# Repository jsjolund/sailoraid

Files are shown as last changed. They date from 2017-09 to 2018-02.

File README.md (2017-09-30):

# sailoraid
Sensor package for the Laser Pico sail boat

[BlueNRG (Old Bluetooth module) Datasheet](Docs/BlueNRG_Datasheet.pdf)

[SPBTLE (Bluetooth module) Datasheet](Docs/BlueNRG_Datasheet.pdf)

[EVA2235-H (GPS) Datasheet](Docs/EVA2235-H.pdf)

[LSM6DSL (Acc/Gyro) Datasheet](Docs/LSM6DSL.pdf)

[LSM303C (Acc/Mag) Datasheet](Docs/LSM303C.pdf)

[STM32F411 (MCU) Datasheet](Docs/STM32F411_Datasheet.pdf)

[STM32F411 (MCU) Reference Manual](Docs/STM32F411_Reference_Manual.pdf)

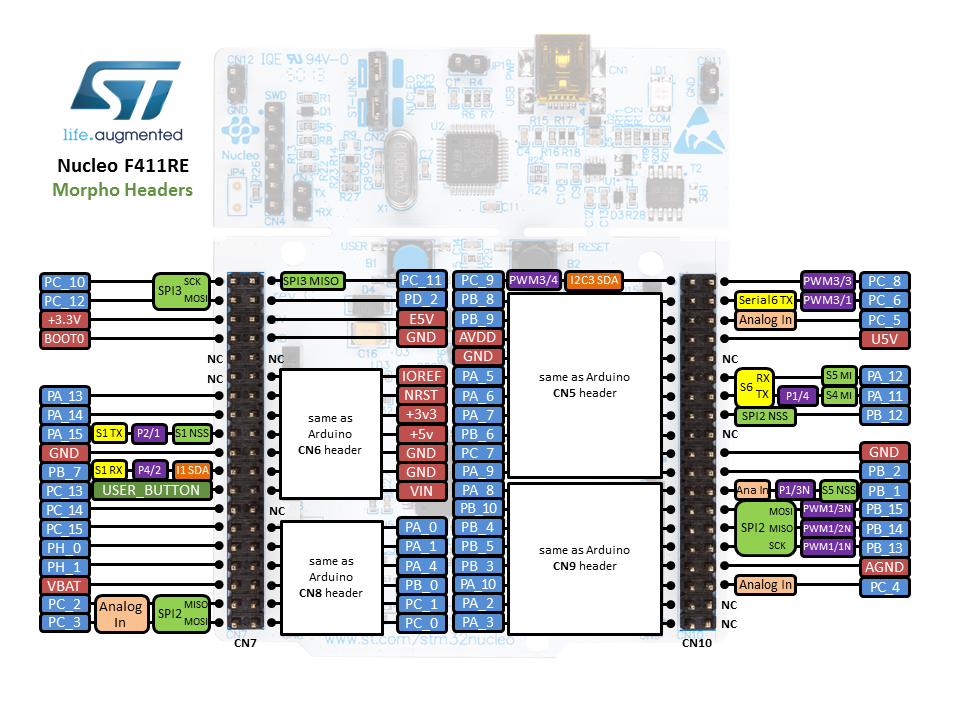
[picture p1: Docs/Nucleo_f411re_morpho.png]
Nucleo F411RE morpho pins


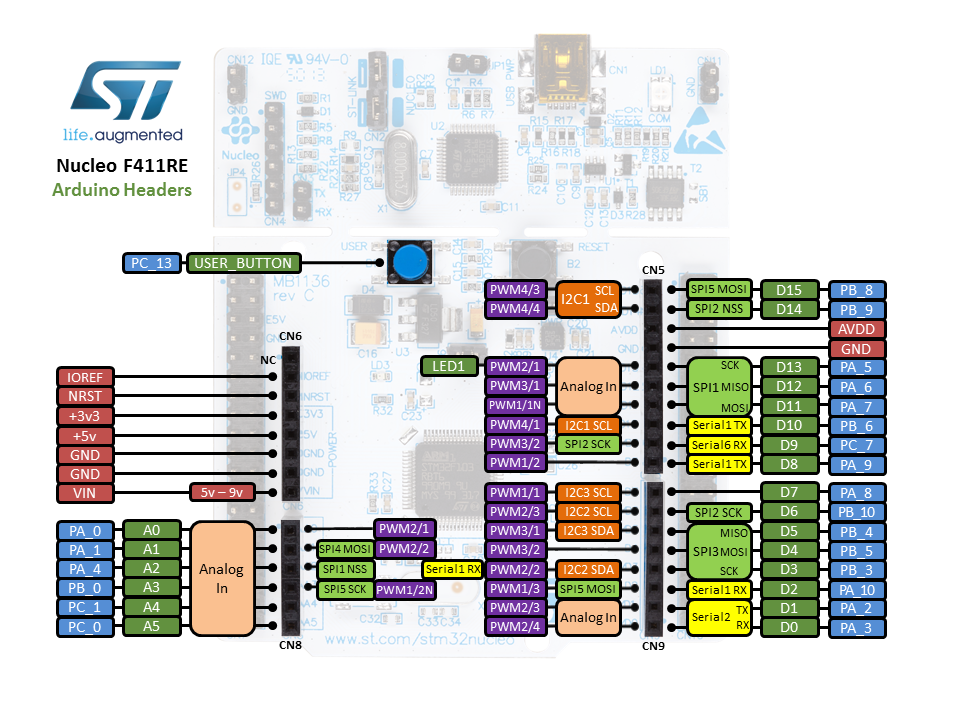
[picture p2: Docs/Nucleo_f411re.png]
Nucleo F411RE pins


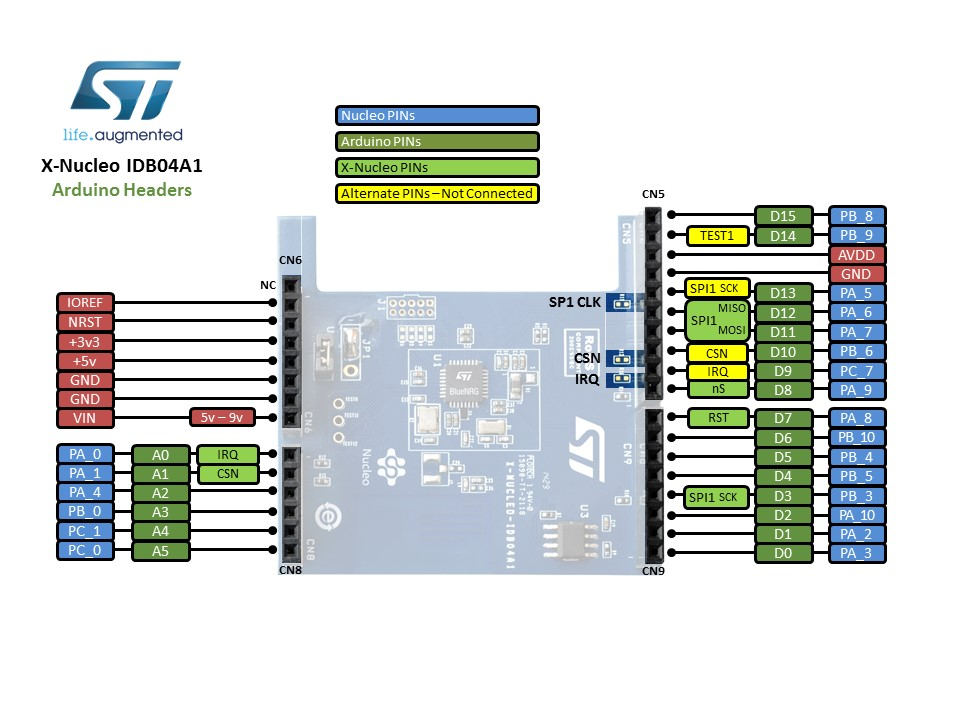
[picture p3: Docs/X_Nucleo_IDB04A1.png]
X Nucleo IDB04A1 pins


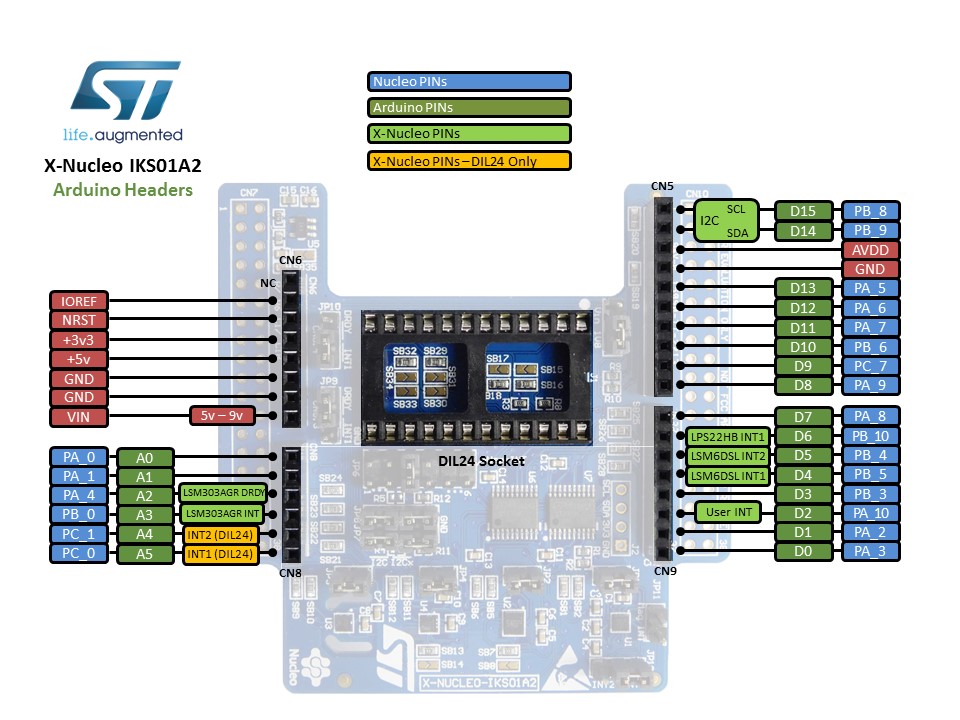
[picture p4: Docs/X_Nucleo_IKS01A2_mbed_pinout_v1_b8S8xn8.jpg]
X Nucleo IKS01A2 pins


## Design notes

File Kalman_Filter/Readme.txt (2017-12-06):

This was program was used for a dinghy (small boat), to achieve more accurate position and velocity. 

This is a program that uses an Inertial Navigation System (INS) and takes the difference between the INS and GPS data and feeds that to a Kalman filter. The error is then sent back to the INS to correct the next output. 

You can just run the code, using sim_script. But you have to link the folder "data", this since the data provided by the IMU and GPS is in that folder.
 
If you want to test with new data, open folder SERIAL_READ and run the main file. New data will be collected from the stm32,(assumed it has correct setup).
Then open folder DATA and run test_serial.m,
new vectors containing the logged data will be created, acc_x, acc_y, acc_z, gyr_x, gyr_y, gyr_z, longitude, latitude, velocity(gps), height and time. Don't forget to link the sensorLog.mat file which is created by the main file in SERIAL_READ. 
Moreover in folder DATA running data_script.m will generate calibration 
results which should be stored in calibration_res.mat.
 
Things that should be changed according to the hardware that the user uses. is the standard deviation in kalman_gps_ins.m file

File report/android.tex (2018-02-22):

\subsection{Android application}
\chapterauthor{Theolin, Henrik (Axelsson, Oskar)}
The main reason for this project is to give a sailor qualitative feedback and help in clearing the mind of the techniques required to achieve a smooth sail experience so that the sailor can focus on the joy of sailing.
A crucial part is to display the data in a manner that is easy to interpret and provide the help that the skipper needs.

To further increase the flexibility of the design, several different user layouts are implemented, that the user can switch between while running the application. This was determined to be a good way of increasing the chances that the user would find a preferable layout.

It was also determined that not only visual representation was enough, since the sailor needs to be in constant motion to counteract the forces applied on the ship by the wind and currents. This will make watching a screen to retrieve information somewhat difficult.
Other ways of representing data were implemented using text-to-speech where the sailor will get important information by sound as well as text
 Vibration is also implemented with different vibration sequences depending on different states of the ship.

\subsubsection{Software design}
A \gls{uml}\cite{uml} model of the system, see \autoref{android-uml}, was developed for an overview of the system implementation. The android system uses activities\cite{activity} to display content to the device screen. These activities have a life-cycle, see \autoref{android-activity}, that determine how data is accessed and displayed. What should be understood is that the application starts in a main activity, and switching to another activity is done by sending an intent that spawns as a child activity.
While the application is in the child activity the main activity is paused but the state is stored and when switching back from the child all data from the previous state is being accessed.
When the user returns from the child activity,  that activity is destroyed and all data is erased.
Sending data between activities is done using intents, to send an intent to a child activity is done by adding a bundle with a data object along with the intent to spawn the child activity.
Sending data back to the child activity is done by calling the method ``\emph{startActivityForResult}'', this allows the child to send a data packet as a result back to the parent. 
\begin{figure}[H]
\centering
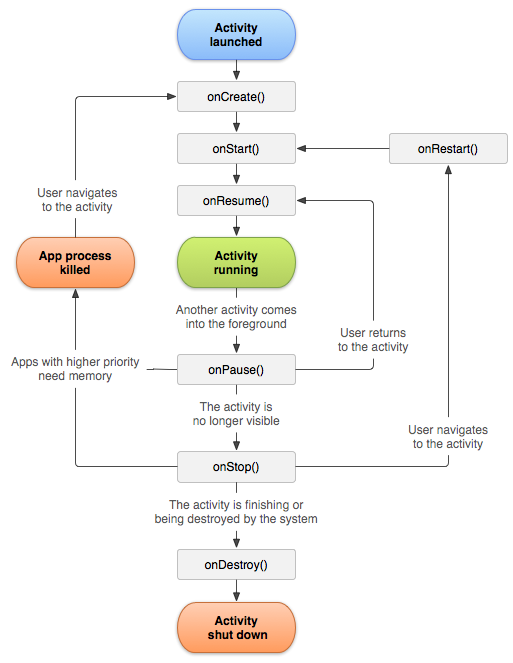
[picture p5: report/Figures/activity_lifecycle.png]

\captionsource{Activity lifecycle.}{ Author}
\label{android-activity}
\end{figure}

The Bluetooth connection and data logging class is implemented as a services\cite{android-service}. A service can be started by an activity and continue running until it is explicitly called to stop. This allows several activities to share resources and perform long-running operations in the background. The lifecycle of a service is seen in \autoref{android-service}.
\begin{figure}[H]
\centering
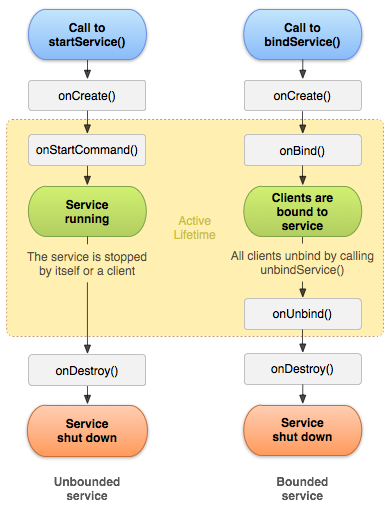
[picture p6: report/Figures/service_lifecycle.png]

\captionsource{Service lifecycle.}{Author}
\label{android-service}
\end{figure}

\subsubsection{Feedback}
For the feedback states in the application, there are some approximations, and simplifications made for easier implementation. As explained in \autoref{sec:physics}, the chapter about Physics of sailing, there are certain parameters that can be evaluated in different states of the dinghy. An extensive approximation is that there is no water movement in the implementations. The states implemented are
\begin{labeling}{alligator}
\item [Clear] - The dinghy holds good velocity and not heeling or drifting and with a good amount of pressure on the dagger-board
\item [Drift] - The dinghy is drifting perpendicular to the bearing while the dagger-board is in an upper position
\item [Heel] - The dinghy has high heel angle
\item [Reefing] - The dinghy has high heel angle and the pressure on the dagger-board is high
\item [Wrspeed] - The dinghys speed is above $65.45~\textrm{kn}$
\item [Lrspeed] - The dinghys speed is above $16.8~\textrm{kn}$
\item [Hike] - The dinghy has more then moderate heel angle and the pressure on the dagger-board is between medium and high
\item [Keelhaul] - The dinghy has an above moderate heel angle and the dagger-board is not in the lowest position
\item [Runninghigh] - The dinghy is sailing directly windwards with dagger-board high and low heel angle.
\item [Runninglow] - The dinghy is sailing directly windwards with dagger-board high and mid heel angle.
\item [Landcrab] - The dinghys speed is low.
\end{labeling}
Given these states, appropriate feedback can then be provided to the user. For handling states, a class called \emph{StateChecker} was implemented. This stores sensor values and check against limits defined at an interval that is also defined in the class. Depending on these states this class also determines what feedback that should be given.

\subsubsection{Visual Feedback}
It was determined that the visual feedback provided to the user was to include very little text information and would consist mainly of figures that changed position based on sensor data to give a good representation of what was going on with the dinghy. Because of different personal preferences, the ability to switch between different layouts is implemented. This is done by a simple swipe on the screen to toggle the view to the next layout. All layouts consists of a subset of views from the complete set including
\begin{labeling}{alligator}
\item [\ref{feedback-incline} \textbf{Incline}]  displays a ships relative incline against and artificial horizon.
\item [\ref{feedback-pressure} \textbf{Pressure}] moves a pin along a colored bar to represent high of low pressure applied on the dagger-board.
\item [\ref{feedback-compass} \textbf{Bearing}] rotates a compass to show the ship relative bearing against true north.
\item [\ref{feedback-map} \textbf{Map}] displays current location of the ship.
\item [\ref{feedback-height} \textbf{Speed}] displays a speedometer from a classical Swedish vehicle\cite{volvo} with a movable bar representing speed over ground.
\item [\ref{feedback-drift} \textbf{Drift}] is represented with a colored bar containing two arrows that moves to the relative drift direction to show the sailor if the ship was holding its set navigational reference.
\item [\ref{feedback-text} \textbf{Feedback}] a text that changes values based on the current state of the boat.
\item [\ref{feedback-sog} \textbf{Height}] of the dagger-board is represented with a visual dagger-board moving up and down along a graphical ruler.
\item [\ref{feedback-wave} \textbf{Wave frequency}] displays a wave moving towards a ship at a speed representing different period of the waves.
\end{labeling}

\begin{figure}[H] 
 	\centering
	\begin{minipage}[c]{0.6\textwidth}
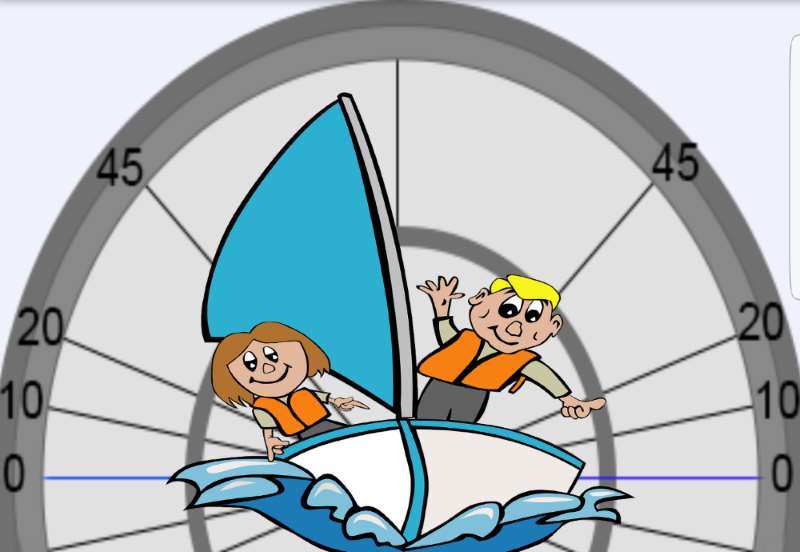
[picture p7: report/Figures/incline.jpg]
	
	\captionsource{Incline feedback view}{\url{https://pixabay.com/en/sailboat-children-playing-kid-girl-23801/}}
	\label{feedback-incline}
	\end{minipage}
	~
	\begin{minipage}[c]{.3\textwidth}
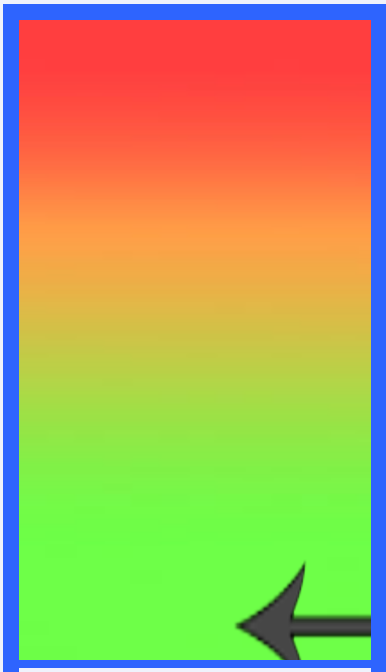
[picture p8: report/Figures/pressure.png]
	
	\captionsource{Pressure feedback view.}{Author}
	\label{feedback-pressure}
	\end{minipage}
\end{figure}
%
\begin{figure}[H]
	\centering
	\begin{minipage}[c]{0.55\textwidth}
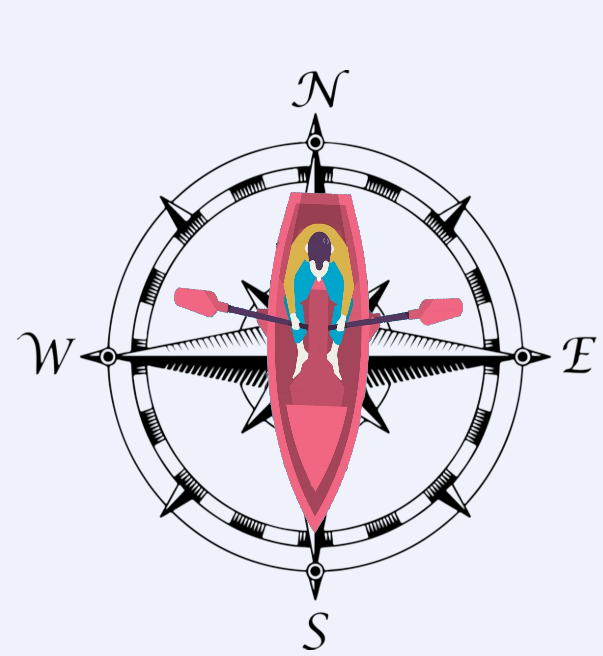
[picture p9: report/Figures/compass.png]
	
	\captionsource{Bearing feedback view.}{\url{http://www.pngall.com/compass-png}}
	\label{feedback-compass}
	\end{minipage}
	~
	\begin{minipage}[c]{0.35\textwidth}
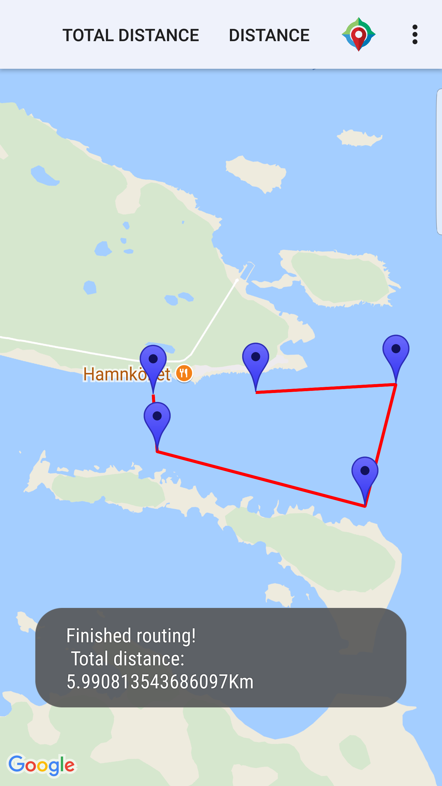
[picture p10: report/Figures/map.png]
	
	\captionsource{Map feedback view.}{Author}
	\label{feedback-map}
	\end{minipage}
\end{figure}
\begin{figure}[H]
	\centering
	\begin{minipage}[c]{0.35\textwidth}
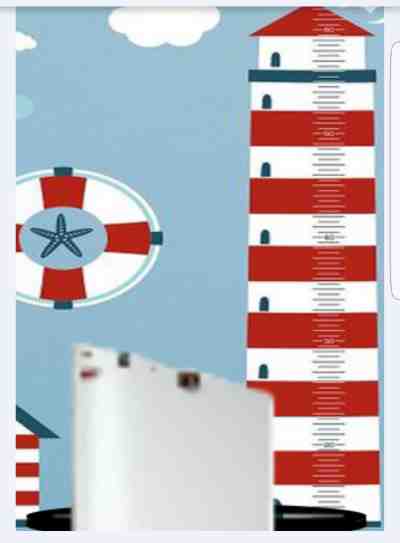
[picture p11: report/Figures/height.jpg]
	
	\captionsource{Dagger-board height view.}{\url{https://www.pinterest.se/pin/275212227218947579/}}
	\label{feedback-height}
	\end{minipage}
	~
	\begin{minipage}[c]{0.55\textwidth}
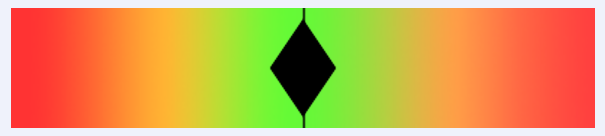
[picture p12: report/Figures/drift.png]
	
	\captionsource{Drift feedback view.}{Author}
	\label{feedback-drift}
	
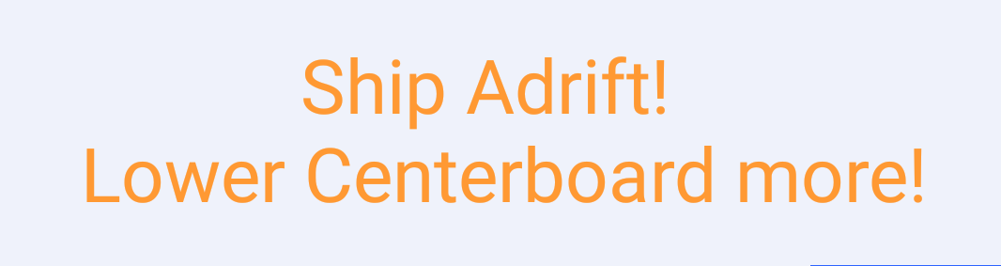
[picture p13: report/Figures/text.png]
	
	\captionsource{Text feedback view.}{Author}
	\label{feedback-text}
	\end{minipage}
\end{figure}
\begin{figure}[H]
	\centering
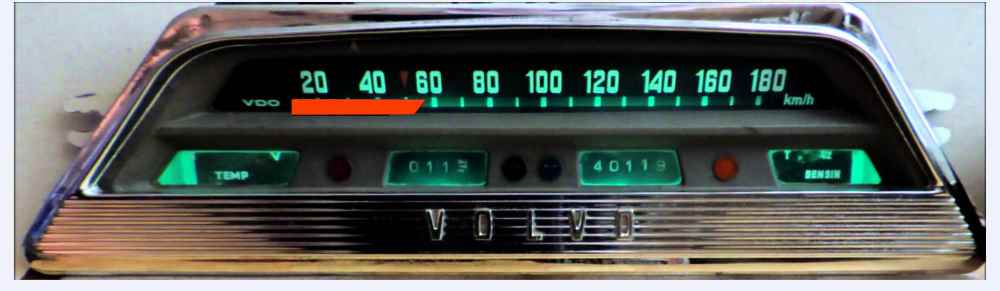
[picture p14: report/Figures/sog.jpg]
	
	\captionsource{Speed over ground view.}{\url{https://youtu.be/k8M6ZHplbIU}}
	\label{feedback-sog}
\end{figure}
\begin{figure}[H]
	\centering
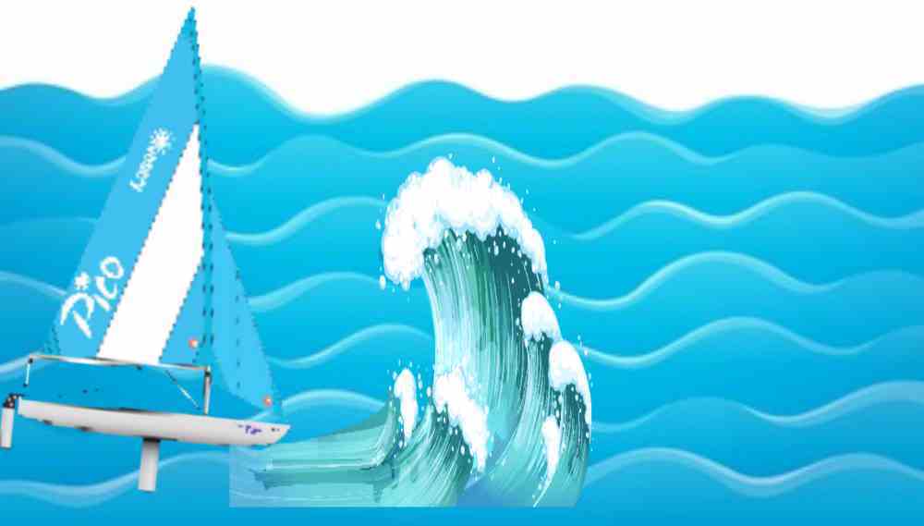
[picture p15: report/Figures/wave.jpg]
	
	\captionsource{Wave period feedback view.}{Author, Stockfresh\#2886857, Dreamstime\#33314341, \url{http://shorelinesailboats.com/product/pico/}}
	\label{feedback-wave}
\end{figure}
The figures were chosen at a development stage and improvements can easily be made by adding different \gls{png}\cite{png} files in android studio. They are implemented as \emph{GLSurfaceView}\cite{gl} so that updating the figures is be done by calling a \emph{requestRender} function, this improves the performance of the application when only updates to the figures are done when new sensor readings are received. To make the figure fit the application the \emph{GLSurfaceView} is extended into a \emph{RotatableGLView} that has the wanted features for rotation and positioning. Using these figures four different layouts are developed to give multiple choices for the user and is seen in figure \ref{feedback-layouts}. Switching between these layouts a \emph{swipeTouchListener} is implemented which allows the user to swipe across the screen to change the layout. Changing view the figures needs to be redrawn onto a new view matching the current layout, this is handled in the \emph{ViewDisplayer} class that contained all \emph{RotatableGLViews}.

\begin{figure}[H]
\centering
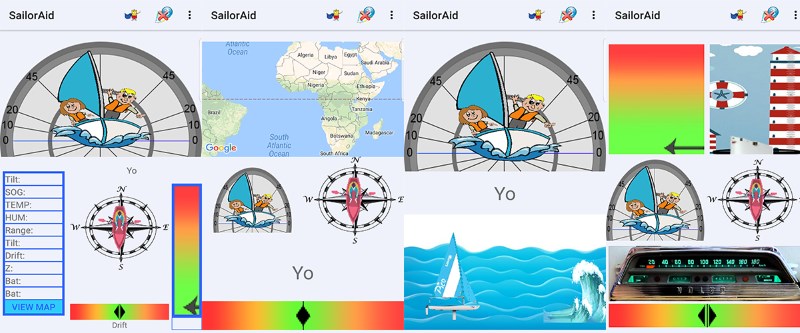
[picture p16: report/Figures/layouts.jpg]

\captionsource{Different layouts}{Author}
\label{feedback-layouts}
\end{figure}

\subsubsection{Audio feedback}
Based on values from the sensors, different states are implemented and for each state, a text is read out to the user. The feedback is implemented such that the audio feedback would continue even if the device is put into sleep mode. Handling the text to speech feature a \emph{Text-to-Speech}\cite{texttospeech} class is implemented as an inner class in \emph{StateChecker}. To prevent the speech to be interrupted preemptively an \emph{UtteranceProgressListener}\cite{utter} is used. 

\subsubsection{Haptic feedback}
Based on the same states as the audio feedback vibration is also implemented. The frequency and length of the vibrations are implemented in such a way each state has a unique signature that can be recognized by the sailor after some practice with the system. Handling the interval an \emph{IntervalVibrator} is implemented and run by the \emph{StateChecker}.

\subsubsection{Log}
The ability to analyze the sailing trip was determined to be an important feature for the user, so a logging function is implemented so data can be stored in the device internal storage. This is handled by the \emph{SailLog} class and these files can be read or deleted at a later stage, by the user. Storing a log is implemented such that the sailor would need to start a logging session after Bluetooth connection has been established to the ship. After the log is started it creates a file on the device internal storage and writes sensor data to the file at the same frequency as the data is transmitted by the system. While logging is active the device would continue to store information even if the device is put in sleep mode so that the sailor could choose to only log data and not view the information displayed on the screen. After the sailing trip is finished the sailor can read the saved log file and receive a summary of the trip (\autoref{log-summary}). More information from the log can be analyzed by reading graphs (\autoref{log-graph}) where the sensor data is shown with respect to time. These graphs are implemented such that the user is able to choose what graphs to be displayed on the device for improved comparability.
\begin{figure}[H]
	\centering
	\begin{minipage}[t]{0.3\textwidth}
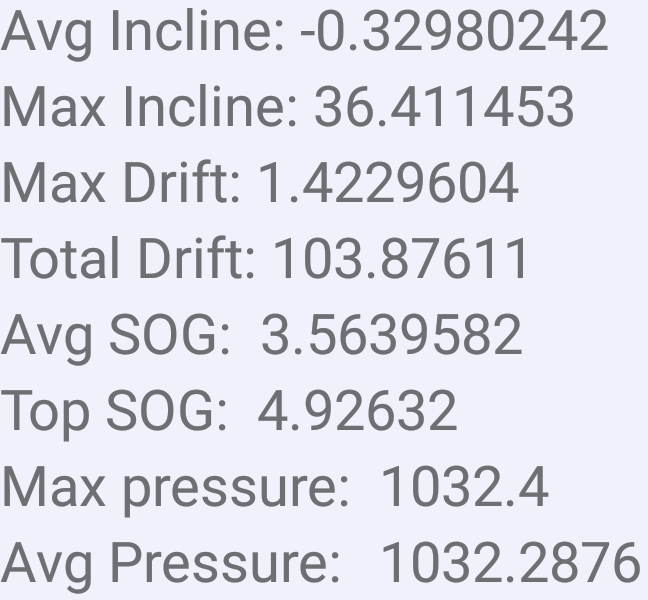
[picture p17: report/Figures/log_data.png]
	
	\caption{Log data summary example.}
	\label{log-summary}
	\end{minipage}
	~
	\begin{minipage}[t]{0.6\textwidth}
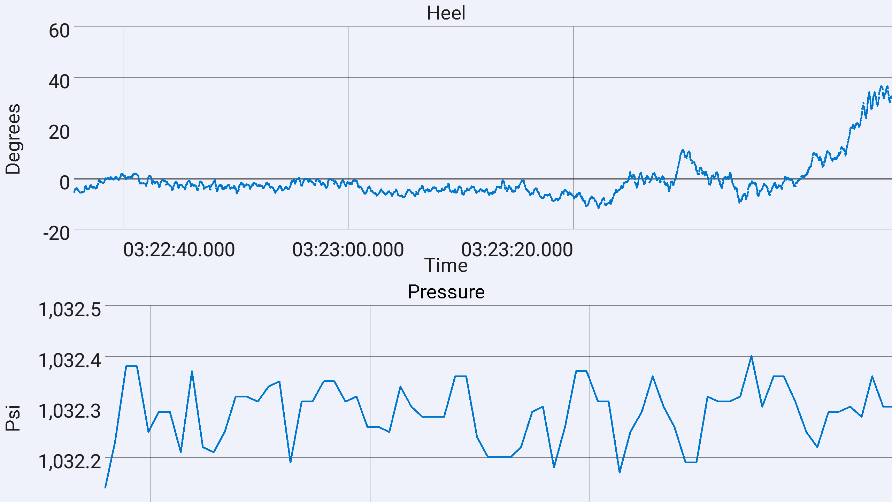
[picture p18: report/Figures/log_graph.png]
	
	\caption{Log graphs examples.}
	\label{log-graph}
	\end{minipage}
\end{figure}

\subsubsection{Bluethooth connection}
A list of all devices in the nearby area is displayed when the user decides to connect to the system, this adds flexibility to the user and allows for connection between multiple systems with different \gls{mac}. Scanning for nearby devices is done in the \emph{MainAcivity} and handled by the \emph{BTHandler} class. The application uses Bluetooth low energy technology to match the system implementation. This allows the device to receive notifications when the data is altered on the system and updates occurs in different frequencies for different types of data. To ensure a stable connection between the system and the device the connection class is implemented as an android service\cite{android-service}. This allows the device to keep the connection alive between different views and even when the device is put into sleep mode. All functionality regarding connecting and receiving data is implemented in the \emph{BTLEConnection} class and known characteristics and the determined unique GATT service identifiers are stored in the \emph{SampleGattAttributes} class.

\subsubsection{Map}
For the sailor to get more information about location two maps are implemented, one that is embedded into a layout in the \emph{FeedbackActivity} and the functionality of this is handled in the \emph{MapRunner} class, the other map is implemented in \emph{MapsActivity}. This could be improved by using the same class for both maps to achieve better readability and modifiability of the code. Both these implementations utilized the Google maps \gls{api}\cite{gmaps}, which can be used freely and the map service is highly accurate and suits our system well. Interaction with the maps can also be made quite easy which helped to make development faster. The sailor has the ability to see a path over the trip and the total distance traveled. Waypoints can be placed if the sailor wants to plan a certain trip in advance. The distance of the trip and the distance currently traveled is displayed to give the \gls{skipper} information on how long the trip is and how much of the trip is left to be sailed. A path to the nearest waypoint is shown to help navigation. When the sailor is close to the first waypoint the path to the next waypoint is shown. The waypoint route can also be viewed in the map of the \emph{FeedbackActivity} layout.

\subsubsection{Drift}
Calculating leeward drift is done by measuring the distance from an estimated destination point and the position received from the \gls{gps}. By using the \gls{gps} position and the ships bearing from the systems magnetometer a \textit{rhumb line}\cite{rhumb-line} is derived and the new estimated position is calculated with
%δ = d/R	(angular distance)
%φ2 = φ1 + δ ⋅ cos θ	
%Δψ = ln( tan(π/4 + φ2/2) / tan(π/4 + φ1/2) )	(‘projected’ latitude difference)
%q = Δφ/Δψ (or cos φ for E-W line)	
%Δλ = δ ⋅ sin θ / q	
%λ2 = λ1 + Δλ
\begin{align*}
  &\begin{aligned}
  \delta &= d/R 
  \end{aligned}\\
 &\begin{aligned}
  \varphi_2 &= \varphi_1 + \delta \cdot \cos{\theta}
  \end{aligned}\\
 &\begin{aligned}
  \Delta\psi = \ln { \bigg( \tan{\frac{n}{4} + \frac{\varphi_2}{2}} \bigg/ \tan{\frac{n}{4} + \frac{\varphi_1}{2}} \bigg)}
  \end{aligned}\\
 &\begin{aligned}
  q = \frac{\Delta\varphi}{\Delta\varphi}
  \end{aligned}\\
 &\begin{aligned}
  \Delta\lambda = \delta\cdot\sin\frac{\theta}{q}
  \end{aligned}\\
 &\begin{aligned}
  \lambda_2 = \Delta\lambda_1 + \Delta\lambda
  \end{aligned}\\
\end{align*}
where $R$ is the Earth's radius, $d$ is the distance traveled, $\theta$ is ships bearing, $\lambda_1$ and $\varphi_1$ is the point of origin in longitude and latitude. This new estimated position $\lambda_2$ and $\varphi_2$ is then compared to the next positional data from the \gls{gps} and the distance between these points is calculated using \emph{Equirectangular projection}\cite{equirectangular}.
%x = Δλ ⋅ cos φm
%y = Δφ
%d = R ⋅ √x² + y²
\begin{align*}
  &\begin{aligned}
  x = \Delta\lambda \cdot \cos\frac{\Delta\varphi}{2}
  \end{aligned}\\
 &\begin{aligned}
  y = \Delta\varphi
  \end{aligned}\\
 &\begin{aligned}
  d = R\cdot\sqrt{x^2+y^2}
  \end{aligned}\\
\end{align*}
where $\Delta\lambda$ and $\Delta\varphi$ are the differences in longitude and latitude for two location points. This function has high performance gain but is less accurate over large distances then, e.g., the \emph{Haversine formula}\cite{haversine}. Since for this function, only small changes in distance are calculated the accuracy is more than adequate. A problem with this way of calculating leeward drift is the accuracy of the \gls{gps} readings and to get a good bearing the idea was to make use of the magnetometer though the accuracy of that is also far from perfect. This combined with the fact that a small deviation of a couple of degrees results in a large drift resulted in large errors in leeway drift. The solution was to use the directional data sent from the \gls{gps} module which calculates direction based on last positional data. This solution works well for progress in the forward direction and when fast sideways motion is detected the estimated position will be along the same vector as the previous direction. However, for constant drift sideways this approach will display that no drift was taking place. This calculation is handled by the \emph{Locator} class.

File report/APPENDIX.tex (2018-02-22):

\section{Large Figures}\label{sec:app}

\subsection{Schematic of sensorboard}\label{app:schemmain}
%Image of schematic(s) (Rev 3)
\begin{figure}[h]
	\centering
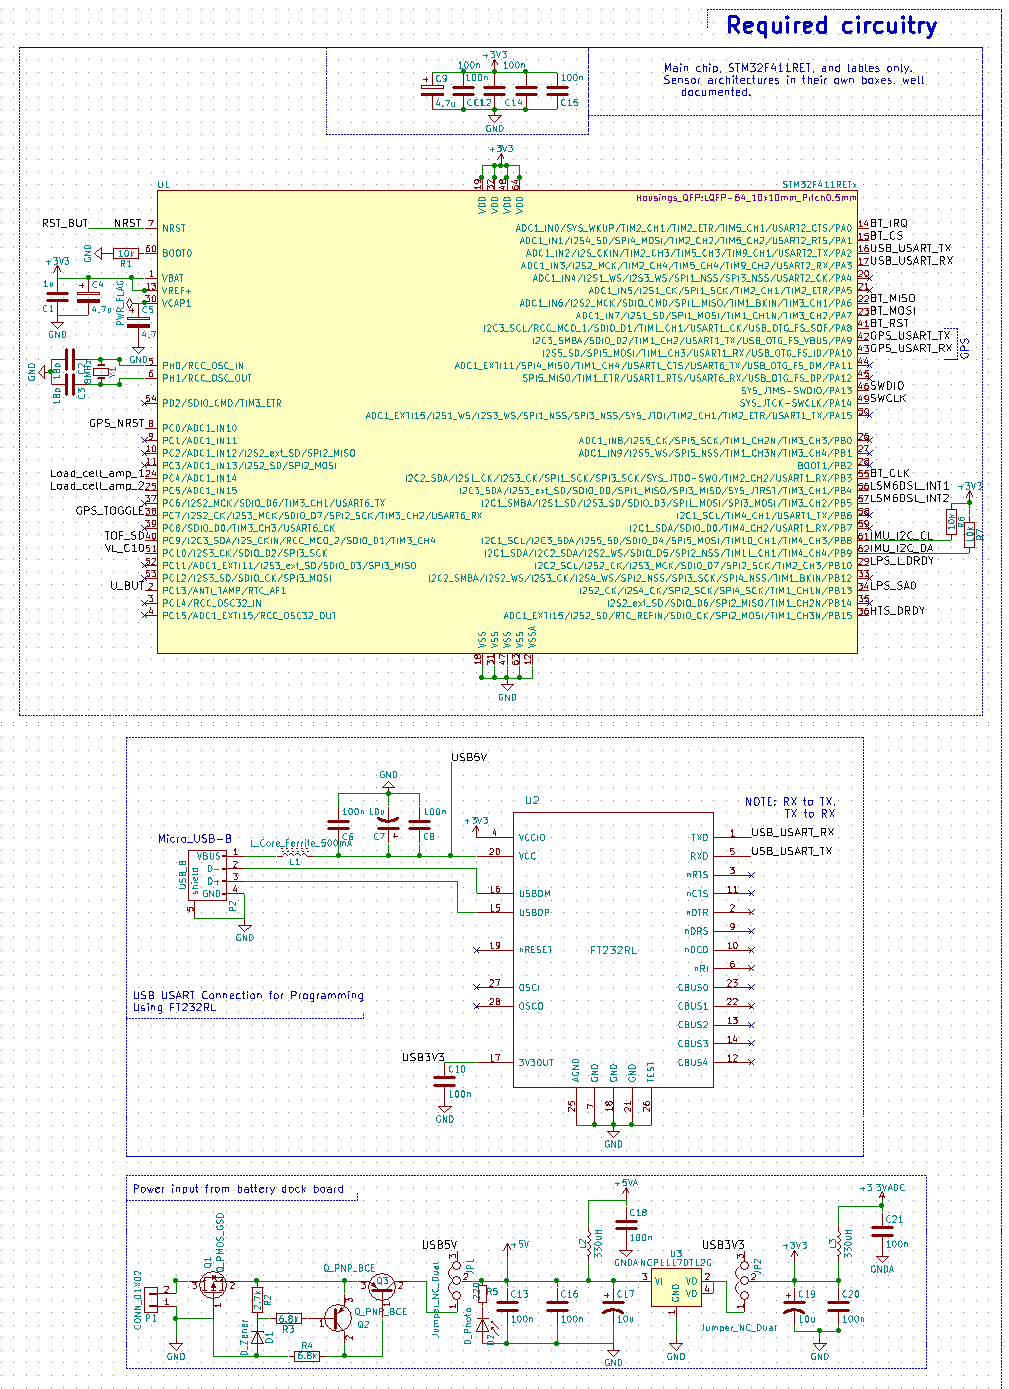
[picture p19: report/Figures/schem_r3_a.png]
    
	\captionsource{Schematic of revision 3, part a: Required circuitry.}{Author}
	\label{fig:schr3a}
\end{figure}
\begin{figure}[h]
	\centering
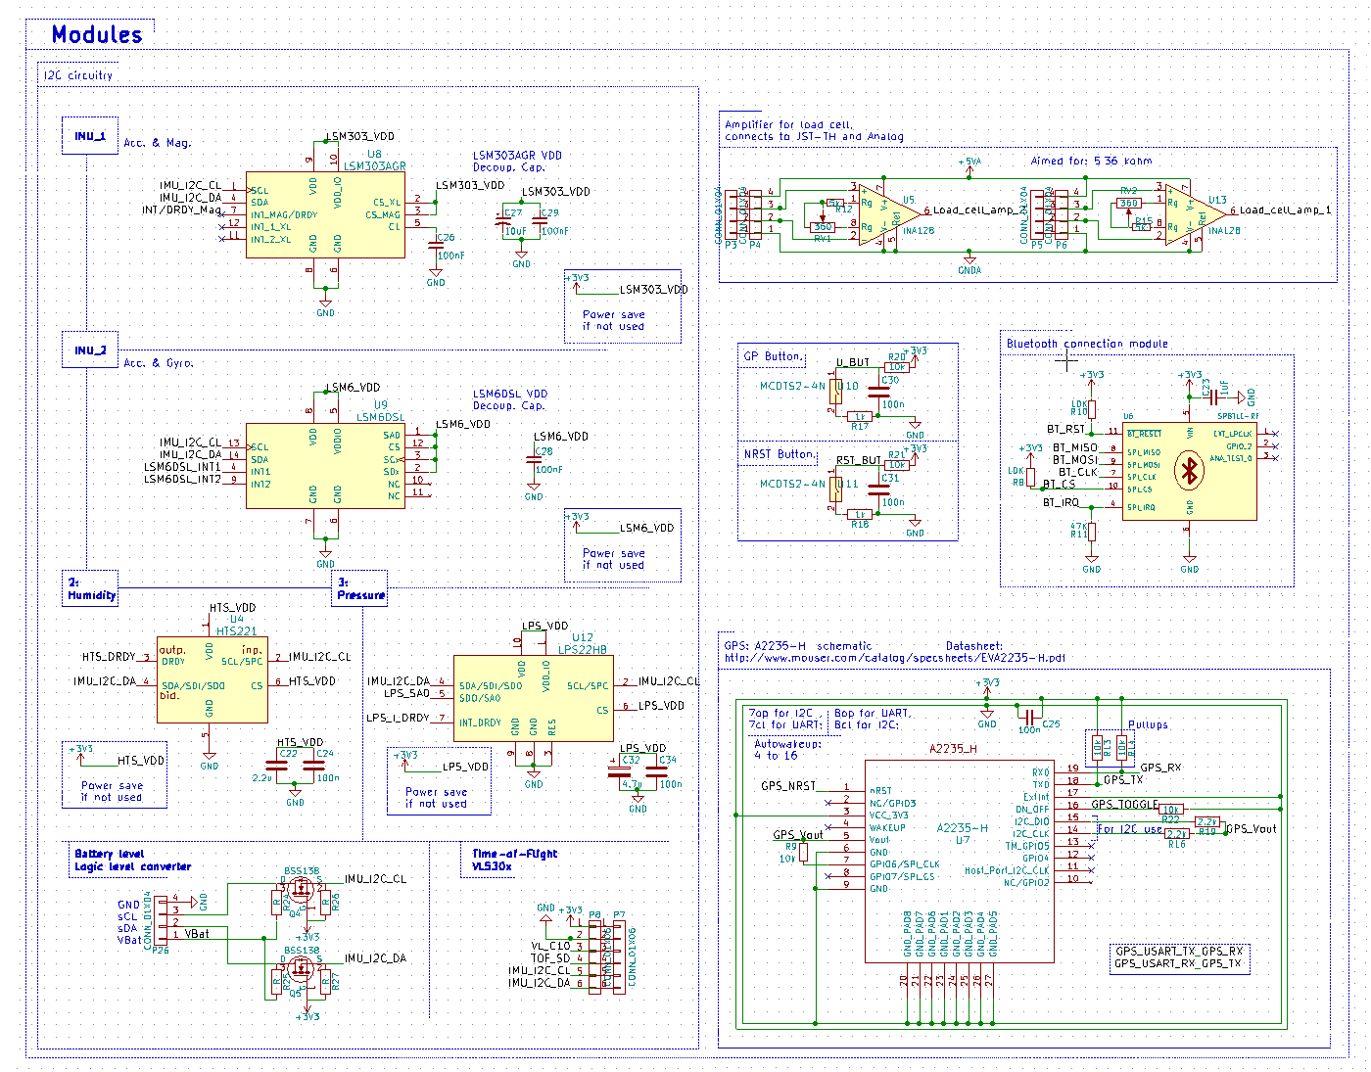
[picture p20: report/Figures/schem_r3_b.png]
    
	\captionsource{Schematic of revision 3, part b: Modules.}{Author}
	\label{fig:schr3b}
\end{figure}
\begin{figure}[h]
	\centering
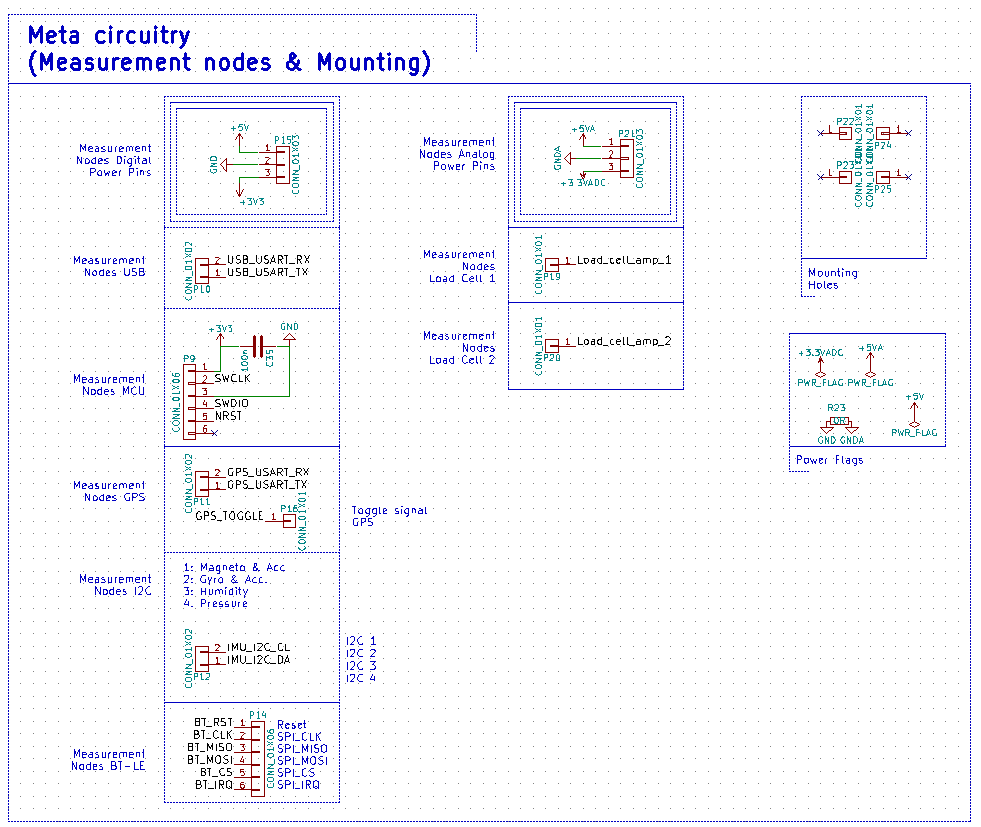
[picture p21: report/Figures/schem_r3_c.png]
    
	\captionsource{Schematic of revision 3, part c: Meta circuitry.}{Author}
	\label{fig:schr3c}
\end{figure}

\clearpage
\subsection{Schematic of \gls{bms}}\label{app:bms}
\begin{figure}[h]
	\centering
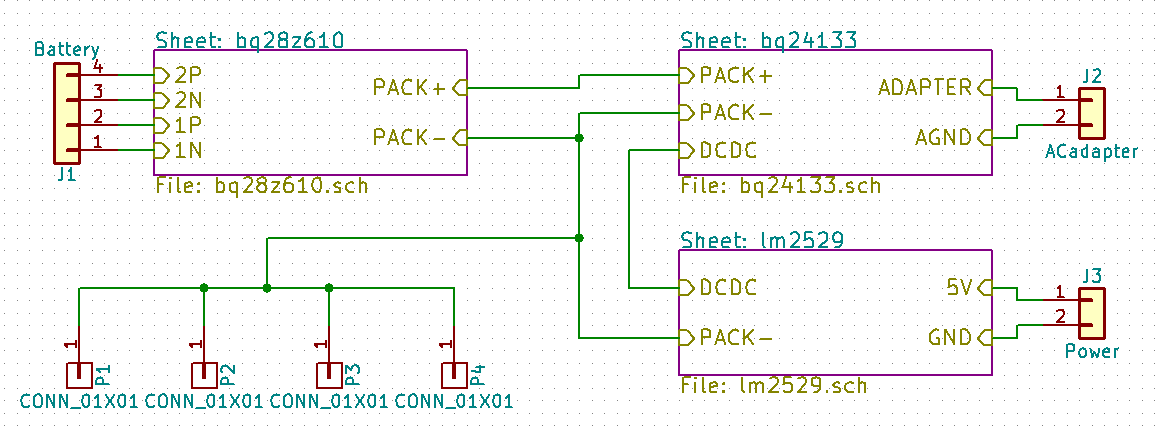
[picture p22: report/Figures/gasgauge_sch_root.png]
    
	\captionsource{Root schematic of \gls{bms} circuitry.}{Author}
	\label{fig:schbmsr}
\end{figure}
\begin{figure}[h]
	\centering
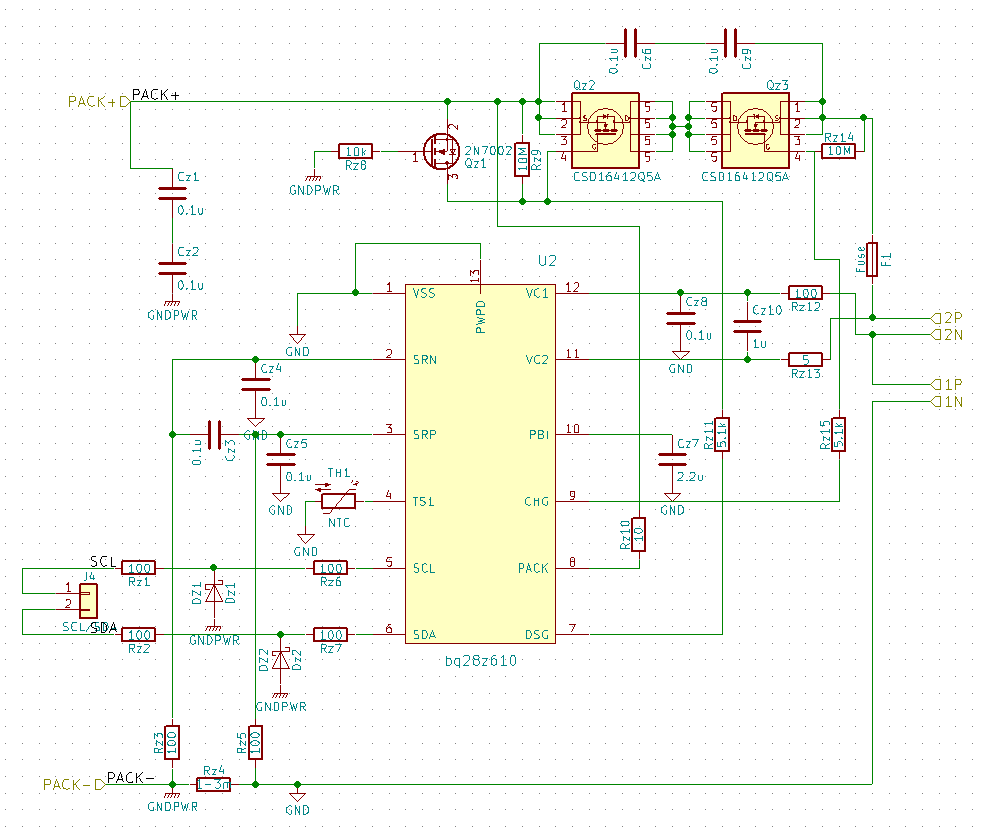
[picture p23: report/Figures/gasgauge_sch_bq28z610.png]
    
	\captionsource{Schematic of \gls{bms}, part a: bq28z610.}{Author}
	\label{fig:schbmsr}
\end{figure}
\begin{figure}[h]
	\centering
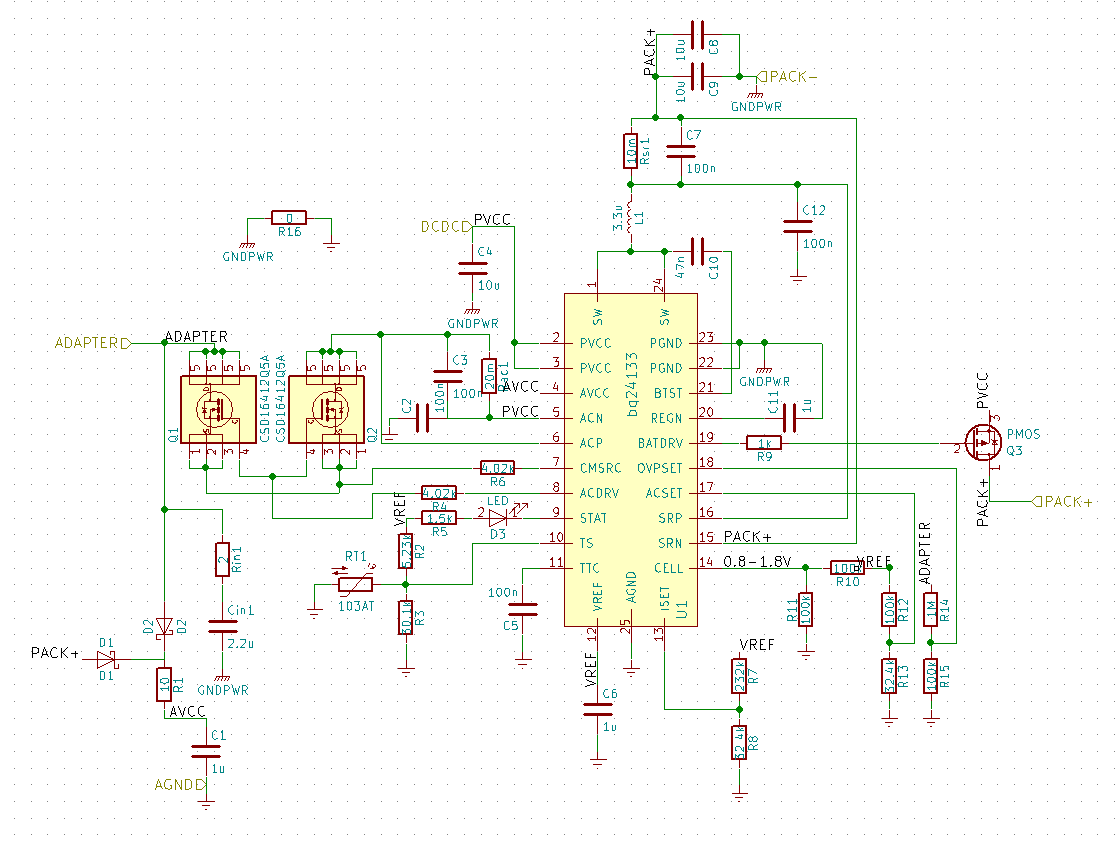
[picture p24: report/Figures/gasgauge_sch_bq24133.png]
    
	\captionsource{Schematic of \gls{bms}, part b: bq24133.}{Author}
	\label{fig:schbmsr}
\end{figure}
\begin{figure}[h]
	\centering
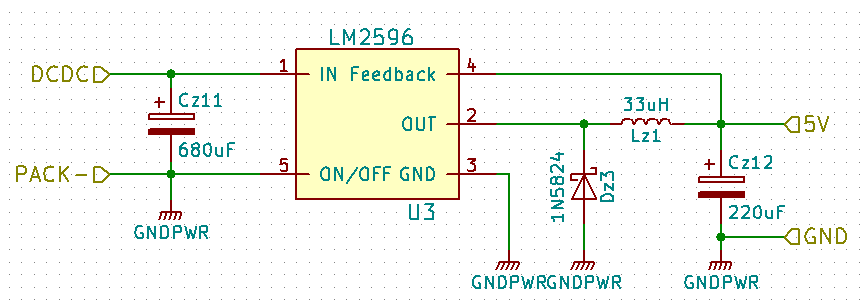
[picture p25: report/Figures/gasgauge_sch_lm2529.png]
    
	\captionsource{Schematic of \gls{bms}, part c: lm2596.}{Author}
	\label{fig:schbmsr}
\end{figure}

\clearpage
\subsection{CubeMX software}\label{sec:app:mxc}
% Image of CubeMX software
\begin{figure}[tbh]
	\centering
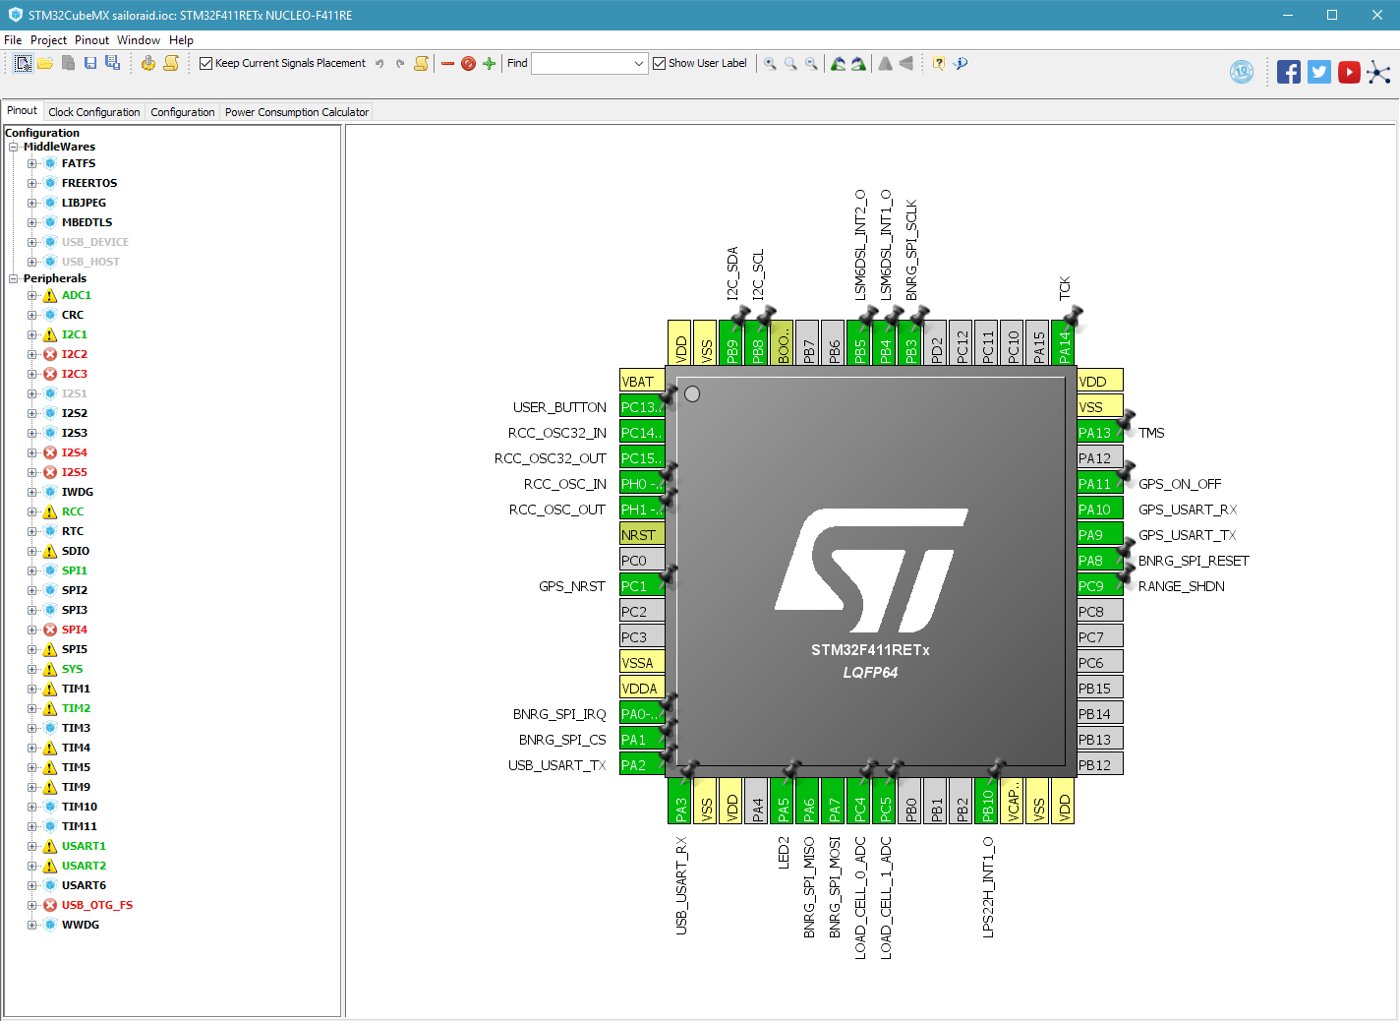
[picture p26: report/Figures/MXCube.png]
    	
	\captionsource{CubeMX software}{Author}
	\label{fig:mxc}
\end{figure}

\clearpage
\subsection{UML model}
\begin{figure}[H]%Can this be put in the Appendix? It is very large and detailed.
	\centering
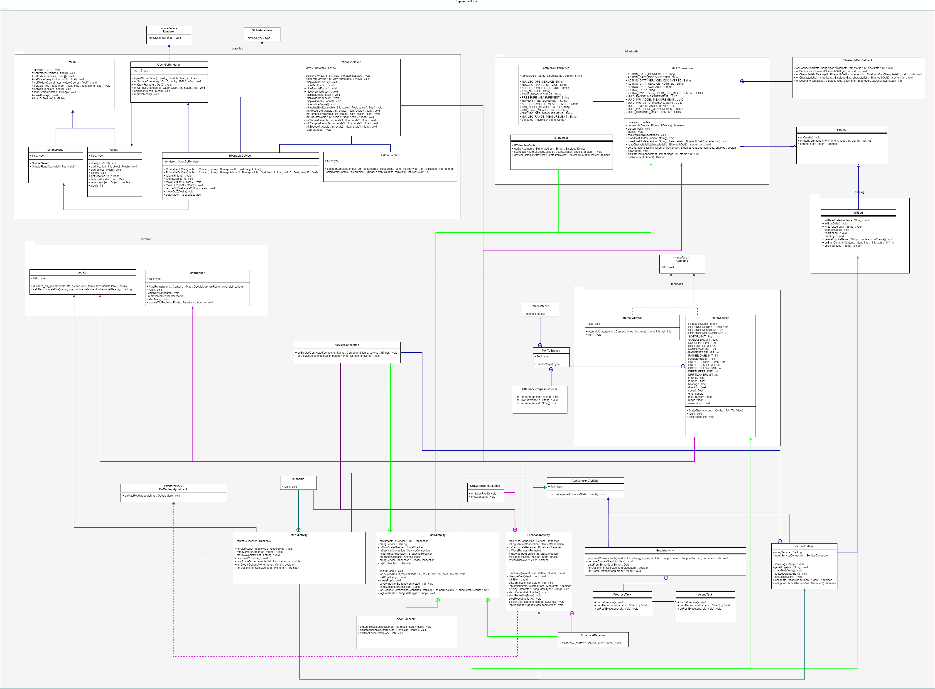
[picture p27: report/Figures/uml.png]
	
	\caption{\gls{uml} model.}
	\label{android-uml}
\end{figure}

\clearpage
\subsection{Casing Dimensions}
\begin{figure}[htb]
	\centering
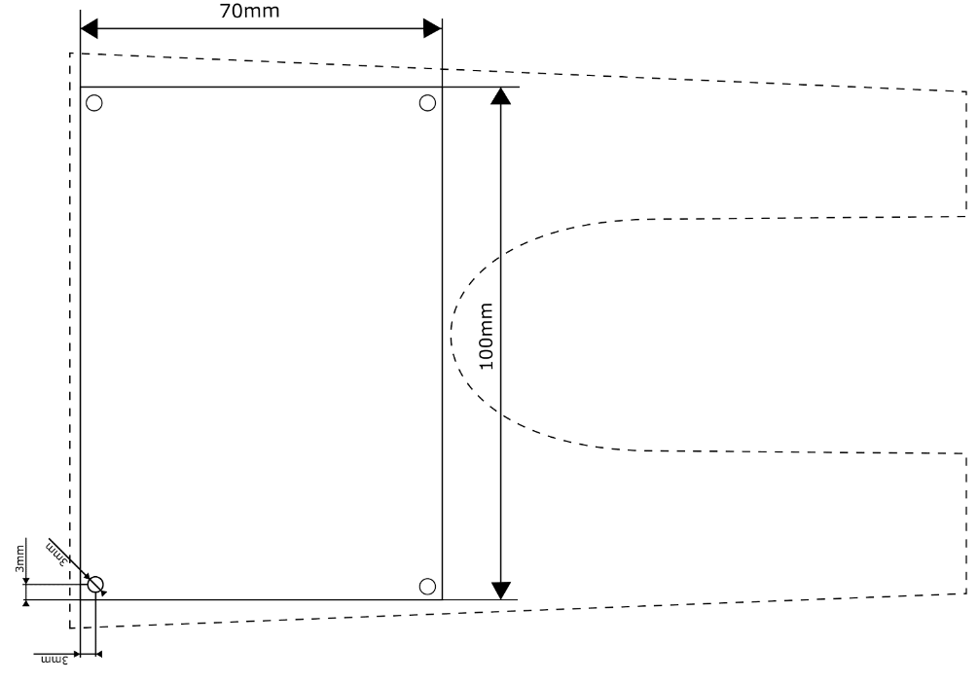
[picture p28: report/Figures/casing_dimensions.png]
    
	\captionsource{System enclosure shape and dimensions}{Author}
	\label{fig:casdim}
\end{figure}

\clearpage
\section{Lists}
\subsection{Bill of Materials: Main \gls{pcb}}
\begin{center}
\begin{tabular}{|l|l|c|}
	\hline
	\bf{Main Board Components} & \bf{Package} & \bf{Quantity} \\
	\hline
	\emph{Capacitors:} & & \\
	\hline
	18p & 0805 & 2 \\
	\hline
	100n & 0805 & 21 \\
	\hline
	1u & 0805 & 2 \\
	\hline 
	2.2u & 0805 & 1 \\
	\hline 
	4.7u & 0805 & 4 \\
	\hline 
	10u & Electrolytic SMD 5x5.3 & 6 \\
	\hline
	\emph{Resistors:} & & \\
	\hline
	220 & 0805 & 1 \\
	\hline
	1k & 0805 & 2 \\
	\hline
	1k & potentiometer & 2 \\
	\hline
	2.2k & 0805 & 2 \\
	\hline
	2.7k & 0805 & 1 \\
	\hline
	5k & 0805 & 2 \\
	\hline
	6.8k & 0805 & 2 \\
	\hline
	10k & 0805 & 11 \\
	\hline
	47k & 0805 & 1 \\
	\hline
	\emph{Inductors:} & & \\
	\hline
	1.5u & 1206 & 1 \\
	\hline 
	330u & Radial 200mil Pin Pitch & 2 \\
	\hline 
	\emph{Integrated Circuits:} & & \\
	\hline
	STM32F411RE & LPQF64 & 1 \\
	\hline 
	SPBTLE-RF & Custom & 1 \\
	\hline
	A2235-H & Custom & 1 \\
	\hline
	FT232R & SSOP-28 & 1 \\
	\hline
	LSM6DSL & LGA-14L & 1 \\
	\hline
	LSM303AGR & LGA-12 & 1 \\
	\hline
	HTS221 & HLGA-6L & 1 \\
	\hline
	LPS22HB & HLGA-10L & 1 \\
	\hline
	INA128 & SOIC-8 & 2 \\
	\hline
	LM1117-3.3 & SOT-223 & 1 \\
	\hline
	\emph{Semiconductors:} & & \\
	\hline
	P-MOS PMV65XP & SOT-23 & 1 \\
	\hline
	PNP BJT FMMT718 & SOT-23 & 2 \\
	\hline
	Zener Diode, 5.6V & SOD-323 & 1 \\
	\hline
	Green LED & ø2.5mm 100mil pitch& 1 \\
	\hline
	\emph{Others:} & & \\
	\hline
	Tactile SMD Button & & 2 \\
	\hline
	8MHz Crystal & & 1 \\
	\hline
	Micro USB-B & & 1 \\
	\hline
	Straight 6-Pin Header & 100mil pitch & 1 \\
	\hline
	Straight 3-Pin Header & 100mil pitch & 2 \\
	\hline
	Pin Jumper & & 2 \\
	\hline
\end{tabular}
\end{center}

\clearpage
\subsection{Bill of Materials: Battery Management \gls{pcb}}
%\begin{center}
\begin{tabular}{|l|l|c|}
	\hline
	\bf{Battery Management Circuit} & \bf{Package} & \bf{Quantity} \\
	\hline
	\emph{Capacitors:} & & \\
	\hline
	47n & 0603 & 1 \\
	\hline
	100n & 0603 & 13 \\
	\hline
	1u & 0603 & 4 \\
	\hline
	2.2u & 0603 & 2 \\
	\hline
	10u & 1206 & 3 \\
	\hline
	220u & Electrolytic SMD 6.3x5.8 & 1 \\
	\hline
	680u & Electrolytic SMD 6.3x5.8 & 1 \\
	\hline
	\emph{Resistors:} & & \\
	\hline
	0 & 0603 & 1 \\
	\hline
	1-3m & 2512 & 1 \\
	\hline
	10m & 2512 & 1 \\
	\hline
	20m & 2512 & 1 \\
	\hline
	2 & 2010 & 1 \\
	\hline
	5 & 2512 & 1 \\
	\hline
	10 & 0603 & 1 \\
	\hline
	10 & 1206 & 1 \\
	\hline
	100 & 0603 & 7 \\
	\hline
	100 & 2512 & 1 \\
	\hline
	1k & 0603 & 1 \\
	\hline
	1.5k & 0603 & 1 \\
	\hline
	4.02k & 0603 & 2 \\
	\hline
	5.1k & 0603 & 2 \\
	\hline
	5.23k & 0603 & 1 \\
	\hline
	10k & 0603 & 1 \\
	\hline
	30.1k & 0603 & 1 \\
	\hline
	32.4k & 0603 & 2 \\
	\hline
	100k & 0603 & 4 \\
	\hline
	232k & 0603 & 1 \\
	\hline
	1M & 0603 & 1 \\
	\hline
	10M & 0603 & 2 \\
	\hline
	103AT & Axial Standing 100mil Pitch & 2 \\
	\hline 
	\emph{Inductors:} & & \\
	\hline
	3.3u & 7.3x7.3mm SMD & 1 \\
	\hline
	33u & 12x12mm SMD & 1 \\
	\hline
	\emph{Integrated Circuits:} & & \\
	\hline
	BQ24133 & VFQN-24 & 1 \\
	\hline
	BQ28Z610 & S-PDSO-N12 & 1 \\
	\hline
	LM2529 & TO-263-5 & 1 \\
	\hline
	\emph{Semiconductors:} & & \\
	\hline
	Schottky Diode & SOD-323 & 4 \\
	\hline
	1N5824 & Axial 10.16mm Pitch & 1 \\
	\hline
	N-MOS CSD16412Q5A & TDSON-8-1 & 4 \\
	\hline
	Red LED & ø3mm Radial 100mil Pitch & 1 \\
	\hline
	2N7002 & SOT-23 & 1 \\
	\hline
	Power P-MOS & SOT-23 & 1 \\
	\hline
\end{tabular}
%\end{center}
%Image of circuit board(s) are sectionlocals labled as "fig:pcbr*"
%Local. Image of casing
%INSERT Image of complete/mounted system

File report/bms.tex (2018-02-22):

% !TEX encoding = IsoLatin9
\subsection{Introduction}
Lithium-ion batteries packs large amounts energy in a small package and can power systems for long periods before recharge is needed. But because of the high energy density they have to be handled with care. Beyond protection a \gls{bms} can be used to report battery percentages and remaining capacity. The specific type of battery used in this project is \emph{ICR18650}.

\subsection{Lithium-ion Battery Composition}
Lithium-ion batteries are similar to other batteries in the way that they work by the same electrochemical principles. Though there are differences that has to be taken into account when developing a battery management system.

A lithium-based battery does not have any metallic lithium in it, instead, lithium ions are intercalated in the electrode material. Due to the highly reversible properties of the intercalation, \gls{lion} batteries have greater electrode stability and cycle life compared to other electrochemical processes. They have high coulombic efficiency in all states of charge. Self-discharge is also slower in \gls{lion} batteries which makes them useful in situations where they may not be used for extended periods and are expected to work once the system turns on.

Memory effects present in other chemistries cause gradual loss of capacity if not discharged properly are not present in lithium-ion batteries and makes the usage more flexible. Trickle charging is a common method of determining the \gls{soc}, but lithium-ion batteries lead to overcharging and may damage the battery.

Water-based electrolytes are common in most batteries but as electrolysis begins at two volts in water and the voltages present in lithium cells are higher than that, that is not possible. Organic solvents are instead used. These solvents are flammable and have high vapour pressures. The increased performance of \gls{lion} batteries comes with higher severity if something would happen to go wrong, so they have to be handled with extra care.

One of the most common form factors is the cylindrical cell referred to as \emph{18650}. That is $18~\textrm{mm}$ in diameter and $65~\textrm{mm}$  in length \cite[p.26-27]{book}. \autoref{fig:cellstruct} displays the parts that build up such a cylindrical cell.

\begin{figure}[H]
	\centering
	
	\captionsource{\gls{lion} 18650 battery structure.}{\url{http://chrishillsethenterprises.com/battery/about-lithium-ion-battery-manufacturing/}}
	\label{fig:cellstruct}
\end{figure}

\subsection{Charging}
Charging can be either controlled by a separate charger or by the management system itself. Whichever implementation is used these are the battery management system must make\cite{book}[p.111]:

\begin{itemize}[noitemsep]
	\item Charging rate
	\item Life of the batteries
	\item Charge termination
\end{itemize}

The preferred way of charging \gls{lion} batteries is \gls{cccv}-charging. The charge cycle begins with a constant current after the specification of the battery in use. This current is supplied continually until the battery has reached its end-of-charge-voltage. Then charging is switched over to constant voltage mode and the current will taper off as the cell reaches its full capacity. Charging is then terminated when the current goes below a predefined value. \autoref{fig:cccv} displays the process. As the voltage curve is steep when the battery reaches its full capacity precise regulation is needed to prevent overcharging\cite{cccv}\cite[p.111]{book}.

\begin{figure}[H]
	\centering
	
	\captionsource{Behaviour of \gls{cccv}-charging.}{\url{http://www.gne2010.com/productitem/1122}}
	\label{fig:cccv}
\end{figure}

\subsection{Balancing}
Unlike other types of batteries that have a lower coulombic efficiency, lithium-ion batteries do not self-balance during a charge cycle. Without the ability to transfer charge, capacity will be limited to the battery with the lowest capacity in a series configuration. Knowing the capacity in real-time increases the efficiency of the balancing process.
Cell balancing is used for one or more of these purposes\cite[p.183]{book}:

\begin{itemize}[noitemsep]
	\item Minimize charge difference
	\item Maximize available battery power
	\item Maximize available battery energy
\end{itemize}
\noindent \autoref{fig:variations} Shows the variations that can occur between cells in a series stack.
%Note \ref is used here since \autoref sadly doesn't automatically uppercase beginning of sentences

\begin{figure}[H]
	\centering
	 
	\captionsource{Series stack cell variations.}{Weicker, P., A Systems Approach to Lithium-ion Battery Management}
	\label{fig:variations}
\end{figure}

\subsection{18650 Basic Safety}
There are both protected and unprotected 18650 batteries. Protected ones include three basic safety features\cite{webpage}:
\begin{itemize}[noitemsep]
	\item \gls{ptc}
	\item \gls{cid}
	\item \gls{pcb}
\end{itemize}

\noindent A \gls{ptc} is a resistor that increases resistance when temperature rises, thus protecting against over temperatures. It will automatically reset when the temperature goes down.
\gls{cid} or pressure valve disables the battery permanently if the vapor pressure inside the cell becomes too high. Preventing further swelling and possible fire.
The \gls{pcb} protects against over discharge, overcharge, and overcurrent. Depending on the design, it will be reset when there is no fault condition any more or when it is placed in a charger.  

\autoref{fig:protection} is an illustration of a protected \gls{lion} battery. The pressure valve on the left side also breaks the connection between the internal and external positive pole which is why it is called \gls{cid} or current interrupt device.

\begin{figure}[H]
	\centering
	
	\captionsource{A protected 18650 cell.}{\url{http://www.lygte-info.dk/info/battery\%20protection\%20UK.html}}
	\label{fig:protection}
\end{figure}

\subsection{Safety and Abuse Conditions}
Due to the differences between \gls{lion} batteries and other batteries, and their higher capacity they are more susceptible to faults when abused. Follow is a list of abuse conditions and their implications\cite[p.35]{book}.

\begin{itemize}
\item Overcharge occurs when \gls{soc} is greater than $100\%$. Cell voltage will begin to rise fast and may damage load or monitoring circuitry. Irreversible degradation inside the cell will occur. Both single large events and many small events cause degradation. Unlike in other chemistries, small currents causes this. Leading to thermal runaway, cell swelling, and venting. Begins somewhere between $3.75~\textrm{V}$ and $4.2~\textrm{V}$ depending on the cell.
\item Over-discharge occurs when \gls{soc} reaches below $0\%$, the voltage decreases fast and can even be reversed if discharge current is too high. A reversed voltage may result in damaged monitoring circuitry. Internal damage includes dissolution of the negative terminal foil. Self-over-discharge cannot be prevented. Minimum voltage before over discharge occurs is between $1.8-2.5~\textrm{V}$ depending on the cell.
\item High temperatures increase cell degradation which in turn causes thermal runaway further increasing inside temperatures. Excessive temperatures activate exothermic chemical reactions in the organic solvents. Releasing high amounts of energy that leads to venting of cell contents, fire or explosion.
\item Low temperatures can cause plating on of metal lithium onto the electrodes which Leeds to irreversible capacity loss and possibly metallic “dendrite” growth. Dendrites can penetrate the separator leading to internal short circuits. Low temperatures also increase cell impedance thus limiting discharging capabilities. Charging below $0\degree C$ is not recommended, although some cells allow temperatures below $-10\degree C$.
\item Overcurrent, both during dis- and re-charging can cause the same type of problems as with general over- and under-charge conditions, at the same time high currents increases temperature. The maximum current allowed for is a function of \gls{soc} and temperature. Even though temperature would be held at acceptable levels, the amount of current will still be limited by the number of ions the negative terminal can receive at any given moment.
\item Age is a major factor when it comes to Li-ion batteries, the risk of failure increases with age. Monitoring and estimating remaining battery lifetime can be done and is expressed in \gls{soh}.
\end{itemize}

\subsection{Determining \gls{bms} Specifications}
A flow chart was used to determine the power requirements of the system powered by the batteries. As is seen in \autoref{fig:powerinput}. The particular \gls{mcu} used runs on $3.3~\textrm{V}$ and the sensors that were chosen would run on $3.3~\textrm{V}$ and $5.5~\textrm{V}$ respectively, so those requirements where definite. There were thoughts about adding a display that might have needed $12~\textrm{V}$, therefore the light blue block in \autoref{fig:powerinput}. As the project continued it was omitted and $12~\textrm{V}$ would not be needed. Therefore two batteries in series are used. Resulting in a voltage range of $8.4~\textrm{V}$ fully charged and down to $6~\textrm{V}$ fully depleted. This voltage is then stepped down to $5V$ and supplied to the system.
Current wise it was not know how much the system would draw but it was estimated that the capacity of the batteries of $2.2~\textrm{Ah}$ would be enough to power the system for several hours.
In a worst-case scenario, the system would draw more than $500~\textrm{mA}$ which would result in $4~\textrm{h}$ and $24~\textrm{min}$ of usage.
Safety is of high priority as concluded earlier. So a second flowchart was created to determine the specifications of the monitoring of the two batteries in a series configuration. \autoref{fig:battery} displays these specifications.

\begin{figure}[H]
	\centering
	
	\captionsource{Power input flowchart.}{Author}
	\label{fig:powerinput}
\end{figure}

\begin{figure}[H]
	\centering
	
	\captionsource{Battery management flowchart.}{Author}
	\label{fig:battery}
\end{figure}

Three \gls{ic}s where chosen for the \gls{bms}. The BQ28Z610 is a gas gauge \gls{ic} for Li-ion batteries from \gls{ti}, including these features:

\begin{itemize}[noitemsep]
	\item \gls{i2c} communication of status to host.
	\item Balancing of cells, both during charge and use.
	\item Temperature monitoring and regulation.
	\item Under and overvoltage protection.
	\item Overcurrent protection.
	\item \gls{soc} reporting.
\end{itemize}

The \emph{BQ24133}, also a \gls{ti} \gls{ic}, is chosen for charging purposes, making use of the following features:

\begin{itemize}[noitemsep]
	\item 1-3 series cells.
	\item Temperature monitoring and regulation.
	\item Power Path, load can safely be connected during charging.
\end{itemize}

The output voltage is managed by the \gls{ti} \gls{ic} \emph{LM2596} step-down converter.

During development, a \emph{BQ28Z610} development board was used together with together with a Luxorparts variable voltage regulator utilizing the \emph{LM2596} and a generic \gls{lion} \gls{2s} charger.

The \emph{BQ28Z610}'s software was configured using a windows computer, \gls{ti}'s software bqStudio\cite{bqStudio} and the \emph{EV2300 }\gls{pc} interface board.
A \gls{pwb} containing the three \gls{ic}s mentioned above was designed using KiCad\cite{kicad}. The designs were made according to the typical application of each \gls{ic}. Typical applications are found in data sheets.  

\subsection{Current State}
Figure \autoref{fig:modules} displays how the \gls{bms} is currently set up. Up left on top of the main \gls{pcb} is the \emph{BQ28Z610} development board, and below that is the voltage regulator. Charging is enabled via the charging port visible to the right, on the lid.

\begin{figure}[H]
	\centering
	
	\captionsource{Current setup of the battery management.}{Author}
	\label{fig:modules}
\end{figure}

Charging is done by turning the device upside down and connecting a \gls{2s} \gls{lion} charger. See figure \autoref{fig:charging}.

\begin{figure}[H]
	\centering
	
	\captionsource{How to charge.}{Author}
	\label{fig:charging}
\end{figure}

A connection diagram for this configuration can be seen in \autoref{fig:diagram}. The charger is connected to the input of the voltage regulator. This configuration has all the features of that implemented on the \gls{pwb} except the charger is external, charges with $1~\textrm{A}$ instead of $2~\textrm{A}$ and there is no power path, meaning that the device has to be turned off to make charging safely.

\begin{figure}[H]
	\centering
	
	\captionsource{Connection diagram.}{\url{https://www.kjell.com/se}(\emph{LM2596}), \url{http://www.ti.com}(\emph{BQ28Z610EVM-532}), \url{https://www.digikey.com}(\emph{PVA6LRE21131}), Author}
	\label{fig:diagrams}
\end{figure} 

\autoref{fig:bmspwb} shows the \gls{pwb} that when soldered and tested would fulfill all requirements. It is supposed to be the entire \gls{bms}. 
Schematics, board layout, and Gerber-files can all be found in the appendix. %Nope. Not there. Also, refer to them!: Can be found in the appendix, see: \autoref{first}, \ref{second}, ..., and \ref{last}.

\begin{figure}[H]
	\centering
	
	\captionsource{Battery management \gls{pwb}.}{Author}
	\label{fig:bmspwb}
\end{figure}

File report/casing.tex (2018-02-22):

The \project~system has some different types of components and sensors, which all need to be housed in a watertight casing for safety and robustness. Some design ideas for this part was to make it easy to mount, small physical footprint, all the electronics in the same enclosure and watertight.
The case was revised and worked on over the whole length of the course, redefining and remodeling the construction over time.
The cases were constructed with the use of the program \emph{Fusion 360}\cite{cad}, which is a free to use \gls{cad} software. They were then produced by using a 3D printer, which is a fast and easy way of try out different ideas and models.

%% Första versionen -------------------------
\subsection{First revision}
First, a suitable solution was needed, with no thoughts about physical limitations, strength, material or manufacturability.

The idea was modeled around the original mounting plate which is already fastened to the boat, which has the function to hold the board in place and make the dagger-board stable in the boat. The model had the same dimension as the original plate, only the height was different to accommodate the size of the pressure sensors. By making a mounting plate with the same width and length of the original mounting plate the implementation would be neat and space saving.
This one had some problems, one of them was that the case was too big for any of the 3D-printers available. Another problem with this instance of the model was that for the circuit boards to fit inside they had to be very small and have some odd shapes.

% Kolla på mina bilder

\begin{figure}[H]
\begin{center}
	
	\captionsource{First (1) revision of the case.}{Author}
	\label{Case_rev_1}
\end{center}
\end{figure}

%% Andra versionen -------------------------
\subsection{Second revision}
The next revision was like the first one, it had the same shape and idea as the first one by having the same size as the original plate, but this time it only consisted of the front part that holds the sensors and all the electronics. This version could thus be made on a 3D-printer. It still had the problem of having very little space for all the components.

% Kolla på mina bilder
\begin{figure}[H]
\begin{center}
	
	\captionsource{Second (2) revision of the case.}{Author}
	\label{Case_rev_2}
\end{center}
\end{figure}

%% Tredje versionen -------------------------
\subsection{Third revision}
With all the prior knowledge, the next version was modeled. This time it had a much larger casing to accommodate for the \gls{pcb}. The actual size of the \gls{pcb} was set by the inner dimensions of this part, see \autoref{Case_rev_3}.

This case still had some problems, it did not include a holder for the distance sensor nor was it watertight. But this version fulfilled some requirements. The size of the piece was enough to accommodate for the \gls{pcb}, batteries and all the sensors. The piece was created using a 3D-printer to have some progress to show, check for design faults and to determine improvements for the next version.

Due to the fundamental workings of a 3D-printer the size and dimension on the real produced part differed some from the \gls{cad} model. When construction with a 3D-printer the model needs to be compensated for this. One thing that needed to be revised was the implementation of the steel beads.

When building the third version on the 3D-printer the problems with the model could be more easily determined than only looking at a design in a \gls{cad} software. The process of improving the design is both about the physical limitations, and the issues due to the manufacturing process.
% Kolla på mina bilder
\begin{figure}[H]
\begin{center}
	
	\captionsource{Third (3) revision of the case.}{Author}
	\label{Case_rev_3}
\end{center}
\end{figure}

\subsection{Fourth and final  revision}
The fourth revision had all the features and could hold all the electronics. It was designed to house the power switch in the front, the \gls{tof} sensor on the top, the load cells, the batteries and both the \gls{pcb}s in the same enclosure. The access panel was placed at the bottom of the model to get a better water seal. The access panel was a big plate covering most of the bottom of the model. To ensure a watertight case, a seal between the panel and the casing itself could be added. 

Due to the material cost and time it takes for the 3D printer to produce models the manufactured part has just some thin layers in the bottom part of the print. To get the some strength in the model epoxy resin was mixed and poured in to both get the stability needed and a clear window for the \gls{tof} sensor, see \autoref{Case_rev_4} for reference.

%\subsubsection{The prototype}
% Kolla på mina bilder
\begin{figure}[H]
\begin{center}
	
	\captionsource{Fourth (4) and final version of the case.}{Author}
	\label{Case_rev_4}
\end{center}
\end{figure}

\subsection{Results}
The final version is the product of many revised and improved steps. The model holds all the electronics and sensors in the same enclosure and takes up as small physical space as possible. The model is not water tight, the only attempt to correct this is the rubber seal between the load cell and the steel beads used to measure the forces and the power button in the front.

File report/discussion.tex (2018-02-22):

When placing test points, consider convenience. We did not have access to a bed-of-nails test bed and creating one within the span of the project, time- and budget constraints did not seem reasonable. In order to make debugging and testing easier, we placed test points at points of interest like communication buses. The test points were in the form of vias, however it would have been more convenient that they had been made larger, since the debugging tool was often an oscilloscope. The probe points did not fit the holes and they were inconveniently close together. This could have been improved.

Another lesson from the last revision was to use the tool for the job. Debugging the \gls{i2c} via the \gls{mcu} is inconvenient simply due to the overhead associated with reprogramming, and possibly limiting unless the debug code is extensive and general. In this case it was far more convenient to acquire a logic analyzer. It provides multi-protocol communication and monitoring and is faster to setup and modify. The point being that a \emph{test engineer} is an entire profession onto itself and we could have spent more time early on considering how to more efficiently test and debug to save more time during the rest of the project. 

The most significant part of assembling each prototype was soldering the \gls{lga} packages (the \gls{imu}s). Because the pins on these packages were on the underside and not accessible by means of a soldering iron. The only convenient tool for soldering these were to either get it right the first time in the \gls{smd} oven, or to use a hot-air station. Even when using these tools, the soldering was not trivial. To start with, the small size of the packages make them hard to place. Next, the packages were more likely to short due to the small margin for error. Third, even when the packages appear properly soldered, a few times they were not; while not being shorted they would still not function.  In order to make the mounting easier, the footprint pads were extended beyond the edge of the package. This aided in finding shorts by giving easy probe points, and it provided some capacity to handle excess solder. 

During the debugging of the final revision of the PCB there was a case of note. While soldering a new \emph{LSM6DSL} to the board, we discovered a technique to consistently get good soldering results. Assuming that the board has already been stenciled and baked, there should be fresh solder on the pads. Apply generously with flux (better too much than too little) to clean the area and help flow. Using a hot-air station, preheat the board slowly from below for circa a minute and preheat the component towards the end (just flip the board and continue heating from the top while holding the component in the air flow). This prevents the solder from setting fast and making the soldering harder. When the solder visibly melts, place the package on the pads carefully and lightly push the component flat against the board. This forces any residual dirt away from the pads, and the extended footprints control where the displaced solder goes to avoid shorts. When the component has been released, lightly push it from the side. If the component springs back from surface tension it is a good chance that it has been soldered correctly, provided the component was pushed down before. 

In terms of future work, most likely the first thing should be wind direction and/or intensity sensing. Because the direction of the wind has such a significant impact on the performance of the boat. It could possibly be implemented as a rotary encoder, or it might be possible to implement it through a forced-convection sensor\cite{wind_meas}. Other things that could be interesting to measure would the either the state of the rudder or sail, although the latter one especially would probably be a significant task, there is the consideration of what the final scope of the product should be; if it should actually compete as an extensive set with all features the sailor could want or if it should try to go for the lower end of products and do that very well instead. 

% TODO (done?): add citation wind_meas to ltu.diva-portal.org/smash/get/diva2:1039147/FULLTEXT01.pdf

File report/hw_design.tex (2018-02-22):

This chapter will summarize most of the process of creating the \gls{pcb} used to mount all the sensors and sending the data to the phone application. This circuit board will be the link between the physical forces and manipulated data sent to the handheld device. More on how this data is manipulated and how the circuit board is programmed in \autoref{sec:sw}. 

The circuit board must minimally fulfill the following set of basic requirements to function properly:
\begin{itemize}[noitemsep]
\item Circuit must fit within the casing, with dimensions extracted directly from the cad software\cite{cad}, see \autoref{fig:casdim}.
\item Circuit must be easy to test for both hardware and software errors. All systems needs this, if nothing else only to test if they are correctly soldered.
\item All sensors must fit on the \gls{pcb}, both physically and also electronically on the ports of the \gls{mcu}.
\item Must be protected against all common problems, such as overcharge, undercharge, capacitive effects, and more.
\item All components needs to be actively manufactured to ensure unit can keep being produced for several years in the future.
\end{itemize}

\subsection{Method}
\chapterauthor{Brolin, Daniel (Eriksson, Kenny)}
% Methodology
The main circuit board is built using the open source electronic design software \emph{KiCad}\cite{kicad}. It is completely free to use and the source code is open for any modifications.
Designing circuit boards differs slightly between what software you are using. \emph{KiCad} uses a four step process as follows:
\begin{enumerate}[noitemsep]
\item Draw schematic:
	\begin{enumerate}[noitemsep]
	\item Place and connect all components electronically.
	\item (Optional:) All non-standard components must be custom designed, this is referred to as a``symbol''. Most sensors requires custom built symbols.
	\item Annotate schematic and run \gls{erc} to identify simple electronic violations.
	\end{enumerate}
\item Create net-list:
	\begin{enumerate}[noitemsep]
	\item (Optional:) All components with non-standard (or simply not standard enough) footprints must be custom designed, these include all sensors and the \gls{bt} module.
	\item Associate all components with whatever physical footprint are to be used.
	\item Generate net-list.
	\end{enumerate}
\item Design \gls{pcb} layout:
	\begin{enumerate}[noitemsep]
	\item Import net-list to \gls{pcb} editor.
	\item Set global and net-specific design rules.
	\item Place and connect all components.
	\item Run \gls{drc} to identify all specified design rule violations.
	\end{enumerate}
\item Generate manufacturing (gerber/drill) files.
\end{enumerate}
% Borrowed shit
The initial required circuitry, see \autoref{fig:schr3a}, was copied from earlier works with the \gls{st} \gls{arm} \gls{mcu}'s but modified to meet our needs. The power section, also found in \autoref{fig:schr3a}, is designed to only allow for exactly $+5~\textrm{V}$. This design is credited to, and derived from \emph{Maxim Integrated}, Application note 760\cite{overprotection}.

% Original custom shit
Non-standard library entries include following components:\\
\begin{minipage}{\linewidth}
\begin{table}[H]
\centering
	\begin{tabular}{ l | l | l | l }
 	Name		& Type 								& Library 				& Used in         \\
 			&									&					& last rev.\footnote{revision}\\
	\hline
  	A2235-H  	& \gls{gps} 								& a2235-h.lib 			& \textbf{YES}\\
  	FT232RL 	& USBtoSerial converter 						& ftdi.lib\cite{ftdi}			& \textbf{YES}\\
  	HTS221 	& Humidity sensor 							& Custom\_sensors.lib 		& \textbf{YES}\\
  	LM1117ADJ 	& Voltage Regulator						& PowerSupply.lib\cite{lm1117} 	& \textbf{YES}\\
  	LPS22HB 	& Pressure sensor  							& Custom\_sensors.lib 		& \textbf{YES}\\
  	LSM303AGR	& Acc.\footnote{Accelerometer}/Mag.\footnote{Magnetometer} \gls{imu} & Custom\_sensors.lib & \textbf{YES}\\
  	LSM303Cx 	& Acc./Mag. \gls{imu} 						& Custom\_sensors.lib		& \textbf{NO} \\
  	LSM6DSL 	& Acc./Gyro.\footnote{Gyroscope} \gls{imu} 			& Custom\_sensors.lib 		& \textbf{YES}\\
  	LSM9DS1 	& Acc./Gyro./Mag. 							& Custom\_sensors.lib 		& \textbf{NO} \\
  	MCDTS2-4N 	& Tactile switch button 						& Custom\_Switches.lib 		& \textbf{YES}\\
\end{tabular}
\caption{Non-standard library entries, custom or third-party designed.}
\label{table:nstdlibs}
\end{table}
\end{minipage}
\vspace{.5cm}

%\subsection{Revisions}\label{sec:hw:rev}
In total three revisions of the \gls{pcb} was designed. The first revision was designed well before any components arrived and was meant exclusively as a prototype, while both the second and third revisions were supposed to have full functionality. All revisions following the first were initially supposed to be designed as consecutive debugged states, but complete redesigns of component placings and tracing was eventually necessary.

\subsubsection{First revision}
First revision included the main functionality and test points on basically every pin in the system. It did not follow any space- or requirements and was riddled with small problems. The \emph{USB-to-Serial} converter was broken, the \gls{i2c} line was short circuited somewhere, the custom footprint for the \gls{gps} was mirrored, the \gls{bt} worked, but poorly due to interference from other circuitry and so on and so fourth. Most of this was probably because we had to design the \gls{pcb} and draw all custom made footprints before actually receiving the components. This revision was also meant as a prototype, and not enough time was put to make sure all isolations and trace widths had well thought out values. High-speed switching logic had been designed for the wakeup-signal to the \gls{gps}, but this was not used. The schematic of revision one has not been included in this report, as there is little to learn from it; the \gls{pcb} can however be seen as \autoref{fig:pcbr1}.
\begin{figure}[H]
	\centering
    
	\captionsource{First (1) revision circuit board.}{Author}
	\label{fig:pcbr1}
\end{figure}

\subsubsection{Second revision}
The second revision fixed all known problems, followed the space requirements and added a lot of customization. The option to toggle power source and what sensors were currently powered was added. This way the effect from individual modules could be measured. Also since it was still unclear if a combined chip for all \gls{imu}s would be added or not, space for all of them and an evaluation module was added. However, some wires were lost in the transition from revision one to two, as all net-labels in the schematic were redrawn; also the micro-\gls{usb} housing was to small for continuous use and was ripped of by our (way to strong) programmers; all of this was hotfixed and eventually the circuit board worked as expected. As with revision one, the schematic of revision two has not been included in this report, as there is little to learn from it; the \gls{pcb} can however be seen as \autoref{fig:pcbr2}.
\begin{figure}[H]
	\centering
	
	\captionsource{Second (2) revision circuit board.}{Author}
	\label{fig:pcbr2}
\end{figure}

\subsubsection{Third revision}
Almost all problems were solved in the second revision; what remained was some hotfixing for an unexpected wiring error in the \gls{gps}, interference between \gls{i2c} clock and data line, minimizing much to large decoupling ground loops, unwanted antennas, ground islands of missing copper and a KiCad problem where disconnected \gls{via}s lose their net property. The option to pull power from either \gls{usb} or batteries remained in the last revision, as this makes programming and testing much easier. A four pin connector to measure the battery level through \gls{i2c} was added; and since the power level of this depends slightly on the power left in the batteries, logic level converters were designed to allow for variable voltage levels\cite{llc}, the electronic circuitry can be see in \autoref{fig:schr3b}.
For the third revision all decisions have been made and the schematic can be seen as \autoref{fig:schr3a}, \ref{fig:schr3b} and \ref{fig:schr3c}, section \ref{app:schemmain}.

Following communicative devices will used and act as ``module areas'', i.e. these units will be the central units of the \gls{pcb} layout. This was introduced to the second revision \gls{pcb}, but is much more prominent in the last revision (\autoref{fig:pcbr3simple}).
\begin{itemize}[noitemsep]
\item{\makebox[3cm][l]{STM32F411RET} - Microcontoller unit}
\item{\makebox[3cm][l]{FT232RL} - \gls{usb}toSerial converter (USART)}
\item{\makebox[3cm][l]{A2235-H} - \gls{gps} unit (UART)}
\item{\makebox[3cm][l]{SPBTLE-RF} - \gls{bt} connection unit (SPI)}
\item Sensors ($I^2C$):
	\begin{itemize}[noitemsep]
	\item{\makebox[3cm][l]{LSM303AGR} - Accelereometer \& Magnetometer}
	\item{\makebox[3cm][l]{LSM6DSL} - Accelerometer \& Gyroscope}
	\item{\makebox[3cm][l]{HTS221} - Humidity}
	\item{\makebox[3cm][l]{LPS22HB} - Pressure}
	\end{itemize}
\item Sensors, connectors only ($I^2C$):
	\begin{itemize}[noitemsep]
	\item Battery level
	\item VL530x \qquad- Time of flight
	\end{itemize}
\item{\makebox[2.5cm][l]{INA128} - Analog load cell amplifiers (ADC)}
\item{\makebox[2.5cm][l]{MCDTS2-4N} - Tactile push buttons (Pull-up/Pull-down)}
\end{itemize}
The layout of the components are such that all \gls{i2c} communicative devices were moved to one spot ensuring the shortest possible \gls{i2c} data line, these were placed to the top right of the \gls{pcb}. The power was placed in the bottom left, since this is as far as possible from everything else. \gls{usb} was placed next to the power, as power can be opted to be drawn from \gls{usb} rather than the battery. Analog plane with the load cells were put right next to the power to ensure the star-ground\footnote{A common node ground connecting all grounds together to ensure the same set working level} to be as close as possible to the power-source allowing for as little noise as possible. \gls{bt} communication devices are rather fragile, it was therefore placed as far as possible from everything in the top left corner of the \gls{pcb}. This \gls{bt} module, \emph{SPBTLE-RF}, requires \gls{spi} communication and in total $6$ isolated traces were to be drawn between the \gls{mcu} and the \gls{bt} unit. To minimize crossover the \gls{gps} is placed in the top-mid of the \gls{pcb}. Lastly the buttons whose placing is of low importance were placed in the middle-left, between the power source and the \gls{bt} unit because this is where there was space left. 
Ground \gls{via}s were added around communication traces to prevent unwanted interference, ground \gls{via}s were also added to prevent antennas\footnote{Antennas appear by letting isolated thin grounds be connected on only one end, a \gls{via} can therefore be added to the other end to prevent this from happening.}.
The third, and last, revision of the \gls{pcb} can be seen in \autoref{fig:pcbr3}, a simple explanation of the layout can be seen in \autoref{fig:pcbr3simple}.
\begin{figure}[H]
	\centering
    	
	\captionsource{Third (3) revision circuit board.}{Author}
	\label{fig:pcbr3}
\end{figure}
\begin{figure}[H]
	\centering
   	
	\captionsource{Simple model of third (3) revision circuit board areas.}{Author}
	\label{fig:pcbr3simple}
\end{figure}

\subsection{Component choices}\label{sec:hw:tip1}
\chapterauthor{Eriksson, Kenny (Brolin, Daniel)}
\input{tmp_hw_choice_of_components_kenny.tex}

\subsection{Results, Discussion and Future Work}\label{sec:hw:tip2}
\chapterauthor{Brolin, Daniel \&  Eriksson, Kenny}
The final sensor board works as expected. Had it not been for the fact that one of the sensors was broken it would have been soldered without any problem. No interference problems or antennas has been found on the last revision \gls{pcb} and no hot fixes were necessary.
Calibrating the potentiometers for the analog load cell amplifiers is possibly the most uncertain process, as wrongly tuning these will offset all values in the feedback. This is however necessary until the last prototype for the casing is complete, see \autoref{sec:case}, since small differences in the casing will require different calibrations.
The system is estimated to run for about $24~\textrm{hrs}$, more about power management in \autoref{sec:bat}. 

All components in the last revision prototype is of a rather large form factor considering the relatively low effect acting on the components, making soldering and testing easier but taking up more space. As it is now the system can very likely be minimized further. Taking away the general purpose button, set the general form factor to the industry standard $0402$ (approximately $1~\textrm{mm}$ x $0.5~\textrm{mm}$) which is still easily soldered by hand, use $4$-layer design could probably shrink the system to about half of the size if no more devices are added to the design. Alternatively more sensors or communication with an external sensor board could be supported in future updates without the need of to much remodeling. 

\input{discussion.tex}

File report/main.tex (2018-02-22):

\documentclass[a4paper]{article}

% text
\usepackage[utf8]{inputenc}
\usepackage[numbers]{natbib}
%\bibliographystyle{unsrtnat}
\usepackage{lipsum}
\usepackage[toc,page]{appendix}
\usepackage{amssymb,amsmath}
\usepackage{gensymb}
\usepackage{amsfonts}
\usepackage{todonotes}
\usepackage{listings}
\usepackage{enumitem}
\usepackage{scrextend}
\usepackage{graphicx, xcolor}
\usepackage{wrapfig}
\usepackage{rotating}
\usepackage{subcaption, float}
%\usepackage[sc]{titlesec}
%\usepackage{titletoc}

% links
\usepackage{color}
%\usepackage[linktocpage=true, colorlinks=true, allcolors=blue]{hyperref}
\usepackage[pdfpagemode={UseOutlines},bookmarks=true,bookmarksopenlevel=0,bookmarksnumbered=true,plainpages=false,colorlinks,linkcolor={black},citecolor={blue},urlcolor={blue},pdfstartview={FitV},unicode,breaklinks=true,pdfpagelabels]{hyperref}
\usepackage[all]{hypcap}
\usepackage[hypcap]{caption}

% layout
%\usepackage{multicol}
\usepackage{fancyhdr,lastpage}
\setcounter{tocdepth}{2}

% header layout
\usepackage{suffix}

% Abbreviations and glossary
\usepackage[automake,entrycounter,acronym,toc,section=section,numberedsection=autolabel]{glossaries-extra}
\makeglossaries
\setabbreviationstyle[acronym]{long-postshort-user}
\glssetcategoryattribute{acronym}{nohyperfirst}{true}
\renewcommand*{\glsxtruserparen}[2]{
  \glsxtrfullsep{#2}
  (\glshyperlink[#1]{#2})
}

\newcommand{\project}{\emph{SailorAid}}

\newcommand\chapterauthor[1]{\authortoc{#1}\printchapterauthor{#1}}
\WithSuffix\newcommand\chapterauthor*[1]{\printchapterauthor{#1}}

\makeatletter
\newcommand{\printchapterauthor}[1]{%
  {\parindent0pt\vspace*{-10pt}%
  \linespread{1.1}\large\scshape#1%
  \par\nobreak\vspace*{10pt}}
  \@afterheading%
}
\newcommand{\authortoc}[1]{%
  \addtocontents{toc}{\vskip-1pt}%
  \addtocontents{toc}{%
    \protect\contentsline{chapter}%
    {\hskip0em\mdseries\scshape\protect\scriptsize#1}{}{}}
  \addtocontents{toc}{\vskip5pt}%
}
\makeatother

% Figure caption source
\newcommand*{\captionsource}[2]{%
  \caption[{#1}]{#1}\par
  \textbf{Source:} #2\par}

% header style
\pagestyle{fancy}
\lhead{Project \project}
\chead{}

\rhead{\today}
\lfoot{}
\cfoot{\thepage~of~\pageref{LastPage}}
\rfoot{}
\renewcommand{\headrulewidth}{0.4pt}
\renewcommand{\footrulewidth}{0.4pt}

\input{glossary.tex}

\begin{document}

\begin{titlepage}
\input{titlepage.tex}
\end{titlepage}

\clearpage
\begin{abstract}
\input{abstract.tex}
\end{abstract}

\clearpage
\setlength{\columnseprule}{0.2pt}
\tableofcontents % TABLE OF CONTENTS
\vspace{0.5em}

\clearpage
\noindent
\printglossary[type=\acronymtype]
\printglossary[type=main]

\clearpage
\setcounter{page}{2}
\section{Introduction}
\chapterauthor{Eriksson, Kenny (Sjölund, Johannes)}
\input{introduction.tex}

\clearpage
\section{The Physics of Sailing}
\label{sec:physics}
\chapterauthor{Theolin, Henrik (Axelsson, Oskar)}
\input{physics.tex}

\clearpage
\section{Mechanical Sensors}
\chapterauthor{Lundberg, Josef (Grape, Elias)}
\input{sensors.tex}

\clearpage
\section{Main Sensorboard Design}\label{sec:hw}
\chapterauthor*{Brolin, Daniel (Eriksson, Kenny)}
\input{hw_design.tex}

\clearpage
\section{Battery Management}\label{sec:bat}
\chapterauthor{Grape, Elias (Lundberg, Josef)}
\input{bms.tex}

\clearpage
\section{Casing}\label{sec:case}
\chapterauthor{Lundberg, Josef (Sjölund, Johannes)}
\input{casing.tex}

\clearpage
\section{Software Design}\label{sec:sw}
\chapterauthor*{Sjölund, Johannes (Brolin, Daniel)}
\input{software_design.tex}
\input{android.tex}
\input{software_results.tex}

\clearpage
\section{Inertial Navigation System and\\ Kalman Filter}
\label{kf}
\chapterauthor{Axelsson, Oskar (Theolin, Henrik)}
\input{kf.tex}

\clearpage
\input{references.tex}
\clearpage
\begin{appendices}
\input{APPENDIX.tex}
\end{appendices}

\vspace*{9cm}
\begin{center}
The project; complete with all software code, the application, hardware files and more, can be found online in our github-repo:\\
\url{https://github.com/jsjolund/sailoraid}
\end{center}

\end{document}

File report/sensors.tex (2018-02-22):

Since sailboats utilize wind to move, not fuel or electricity, optimization of the usage of surrounding forces are important. Measurements of these will provide the sailor with information needed to optimize the way to move and control the dinghy.

To make measurements on the dinghy, sensors are needed. As of now there are sensors measuring a wide array of items. This section describes; what they measure, where they were purchased, the requirements on the sensor, their features, drawbacks and also how they were implemented.
Since the sensors have to work in this particular system, a casing was made for the sensors.
The designs where made with the \gls{cad} software Fusion 360\cite{cad}. The casings where manufactured with a 3D printer.

\subsection{Force sensors}
The function of the daggerboard is to compensate for the force that the wind is pushing on the sail, and keep the dingy from drifting in the water. The goal is to have a system that can measure the forces from the water that pushes on the daggerboard. By measuring this, an estimation of the exerted force on the sail can be made. 

\subsubsection{The implementation}
Although different solutions where suggested the sensor and measurement method that was chosen his is shown in \autoref{Press_sens_impl}. 
Important to know is that every solution is mandatory to be waterproof and sealed properly from the harsh environment that this system will operate in. 
With this implementation the daggerboard itself will not be disassembled or modified in any way; as solutions that require sensors to be mounted on the parts likely to be damaged in a crash was scratched.

\begin{figure}[H]
\begin{center}
	
	\captionsource{Function of first prototype.}{Author}
	\label{Press_sens_impl}
\end{center}
\end{figure}

\subsubsection{The prototype}
To integrate the gauges, a prototype was designed to show how the measurements would be made. The prototype shown in \autoref{Press_sens_prot_1} is a bit bigger than the intended solution for this project but it is good to see how it would be constructed. The board goes on the outside and can easily slide up and down past the steel bead. The bead itself is kept inside a small space where it can move in and out.

The prototype of the pressure sensor was created in order to show the function of this sensor and to help the thought process involved in the improving of this design.

\begin{figure}[H]
\begin{center}
	
	\captionsource{First prototype of a force sensor.}{Author}
	\label{Press_sens_prot_1}
\end{center}
\end{figure}

The force is measured at the back on the plate. The deflection of this plate will be used to measure the strain with strain gauges. 
The gauge itself will measure a small difference in resistance. This small difference is going to be difficult to measure without any amplifying circuit connected. With such a small signal the system might have issues with noise. Another problem is that the signal might drift, causing differences in the measurements during run-time. Because of this, with the measured values getting amplified, the drift differences may be off by unacceptable amounts. 

In the second prototype load cells, which are sensors that utilizes strain gauges to measure forces, were chosen for this purpose. Rather than having a metal plate, this prototype can be built with a piece of plastic or rubber which can deform so the force is distributed directly to the sensor. By implementing load cells, a lot of time was saved in troubleshooting; and by having a sensor unit, the modified mounting plate will be easier to produce. An illustration of this setup can be seen in \autoref{Press_sens_prot_2}.
 
\begin{figure}[H]
\begin{center}
	
	\captionsource{Function of second prototype.}{Author}
	\label{Press_sens_prot_2}
\end{center}
\end{figure}

\subsubsection{Sensor}
The force from the board on the mounting plate will be considerably large. The actual force is something that is not known for sure. The initial assumption was that a load cell with a $90.75~\textrm{kg}$ force range should be enough. If the sensor will be maxed out, the cell its rated for a $150\%$ overload without causing some damage to the sensor. 

The chosen sensor for this application is the compression load cell called \emph{FX1901}. 
From the datasheet\cite{load_cell}, the voltage readings of this part could be calculated. The maximum voltage difference is calculated to be around $180~\textrm{mV}$, see \autoref{Load_cell}.
\begin{figure}[H]
\begin{center}
	
	\captionsource{Load cell, \emph{FX1901}.}{\url{http://uk.farnell.com/sensor-solutions-te-connectivity/fx1901-0001-0100-l/compression-load-cell-45-4kg-5vdc/dp/2771943}}
	\label{Load_cell}
\end{center}
\end{figure}

\subsection{Amplifier}
With such a small signal, an amplifier is needed to get good measurements. A good measurement signal to the \gls{mcu} should be between $0$-$3.3~\textrm{V}$. Since the maximum value from the load cell is $180~\textrm{mV}$ a signal of $3.3~\textrm{V}$ is achieved by an amplification gain of around $20$ times.  
A suitable amplifier needs to be chosen from this implementation. Inspiration is taken from The University of Chicago\cite{UoC} in an experiment where they use this exact load cell together with an instrumental amplifier called \emph{INA125}. %This amplifier is more advanced and has more features than other amplifiers.  % Either explain why or leave it out.

In the same family of instrument amplifiers, the model \emph{INA126} was selected as a less complicated and more power efficient solution.  
The \emph{INA126} amplifier has a smaller power draw due to simpler functionality and lower precision than the \emph{INA125}, but is still sufficient for this application.  
The implementation is easy and the gain can easily be determined by connecting a resistor $Rg$ between two pins on the amplifier, see \autoref{INA126}.

\begin{figure}[H]
\begin{center}
	
	\captionsource{Amplifier \emph{INA126} for the load cell signal.}{\url{http://www.ti.com/lit/ds/symlink/ina126.pdf}}
	\label{INA126}
\end{center}
\end{figure}

\noindent The gain is calculated with the following equation.  
\begin{equation}
\textrm{Gain} = 5 + \frac{80~\textrm{k}\Omega}{R_G}
\end{equation}
In order to adjust the gain of the amplifier, the resistor $R_G$ is set to a fixed resistor in series with a potentiometer.

\subsection{Height of dagger-board sensor}
The height of the dagger-board is a crucial measurement in dinghy sailing. The dagger-board not only gives the dinghy a corresponding force to the sail, the board can also be a danger if you sail in running wind. One of the best implementations of a height sensor would be the use of a linear wire distance sensor. This sensor measures how far a wire is pulled, which gives a very accurate measurement. This solution can be completely watertight and concealed in the main center-plate\footnote{The plate on where the dagger-board is mounted.}. Another solutions could be to use some type of light, \gls{tof} sensor. 

\subsubsection{Sensors}
A suitable product was found, it is accurate and reliable, the \emph{Micro epsilon mk30}; its physical volume in small enough with a size of $3x5~\textrm{cm}$. As the product have tight space constraints this would probably fit inside the case. The sensors price however was about $2000~\textrm{kr}$, it was deemed to expensive. If no other solution would work as intended this might have been considered again.
\begin{figure}[H]
\begin{center}
	
	\captionsource{Linear draw wire sensor, Micro epsilon MK30.}{\url{http://www.tracepartsonline.net/partdetails.aspx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}}
	\label{Draw_sensor}
\end{center}
\end{figure}

Light sensors have also been considered. This would be implemented with the use of a plate placed on top of the dagger-board and with the light being sent up to this panel, the height can be calculated. Initially, some \gls{ir}-sensors were considered,  they will send the signal in a widespread arc which will make the distance measurement troublesome as this signal has just a small plate to bounce off.

With the use of a \gls{lidar}\gls{tof} system, we can point our light signal at an exact spot and then get an exact measurement of the height.  
Many of the \gls{lidar} systems found was both too large and expensive to be implemented in this project.
But a product called "micro-lidar" could be used; as it has a small form factor it is easy to implement and is not to expensive.
The chosen module is the \emph{VL53L0X} from Adafruit, see \autoref{micro_lidar}. It can measure heights up to one meter with great accuracy and communicates with \gls{i2c}.
By the fact that the sensor must be waterproof the signal has to go through a medium. The medium can be some type of transparent plastic or glass.
\begin{figure}[H]
	\centering
	
	\captionsource{Time of flight, $\mu$\gls{lidar}, distance sensor \emph{Adafruit VL53L0X}.}{\url{https://www.amazon.com/Adafruit-Industries-DISTANCE-3317-Evaluation/dp/B06XPVJCZJ}}
	\label{micro_lidar}
\end{figure}

All the information about this sensor and the usage of a cover widow can be found in the specific datasheet\cite{Tof_cover}. The maximum thickness of the cover window together with the air gap between the sensor and the window is $2~\textrm{mm}$. That is the parameters that need to be considered. To reflect the signal a detection plate is constructed and fastened to the top of the dagger-board. This plate is level with the sensor and has a white bottom for best performance of the sensor. In the case the sensor is mounted behind a thin epoxy window witch was to thick at the beginning but was sanded down to a suitable thickness. The final window was then carefully polished for the best possible measurements. 

\begin{figure}[H]
	\centering
	
	\captionsource{Height measurement model.}{Author}
	\label{height_measure}
\end{figure}

\subsubsection{Results}
The sensor works very well in the open air and can detect heights up to $1.5~\textrm{m}$ with great accuracy. It also works well when used behind a thin transparent plastic cover. With a $1~\textrm{mm}$ thin transparent plastic cover the maximum height measurement is decreased to about $1~\textrm{m}$. 

The performance of the sensor heavily depends on the the finish of the window, if there is small imperfections on the window such as scratches the sensor performance is greatly reduced or completely diminished due to the light spreading everywhere.

As there will always be water around and on the center plate the light that is sent might get scattered out off sight, even a small water droplet in between the sensor and the panel might cause a fault in the measurement.  

This system can definitively be improved in the future with either a completely different measurement system or with a better implementation of the window cover. The window cover probably would work better if the cover was molded in a convex form, which could lead off the water droplets formed on the window surface. This in cooperation with a surface finish that repels water, such as a hydrophobic coating would be a great solution.

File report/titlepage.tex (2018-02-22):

\newcommand{\HRule}{\rule{\linewidth}{0.5mm}}
\center % Centre everything on the page

%------------------------------------------------
%	Headings
%------------------------------------------------

\textsc{\LARGE Luleå University of Technology}\\[1.5cm] % Main heading such as the name of your university/college

\textsc{\Large Dept.\ of Computer Science, Electrical and Space Engineering}\\[0.5cm] % Major heading such as course name

\begin{centering}
\begin{tabular}{l l}
\textsc{\large D7039E --}	& \textsc{\large Project in Industrial Computer Systems}\\ % Minor heading such as course title
\textsc{\large E7025E --}	& \textsc{\large Project in Engineering Physics and}\\
				& \textsc{\large Electrical engineering} % Minor heading such as course title
\end{tabular}
\end{centering}\\[0.5cm]
%------------------------------------------------
%	Title
%------------------------------------------------

\HRule\\[0.8cm]

{\huge\bfseries Project \project}\\[0.4cm] % Title of your document

\HRule\\[1.5cm]

%------------------------------------------------
%	Author(s)
%------------------------------------------------
\begin{minipage}{0.4\textwidth}
	\begin{flushleft}
		\large
		\emph{Authors}\\
		Axelsson, Oskar, \\ 
		Brolin, Daniel, \\ 
		Eriksson, Kenny, \\ 
		Grape, Elias, \\ 
		Lundberg, Josef, \\ 
		Sjölund, Johannes, \\
		Theolin, Henrik\\
	\end{flushleft}
\end{minipage}
~
\begin{minipage}{0.4\textwidth}
	\begin{flushright}
		\large
		\textit{Managing Editor}\\
		Brolin, Daniel
	\end{flushright}
	\begin{flushright}
		\large
		\textit{Supervisor}\\
		van Deventer, Jan
	\end{flushright}
\end{minipage}

% If you don't want a supervisor, uncomment the two lines below and comment the code above
%{\large\textit{Author}}\\
%John \textsc{Smith} % Your name

%------------------------------------------------
%	Date
%------------------------------------------------

\vfill\vfill\vfill % Position the date 3/4 down the remaining page

{\large\today} % Date, change the \today to a set date if you want to be precise

%------------------------------------------------
%	Logo
%------------------------------------------------

\vfill\vfill
\\[1cm] % Include a department/university logo - this will require the graphicx package
 
%----------------------------------------------------------------------------------------

\vfill % Push the date up 1/4 of the remaining page

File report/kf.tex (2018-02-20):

\subsection{Sensor theory}
Sensor fusion can be observed everywhere e.g., living animals uses all of its senses to survive daily, an animal cannot hunt using its eyes only, it has to combine its sense of smell, eyes, and hearing to hunt the prey\cite{animal}.

Sensor fusion theory is found not only in the living species but also in cars, planes, computers and so on; this to enhance performance and accuracy. In this project, a sensor fusion will be designed to enhance the accuracy of the dinghy's position and velocity. The fusion will be a global positioning system,  \gls{gps} and an \gls{ins}. The \gls{ins} uses a low priced \gls{imu}.

The \gls{gps}'s accuracy is not uniform since there might be building reflections, atmospherics delays or clock bias errors\cite{boken}. Using the only information provided by a \gls{sins} is not sufficient either since the \gls{imu} sensor will drift after time, but using the information provided by the \gls{ins} for short time intervals will give more accurate results.  

\subsection{Inertial Navigation System}
In navigation there exist different techniques on how to navigate using an \gls{imu}, a typical technique is using a \gls{sins}. A \gls{sins} consists of an \gls{imu} which is mounted on the dinghy so it measures the acceleration and rotational rate that the dinghy encounters.
The concepts of inertial navigation are to determine the position and velocity of the dinghy from a known starting point, using only measurements from the \gls{imu}. The \gls{imu}, in this case, consists of a three-axis gyroscope, a three-axis accelerometer and a three-axis magnetometer.

Measurement from the gyroscope is to determine the angular motion of the dinghy, from that its heading relative to a reference frame can be derived.
By measuring specific forces acting on the dinghy using the accelerometer, then resolve the specific force measurements into the reference frame using the knowledge derived from the information provided by the gyroscope. 
The resolved specific force measurements are integrated to obtain its velocity and position\cite{non-linear}.

\subsection{Sensor fusion}
A popular filter to use when applying sensor fusion is to use a Kalman filter. The Kalman Filter is a recursive filtering method for discrete data, the algorithm was developed by a Hungarian mathematician \emph{Rudolf (Rudi) Emil Kalman} in $1960$, its popular to use due to its efficiency when calculating predictions\cite{kf eff}.

\subsection{Navigation Frames}
Navigation algorithm involves various coordinate frames and therefore transformation between frames is a must. In this case, four different frames is used.

The Inertial frame denoted $i$-frame for future notation is defined such that its origin is at the center of Earth and its axes $X_i$, $Y_i$ and $Z_i$ is non-rotating with respect to the stars. $Z_i$ is coincident with the Earth's polar axis, i.e., North.

The Earth navigation frame denoted $e$-frame for future notation is fixed with respect to Earth and has its origin at the center of the Earth. The frame is defined as $X_e$, $Y_e$ and $Z_e$, with $Z_e$ along Earth's polar axis. Axis $X_e$ and $Y_e$ lies along the intersection of the plane of the Greenwich meridian with the Earth's equatorial plane. The $e$-frame rotates at a constant rate with respect to the $i$-frame and is denoted $\omega_e$.

The Navigation frame denoted $n$-frame for future notation is a local frame and has its origin located in the navigation system, in this case point $P$, see \autoref{WGS}, and its axes aligned with the directions of north, east and down, denoted NED. The turn rate of the navigation frame with respect to Earth's fixed frame, $\omega_{en}^n$, is directed by the motion of point $P$ with respect to the Earth and is referred to the transport rate.   
\begin{figure}[H]
\centering

\captionsource{Inertial, Earth and Navigation frame.}{\url{https://www.researchgate.net/figure/Inertial-frame-earth-frame-and-navigation-frame-representation-on-the-Earth-ellipsoid_fig1_228071809}}
\label{WGS}
\end{figure}

The Body frame denoted $b$-frame is the sensitive axes of the \gls{imu}'s sensors, which are made to coincide with the axes of the moving body in which the \gls{imu}s are mounted on. The body, in this case, is referred to the dinghy, see \autoref{Fig:body_frame}.
\begin{figure}[H]
\centering

\captionsource{Body Frame.}{\url{https://moziru.com/images/row-boat-clipart-transparent-4.png}}
\label{Fig:body_frame}
\end{figure}

\begin{itemize}
\item Yaw $(\psi)$: Is an imaginary line running vertically through the ship and through its center of gravity. A yaw motion is a side-to-side movement of the bow and stern of the dinghy \cite{SNAME}.
\item Pitch $(\theta)$: Is an imaginary line running horizontally across the ship and through the center of gravity. A pitch motion is an up-or-down movement of the bow and stern of the dinghy \cite{SNAME}.
\item Roll $(\phi)$: Is an imaginary line running horizontally through the length of the ship, through its center of gravity, and parallel to the waterline. A roll motion is a side-to-side or port-starboard tilting motion of the superstructure around this axis\cite{SNAME}.
\end{itemize}

\subsection{Transformation Between Frames}
Referring to \autoref{WGS} it can be observed that its possible to align the $n$-frame with the $e$-frame, this is done by rotating the $n$-frame by ($\lambda-90$)-degrees around its $X$-axis (east-direction) and ($-\phi-90$)-degrees about its $Z$-axis, (downward direction)\cite{nonlinear}. Where $\lambda$ and $\varphi$ is the latitude and longitude, respectively. Then the transformation between the two frames can be done using the \gls{dcm}\cite{nonlinear}, which is defined as
\begin{equation}
C_n^e=R_z(-\lambda-90)R_x(\varphi-90)
\label{Cosine_1}
\end{equation}
Where $C_n^e$ should be interpreted as moving from $n$-frame to $e$-frame, $R_x$ and $R_z$ are the rotation matrices around its axis, respectively. Expanding equation \eqref{Cosine_1}
\begin{align}
C_n^e &=
\begin{bmatrix}
cos(-\lambda-90) & sin(-\lambda-90) & 0\\
-sin(-\lambda-90) & cos(-\lambda-90) & 0\\
0 & 0 & 1
\end{bmatrix}
\begin{bmatrix}
1 & 0 & 0\\
0 & cos(\varphi-90) & sin(\varphi-90) \\
0 & -sin(\varphi-90) & con(\varphi-90) \\
\end{bmatrix}\\
C_n^e &=
\begin{bmatrix}
-sin(\lambda) & -cos(\lambda) & 0\\
cos(\lambda) & -sin(\lambda) & 0\\
0 & 0 & 1
\end{bmatrix}
\begin{bmatrix}
1 & 0 & 0\\
0 & sin(\varphi) & -cos(\varphi) \\
0 & sin(\varphi) & sin(\varphi) \\
\end{bmatrix}\\
C_n^e &=
\begin{bmatrix}
-sin(\lambda) & -sin(\varphi)cos(\lambda) & cos(\varphi)cos(\lambda) \\
cos(\lambda) & -sin(\varphi)sin(\lambda) &  cos(\varphi)sin(\lambda) \\
0 & cos(\varphi) & sin(\varphi) \\
\end{bmatrix}
\end{align}
Exploring the orthogonality its possible to transform from $e$-frame to $n$-frame by taking the inverse of the equation above, i.e.
\begin{equation}
(C_n^e)^{-1}=C_e^n
\label{Eq.Earth2Nav}
\end{equation}
Using equation \eqref{Eq.Earth2Nav} its now possible to move from $e$-frame to $n$-frame.

Transforming from $n$-frame to $b$-frame is done in the same way, i.e. using rotation matrices. The \gls{dcm}, moving from $b$-frame to $n$-frame is given by
\begin{equation}
C_b^n=R_z(-\psi)R_y(-\theta)R_x(-\phi),
\label{Body_rotation}
\end{equation}
where 
\begin{align}
R_z(-\psi) = &
\begin{bmatrix}
cos(\psi) & -sin(\psi) & 0\\
sin(\psi) & cos(\psi) & 0 \\
0 & 0 & 1
\end{bmatrix}\label{R_z} \\
R_y(-\theta) = &
\begin{bmatrix}
cos(\theta) & 0 & sin(\theta)\\
0 & 1 & 0 \\
-sin(\theta) & 0 & cos(\theta)
\end{bmatrix}\label{R_y} \\
R_x(-\phi) = &
\begin{bmatrix}
1 & 0 & 0\\
0 & cos(\phi) & -sin(\phi)\\
0 & sin(\phi) & cos(\phi)
\end{bmatrix}\label{R_x}
\end{align}
Solving equation \eqref{Body_rotation} with \eqref{R_z}, \eqref{R_y} and \eqref{R_x}
\begin{align}
C_b^n = &
\begin{bmatrix}
cos(\psi) & -sin(\psi) & 0\\
sin(\psi) & cos(\psi) & 0 \\
0 & 0 & 1
\end{bmatrix}
\begin{bmatrix}
cos(\theta) & 0 & sin(\theta)\\
0 & 1 & 0 \\
-sin(\theta) & 0 & cos(\theta)
\end{bmatrix}
\begin{bmatrix}
1 & 0 & 0\\
0 & cos(\phi) & -sin(\phi)\\
0 & sin(\phi) & cos(\phi)
\end{bmatrix}
\label{expand_Body_rotation} \\ \\
C_b^n  = & 
\begin{bmatrix}
cos(\theta)cos(\psi) & -cos(\phi)sin(\psi)+sin(\phi)sin(\theta)cos(\psi) &  sin(\phi)sin(\psi)+cos(\phi)sin(\theta)cos(\psi) \\
cos(\theta)sin(\psi) & cos(\phi)cos(\psi)+sin(\phi)sin(\theta)sin(\psi) & -sin(\phi)cos(\psi)+cos(\phi)sin(\theta)sin(\psi)\\
-sin(\theta) & sin(\phi)cos(\theta) & cos(\phi)cos(\theta) 
\end{bmatrix}
\end{align}
Where $\psi$, $\theta$ and $\phi$ are the Euler angles as described earlier. Expressing the matrix above in a more compact form.
\begin{align}
C_b^n = &
\begin{bmatrix}
c_{11} && c_{12} && c_{13}\\
c_{21} && c_{22} && c_{23} \\
c_{31} && c_{32} && c_{33}
\end{bmatrix}
\label{Eq.C_b_n_compact}
\end{align}
The Euler angles is a transformation from one coordinate frame to another and is defined by three successive rotations about the different axis. Its possible to see the three angles as a set of mechanical gimbals. 
The problem with Euler angles is that when rotating about each axis, its possible to drive two of the three gimbals so they appear parallel to each other this implies that a degree of freedom is lost, this is called a gimbal-lock\cite{nonlinear}. To resolve this issue its possible to use quaternion attitude representation instead, as Euler angels the representation allows transformation between one coordinate frame to another, but the difference is that the transformation is done in a single rotation, instead of three about a vector defined in the reference frame. The \gls{dcm} using quaternion is defined such that
\begin{align}
C_b^n & =
\begin{bmatrix}
(q_1^2 + q_2^2 - q_3^2-q^4) && 2(q_2q_3 - q_1q_4) && 2(q_2q_4 + q_1q_3) \\
2(q_2q_3 - q_1q_4) && (q_1^2 - q_2^2 + q_3^2-q^4) && 2(q_3q_4 - q_1q_2) \\
2(q_2q_4 - q_1q_3) && 2(q_3q_4 + q_1q_2) && (q_1^2 - q_2^2 - q_3^2+q^4)
\end{bmatrix}
\end{align}
Where $q_1$, $q_2$, $q_3$ and $q_4$ can be derived using the Euler angles from equation \eqref{Eq.C_b_n_compact}.

\begin{align*}
q_1 =& \frac{1}{2}(1+c_{11} + c_{22} + c_{33})^{0.5} \\
q_2 =& \frac{1}{4q_1}(c_{32} - c_{23})\\
q_3 =& \frac{1}{4q_1}(c_{13} - c_{31})\\
q_4 =& \frac{1}{4q_1}(c_{21} - c_{12})\\
\end{align*}

The angular velocity of the $e$-frame with respect to the $i$-frame projected onto the $e$-frame is given as
\begin{equation}
\bar{\omega}_{ie}^e = 
\begin{bmatrix}
0 & 0 & \omega_e
\end{bmatrix}^T
\end{equation}
Where $\omega_e$ is the angular velocity of the Earth and has a value of
$7.2921158 \times 10^{-5}~\textrm{rad/s}$\cite{nonlinear}. Using the projection matrix equation \eqref{Cosine_1} its possible to project $\bar{\omega}_ {ie}^i$ onto the $n$-frame
\begin{align}
\bar{\omega}_{ie}^n=C_e^n\bar{\omega}_{ie}^e=
\begin{bmatrix}
\omega_e cos(\varphi) & 0 & -\omega_e sin(\varphi)
\end{bmatrix}^T
\label{omega_ie}
\end{align}
$\bar{\omega}_{en}^n$ represents the turn rate of the $n$-frame with respect to the $e$-frame its called the transport rate and may be expressed as the rate of change of latitude and longitude as follows
\begin{align}
\bar{\omega}_{en}^n=
\begin{bmatrix}
\dot{\lambda}cos(\varphi) & -\dot{\varphi} & -\dot{\lambda}sin(\varphi)
\end{bmatrix}^T
\label{omega_en}
\end{align}
Where $\dot{\lambda}=v_e/(R_N+h)cos(\varphi)$ and $\dot{\varphi}=v_n/(R_E+h)$, here we assume the Earth to be an ellipsoid and that there are no variations in Earth's gravitation depending on where the user is on the ellipsoid. $R_N$ is the meridian radius of curvature and defined as $R_N=R_0(1-e^2)/(1-e^2sin^2\varphi)^{3/2}$\cite{nonlinear}. $R_E$ is the transverse radius of curvature and defined as $R_E=R_0/(1-e^2sin^2\varphi)^{1/2}$. Where $R_0$ is the length of the semi-major axis and has a constant value of $6356752.3142~\textrm{m}$, $e$ is the major eccentricity of the ellipsoid and has a constant value of $0.081819$, $\varphi$ is the current latitude in radians, $v_N$ and $v_E$ is the velocity in north and east direction, respectively and $h$ is the height above the surface of the Earth. Then Rewriting equation \eqref{omega_en} with the new expressions
\begin{align}
\bar{\omega}_{en}^n=
\begin{bmatrix}
v_e/(R_E+h) & -v_n/(R_N+h) & -v_e tan(\varphi)/(R_N+h)
\end{bmatrix}^T \label{omega_en_ny}
\end{align}
Now the turn rate of the $n$-frame with respect to $i$-frame, $\bar{\omega}_{in}^n$ can be obtained by adding equations \eqref{omega_ie} and \eqref{omega_en_ny} together.
\begin{align}
\bar{\omega}_{in}^n=
\begin{bmatrix}
\omega_e cos(\varphi) + v_e/(R_E+h) & v_n/(R_N+h) & -\omega_e sin(\varphi) + v_e tan(\varphi)/(R_N+h)
\end{bmatrix}^T
\label{Eq.omega_in}
\end{align}

\noindent Now equation \eqref{Eq.omega_in} is a function dependent both on velocity and position.

\subsection{Inertial Navigation Equation}
Describing the position of the dinghy in the $n$-frame is done by
\begin{align}
\bar{r}^n=
\begin{bmatrix}
\varphi & \lambda & h
\end{bmatrix}^T
\end{align}
Since velocity is described as the rate of change of its position with respect to a frame of reference and is a function of time, the velocities in the north, east and down can be expressed as\cite{nonlinear}
\begin{align}
\begin{bmatrix}
v_N \\
v_E \\
v_D
\end{bmatrix}
=
\begin{bmatrix}
(R_E+h) & 0 & 0 \\
0 & (R_N+h)cos(\varphi) & 0\\
0 & 0 & -1
\end{bmatrix}
\begin{bmatrix}
\dot{\varphi}\\
\dot{\lambda}\\
\dot{h}
\end{bmatrix}
\label{Eq.v_n1}
\end{align}
Where $\dot{-}$ symbolizes the first derivative with respect to time. Thus, $\dot{\varphi}$, $\dot{\lambda}$ and $\dot{h}$ can be derived by rewriting equation \eqref{Eq.v_n1} as
\begin{align}
\begin{bmatrix}
\dot{\varphi}\\
\dot{\lambda}\\
\dot{h}
\end{bmatrix}
=
\underbrace{\begin{bmatrix}
\frac{1}{(R_E+h)} & 0 & 0 \\
0 & \frac{1}{(R_N+h)cos(\varphi)} & 0\\
0 & 0 & -1
\end{bmatrix}}_{D^{-1}}
\begin{bmatrix}
v_N \\
v_E \\
v_D
\end{bmatrix}
\label{Eq.v_n}
\end{align}
\noindent Thus the dynamics describing the system can be expressed as
\begin{align}
\dot{\bar{r}}_n = & D^{-1}v_n
\label{Eq.r_n_t}\\
\dot{\bar{v}}_n = & C_b^n \bar{f}^b-(2\omega_{ie}^n+\omega_{en}^n) \times \bar{v}_n +\bar{g}^n
\label{Eq.v_n_t}\\
\dot{C}_b^n = & C_b^n(\Omega_{ib}^b - \Omega_{in}^b)
\label{Eq.C_b_n_t}
\end{align}
Where $\bar{f}^b$ is the specific force vector defined as the difference between the true acceleration in space and the acceleration due to gravity and $\bar{g}^n$ is the gravity vector. Where $\Omega$ is the skew matrix of $\omega$, more precise $\Omega_{ib}^b$ the skew-matrix of the outputs of the strapdown gyroscopes and $\Omega_{in}^n$ is the skew-matrix of equation \eqref{Eq.omega_in}. Skew-matrix is defined as the cross product between the vectors.

\subsection{INS mechanization}
Since the INS has to work in discrete time domain, equations \eqref{Eq.r_n_t}, \eqref{Eq.v_n_t} and \eqref{Eq.C_b_n_t} has to be discretized. The sampling time should be seen as a changing variable since it may not be constant instead it will fluctuate around $100~\textrm{Hz}$, this means that $\Delta t_k = \Delta k_{k-1} - t_{k}$, this to improve the accuracy. The discrete dynamics are \cite{non-linear}, Using equations \eqref{Eq.r_n_t}, \eqref{Eq.v_n_t} and \eqref{Eq.C_b_n_t}.

\begin{align}
\bar{r}_{k+1}^n = & \bar{r}_k + 0.5D^{-1}(\bar{v}_k^n + \bar{v}_{k+1}^n)\Delta t
\label{Eq.r_n_d}\\
v_{k+1}^n= & \bar{v}_k + \Delta \bar{v}_{k+1}^n
\label{Eq.v_n_d}\\
\dot{C}_b^n = & C_b^n(\Omega_{ib}^b - \Omega_{in}^b)\Delta t
\label{Eq.C_b_n_d}
\end{align}
where 
\begin{equation}
\Delta \bar{v}_{k+1}^n = \Delta \bar{v}_f^n - (2\omega_{ie}^n+\omega_{en}^n) \times \bar{v}_n \Delta t +\bar{\gamma}\Delta t
\end{equation}
where $\gamma = [0 \quad 0 \quad 9.8123]$.

The Navigation frame Inertial Navigation System can now be seen in \autoref{Fig:body_frame}, Where its possible to examine all the steps which were derived earlier, from the \gls{imu} to the output.
\begin{figure}[H]
\centering

\captionsource{The Intertial Navigation block diagram.}{\url{https://forum.pololu.com/t/ahrs-system-and-inertial-navigation-system/11501}}
\end{figure}

\section{Implementation of Sensor Fusion Using a Kalman Filter.}
\subsection{Perturbation Analysis}
Since the differential equations describing velocity, position, and the attitude, \gls{dcm} are non-linear, utilize a perturbation series to minimize the errors \cite{pertubation}.
\begin{equation}
\hat{r}^n =r^n+\delta r^n
\label{Eq.per_r}
\end{equation}
\begin{equation}
\hat{v}^n =v^n+\delta v^n
\label{Eq.per_v}
\end{equation}
\begin{equation}
\hat{C}_b^n = (I-E^n)C_b^n
\label{Eq.per_c}
\end{equation}
Where $E^n$ is the skew matrix and given as
\begin{align}
\begin{bmatrix} 
0 && -e_D && e_E \\
e_D && 0 && -e_N \\
-e_E && e_N && 0
\end{bmatrix}
\end{align}
Where $\hat{}$ is the computed values, $\delta$ and $e_{NED}$ are the errors in North, East and upward direction, respectively.

\subsubsection{Error Dynamics Position}
Perturbing equation \eqref{Eq.per_r}, the linearized position is obtained since the position dynamics is a function of both position and velocity, the position error dynamics is obtained as
\begin{equation}
\delta \dot{\bar{r}}^n = F_{rr}\delta \bar{r}^n + F_{rv}\delta \bar{v}^n
\end{equation}

\noindent Where
\begin{align}
F_{rr} &=
\begin{bmatrix}
0 && 0 && \frac{-v_N}{(M+h)^2}\\
\frac{v_E sin(\varphi)}{(N+h)cos^2(\varphi)} && 0 && \frac{-v_E}{(N+h)^2cos(\varphi)} \\
0 && 0 && 0
\end{bmatrix}
\label{Eq.Frr}
\end{align}
and
\begin{align}
F_{rv} &=
\begin{bmatrix}
\frac{1}{(M+h)} && 0 && 0\\
0 && \frac{1}{(N+h)cos(\varphi)} && 0 \\
0 && 0 && -1
\end{bmatrix}
\label{Eq.Frv}
\end{align}
\subsubsection{Error Dynamics Velocity}
The same is used when deriving the perturbation for the velocity, equation \eqref{Eq.per_v}, here, velocity is described by forces and gravity acting on the dinghy. Using equation \eqref{Eq.v_n_t}, and perturbation equation \eqref{Eq.per_v}, the following is obtained\cite{nonlinear}
\begin{equation}
\delta \dot{\bar{v}}^n = \bar{v}_n \times \underbrace{(2\delta \bar{\omega}_{ie}^n+ \delta \bar{\omega}_{en}^n)}_{I}+\delta \bar{g}^n -\underbrace{(2\bar{\omega}_{ie}^n + \bar{\omega}_{en}^n)}_{II}\times \delta \bar{v}^n + (\bar{f}^n\times) e^n +C_b^n\delta \bar{f}^n
\label{Eq.delta_v}
\end{equation}
where $II$ is expressed as follow, using equation \eqref{Eq.omega_in}
\begin{align}
2\bar{\omega}_{ie}^n + \bar{\omega}_{en}^n = 
\begin{bmatrix}
2\omega_e cos(\varphi) + \frac{v_E}{(N+h)} \\
\frac{-v_N}{(M+h)} \\
-2\omega_e sin(\varphi) - \frac{v_E tan(\varphi)}{(N+h)}
\end{bmatrix}
\label{Eq.II}
\end{align}
Now perturbing $I$ with $II$, using equations \eqref{omega_en} and \eqref{Eq.omega_in}, the following is obtained
\begin{align}
2\delta \bar{\omega}_{ie}^n+ \delta \bar{\omega}_{en}^n =
\delta \Omega_r\delta \bar{r}^n + \delta\Omega_r\delta\bar{v}^n
\end{align}
where
\begin{align}
\delta\Omega_r = 
\begin{bmatrix}
-2 \omega_e sin(\varphi) && 0 && \frac{-v_E}{(N+h)^2}\\
0 && 0 && \frac{v_N}{(M+h)^2}\\
2 \omega_e cos(\varphi)-\frac{v_E}{(N+h)cos^2(\varphi)} && 0 && \frac{v_E tan(\varphi)}{(N+h)^2}
\end{bmatrix}
\label{Eq.Omega_r}
\end{align}
and
\begin{align}
\delta\Omega_v = 
\begin{bmatrix}
0 &&  \frac{-1}{(N+h)} && 0\\
\frac{-1}{(M+h)} && 0 && 0\\
0 && \frac{-tan(\varphi)}{(N+h)} && \frac{v_E tan(\varphi)}{(N+h)^2}
\end{bmatrix}
\label{Eq.Omega_v}
\end{align}
Then calculating the first term on the left side of equation \eqref{Eq.delta_v}, using equations \eqref{Eq.Omega_r} and \eqref{Eq.Omega_v}
\begin{align}
\bar{v}^n\times(2\delta \bar{\omega}_{ie}^n+\delta \bar{\omega}_{en}^n) = 
\bar{v}^n \times \delta\Omega_r\delta\bar{r}^n +\bar{v}^n\times\delta\Omega_v\delta\bar{v}^n
\end{align}
Then expressing equation \eqref{Eq.delta_v} as
\begin{equation}
\delta\bar{v}^n = F_{vr}\delta\bar{r}^n + F_{vv}\delta\bar{v}^n + (\bar{f}^n	\times)\bar{e}^n + C_n^b\delta \bar{f}^b
\end{equation}
Expressing $F_{vr}$ and $F_{vv}$ in matrix notation
\begin{align}
F_{vr} = 
\begin{bmatrix}
-2v_E\omega_e cos(\varphi)-\frac{v_E^2}{(N+h)cos^2(\varphi)} && 0 && \frac{-v_N v_D}{(M+h)^2} + \frac{v_E^2 tan(\varphi)}{(N+h)^2} \\
2\omega_e(v_N cos(\varphi)-v_D sin(\varphi)) + \frac{v_Ev_N}{(N+h)cos^2(\varphi)} && 0 && \frac{-v_E v_D}{(N+h)^2} - \frac{v_Nv_E tan(\varphi)}{(N+h)^2} \\
2v_E\omega_e sin(\varphi) && 0 && \frac{v_E^2}{(N+h)^2} + \frac{v_N^2}{(M+h)^2} - \frac{2\gamma}{R+h}
\end{bmatrix}
\label{Eq.Fvr}
\end{align}
and
\begin{align}
F_{vv} = 
\begin{bmatrix}
\frac{v_D}{(M+h)} && -2\omega_e sin(\varphi) -2\frac{v_Etan(\varphi)}{(N+h)} && \frac{v_N}{(M+h)} \\
2\omega_e sin(\varphi) +\frac{v_E tan(\varphi)}{(N+h)} && \frac{v_D + v_N tan(\varphi)}{(N+h)} && 2\omega_e cos(\varphi)+ \frac{v_E}{(N+h)} \\
-2\frac{v_N}{(M+h)} && -2\omega_e cos(\varphi) -2\frac{v_E}{(N+h)} && 0
\end{bmatrix}
\label{Eq.Fvv}
\end{align}

\subsubsection{Error Dynamics Attitude}
The output from the \gls{ins} can be expressed using equation \eqref{Eq.C_b_n_t}.
\begin{equation}
\hat{\dot{C}}_b^n = \hat{C}_b^n(\hat{\Omega}_{ib}^b - \hat{\Omega}_{in}^b)
\end{equation}
Then relate the above equation with equation \eqref{Eq.per_c}
\begin{equation}
-\dot{E}^nC_b^n = (I_E^n)C_b^n(\delta\Omega_{ib}^b-\delta\Omega_{in}^b)
\end{equation}
Expressing $\dot{E}^n$ by is self in left-hand side, the equation above can be expressed as
\begin{equation}
\dot{E}^n = -C_b^n(\delta\Omega_{ib}^b-\delta\Omega_{in}^b)
\end{equation}
or in vector form
\begin{equation}
\dot{\bar{e}}^n = -C_b^n(\delta\omega_{ib}^b-\delta\omega_{in}^b).
\label{Eq.error_vec}
\end{equation}

Since we want to express the equation above in its error equation $\delta \bar{\omega}_{in}^b$, the following change can be done $\hat{\bar{\omega}}_{in}^b = \hat{C}_n^b\hat{\bar{\omega}}_{in}^n$ This can be expanded into
\begin{equation}
\bar{\omega}_{in}^b + \delta \bar{\omega}_{in}^b = C_b^n(I+E^n)(\bar{\omega}_{in}^n+\delta\bar{\omega}_{in}^n).
\end{equation}

\noindent Using vector notation for the skew matrix, the equation above can be written as
\begin{equation}
\delta\bar{\omega}_{in}^b = C_n^b [\delta\bar{\omega}_{in}^n + (e^n\times)\bar{\omega}_{in}^n].
\label{Eq.del_omega}
\end{equation}
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

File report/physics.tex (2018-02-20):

\subsection{Point of sail}
A sailboat can increase velocity by catching the wind in the sail at different angles. This is called point of sail and the velocity is dependent on the dinghies displacement from the true wind direction, the wind experienced for a stationary object, where the velocity is a resultant of the force vector created by the wind depending on the alignment of the sail and the direction from the wind direction. There are five different states of point of sail that are divided into degrees away from the true wind origin. These are
\begin{labeling}{alligator}
\item [Luffing] (no propulsive force) angle between 0-30\degree
\item [Close-hauled] (lift) angle between 30-50\degree
\item [Beam reach] (lift) angle 90\degree
\item [Broad reach] (lift–drag) angle aound 135\degree
\item [Running] (drag) angle around 180\degree
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

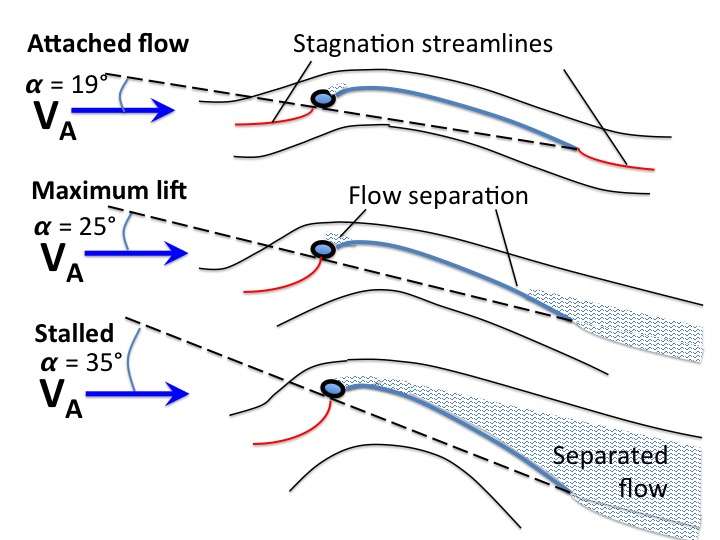
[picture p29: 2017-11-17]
report/Figures/max_lift.jpg

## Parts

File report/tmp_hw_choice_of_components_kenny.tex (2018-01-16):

In order to choose what components would be used for the system, the first consideration was the central controller of the system. Because the system was designed to work in conjunction with an app on a smartphone it was agreed that there is no need for heavy computation on the on-board module. This meant that a \gls{mcu} would be sufficient. Because several of the project members had previous experience with the \gls{st} brand \emph{STM32F411RE} and it has a significant number of GPIO ports, useful peripherals (\gls{i2c}, \gls{spi}, timers, etc) and a high clock speed of up to $100~\textrm{MHz}$ it was chosen as the core of the on-board module. 

The \emph{STM32F411RE} utilizes the \gls{swd} protocol for programming and debugging, the programmer in this case being the programming section of a \emph{NUCLEO-F411RE} development board configured as a programmer. The \gls{swd} header also provides a \gls{uart} channel to communicate with the \gls{mcu}. However, in the interest of convenience for the developers a \emph{FT232RL} chip was added. The \emph{FT232RL} is a \emph{\gls{usb}-to-\gls{uart}} converter that also allows for the \gls{usb} to act as a power source for the board. This eliminated the need for the prototypes to be connected to a power supply and the programmer at times when they were not necessary, giving the more convenient alternative of a common \gls{usb} cable.  The FT232RL was configured only to provide the communication conversion and the power. There are more features available to the FT232RL but no use was found as the on-board module is not connected to a \gls{usb} port for the majority of its operation. 

In order to communicate with the smartphone in a convenient way the on-board module used a Bluetooth module, the SPBTLE-RF. It was chosen as a compact complete module, eliminating the need for soldering inconvenient components and designing \gls{pcb} antennas, and because ST Microelectronics provide official libraries for the \emph{STM32F411RE-to-SPBTLE-RF} interface. 

One of the primary functions that the system had to provide was velocity. The velocity is derived from the position of the boat as measured with \gls{gps}. This necessitated a \gls{gps} module. The project group from the previous year had thought the same thing, and among the remains of their project was a \emph{A2235-H} module. The \emph{A2235-H} module fit the requirements of the project, as it provided circa 1Hz update rate with sub-meter precision in reasonable conditions, all within a compact form factor. It did however have some requirements on how it could be initialized, otherwise risking corruption of the \gls{gps} modules firmware. 

The second primary function the board was supposed to provide was the ability to tell the boats orientation. The common Madgwick method discussed later relies on the use of an accelerometer, magnetometer and gyroscope in conjunction. Because the \gls{mcu} had already been decided we looked for compatible development boards that had the required components and ideally also support libraries. Having found the \emph{NUCLEO-1KS01A2} that satisfies this, the components were chosen from the development board to be able to reuse already written code. 

For magnetometer, the \emph{LSM303AGR} was what was on the development board. It incorporates both an accelerometer and a magnetometer and testing the development board showed it performed good enough for the intended purpose. For the gyroscope, the \emph{LSM6DSL} had once again proved good enough for our purpose, and it too incorporated an accelerometer, possibly allowing for additional filtering possibilities in the future. 

During the course of the project we considered two changes to the choice of components. One was to change from the \emph{LSM303AGR} to the \emph{LSM303C} because of apparent lack of availability, but we found another place to get the already chosen part. The second change we considered was to replace the \emph{LSM6DSL} and \emph{LSM303AGR} with the \emph{LSM9DS1}, which incorporates the magnetometer, accelerometer and gyroscope in a single package to minimize the need to solder inconvenient packages, but because we could not find any official libraries we decided to not change over, so as to not have to rewrite the entire library by ourselves. 

In addition to the \gls{imu} sensors, the development board also provided two additional sensors: the \emph{HTS221}thermometer and relative humidity sensor, and the \emph{LPS22HB} pressure sensor. These were included in the final design to give room for expansion.

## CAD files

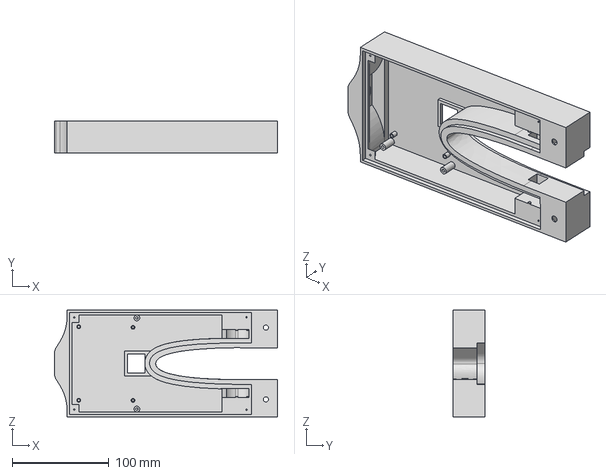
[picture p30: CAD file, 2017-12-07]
Hardware/Mountingstation/Modellplattan.step
230.0 x 32.7 x 110.0 mm

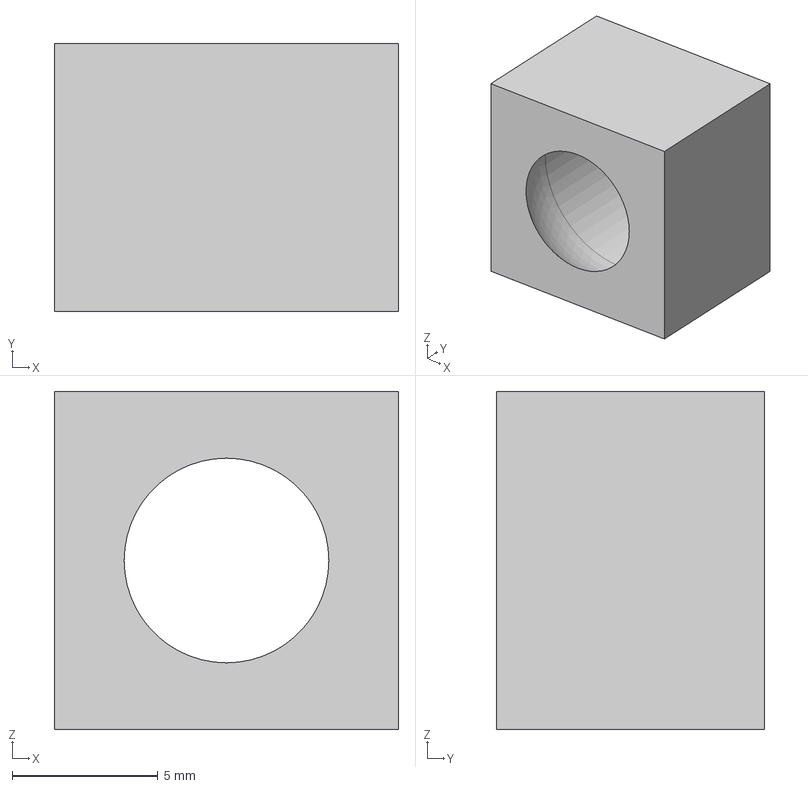
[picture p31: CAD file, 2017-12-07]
Hardware/Mountingstation/Saken till kulorna.step
11.8 x 9.20 x 11.6 mm

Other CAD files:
Hardware/Mountingstation/Plattan från fusion.f3d
Hardware/Mountingstation/hållare till kulorna.f3d

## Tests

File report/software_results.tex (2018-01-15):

\subsection{Results}
\chapterauthor{Theolin, Henrik (Axelsson, Oskar)}
As mentioned the system consists of two parts, the \gls{arm} \gls{mcu} firmware and the Android application.
Reading the sensor data in the \gls{mcu} is done with different frequencies depending on the type of sensor.
This data is computed so that is easily interpreted by the Android application.

Communication is done by the Bluetooth GATT protocol which allows the data to be sent with unique service ids to identify what type of data is sent, this also makes it possible for the data to be sent at different frequencies matching the sensor readings.
The Android application is designed for simple usage and can only be connected to a device named \emph{SailorAid}.

For more flexible usage the feedback from the sensor reading can be acquired in multiple ways.
The feedback can be received visually, by audio and by vibrations, it is also possible to close the screen and still be able to receive feedback.
The logging of data is done at the same frequency as it is received by the Bluetooth protocol.

The resulting system is created for an easy to use experience that would effortlessly be turned on and connected.

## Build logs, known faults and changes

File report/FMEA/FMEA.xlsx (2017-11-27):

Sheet: FMEA
 |  | vad som hänt | vad som påverkats |  | vad som orsakat
Category | FUNCTION | Potential Failure Mode | Potential Effect(s) of Failure | S | Potential Cause(s) of Failure | O | Current Process Controls | D | RPN | Recommended Action(s)
Mechanical | Functional System | Loss of part | Incomplete system | 5 | Part lost from mounting | 2 | Sufficient mounting | 1 | 10
 |  | Water enter housing | Shortages | 4 | Leakage in boxes or sensors | 2 | Waterproofing | 4 | 32 | Make sure housing is waterproof
 | Centerboard mobility | Loose part | Centerboard might get stuck | 3 | Forces are too big for the mounting to hold | 1 | Sufficient mounting | 1 | 3
Electronics | Sensor readings | Water enter housing | No readings or bad readings from sensors | 4 | Shortage | 2 | None atm but software detection could be implemented | 4 | 32 | Make sure housing is waterproof
 |  | Loss of part |  | 4 | Open circuit | 2 | None atm but software detection could be implemented | 2 | 16 | Make sure the sensor is correctly cinched
 |  | Water blocking distance sensor |  | 3 | Water interference | 1 | None | 4 | 12 | Can't do much
 |  | Missreading of optical sensor |  | 3 | Misaligned sensors | 3 | Sufficient mounting | 4
 | Battery | Water entering housing | Module power down | 5 | Short circuit | 2 |  | 1 | 10 | Make sure housing is waterproof
 |  |  | Component damaged | 5 |  | 2 |  | 1 | 10 | Make sure housing is waterproof
 | Functional System | Connector disconnects | Electronic malfunction | 4 | Vibrations | 2 | Use of pinheaders and cable connectors | 4 | 32 | Improve rigidness of connectors
 |  | Loss of wireless communication | Loss of system functionality | 5 | BT hardware connection loss/short | 2 | Verify system function beforehand | 2 | 20
 |  | MCU failure | MCU rebooting | 4 | Unexpected voltage drop | 1 | Banking capacitors | 5 | 20
Software | Logging | Corruption of log-files | Display and analysis of data | 2 | Unknown | 2 | None | 3 | 12 | Re-logg data
 |  |  |  | 2 |  | 1 |  | 1 | 2 | Insert SD-card
 |  |  |  | 2 |  | 1 |  | 1 | 2 | Find SD-card
 | Sleep mode | No wake-up | Module Failure | 4 | No more reading of data | 2 | Wake-up by interrupt | 2 | 16 | Restart
 |  |  |  | 4 | No connection to module | 2 | Retry in SW | 2 | 16 | Restart
 | User Interface | Software bugs | Crippled functionality | 1 | Programming methodology | 1 | None | 1 | 1 | Restart
 | Functional System | Battery discharge | Module | 5 | Power failure | 1 | None | 2 | 10 | Load/Change battery
 |  | Short circuit |  | 5 |  | 1 | HW detection and SW warning | 4 | 20 | Detect in Software and warn user
 |  | Crash |  | 5 | Crash | 1 | None | 2 | 10 | Restart Application
 | Application | Crash | Application | 5 | Crash | 1 | None | 1 | 5 | Restart Application
 |  | Missaligned data | Data presentation | 3 | Signal interference | 1 | None | 1 | 3 | Notify user
 |  |  |  | 1 | Bad sensor reading | 1 | None | 4 | 4 | Notify user
 |  |  |  | 3 | Short circuit | 1 | None | 4 | 12 | Notify user
 |  |  |  | 3 | Open circuit | 1 | None | 4 | 12 | Notify user
 |  | Phone battery depleted | Application | 5 | Phone battery depleted | 1 | Implemented in Phone | 1 | 5 | Notify user
Manufacturing & Integration | Centerboard performance | Damaged centerboard while mounting | Centerboard damaged | 3 | Integration of system | 1 | Careful modification of centerboard | 3 | 9
 | Waterproofing | Leakage | Water entering housing | 5 | Housing leakage | 2 | Waterproofing | 3 | 30
 |  |  |  | 4 | Bad application of silicone | 2 | Use proper material | 4 | 32
 |  |  |  | 4 | Bad seal for housing or sensors | 2 | Use good sealing | 4 | 32
Planning | Access to soldering lab | No access | No soldering | 5 | Cards not granted access | 1 | Communication | 1 | 5
 |  |  |  | 2 | Lab occupied | 2 | Planning | 1 | 4
 | Team availability | Absent Teammate | One part will have limited or no progress | 2 | Illness | 1 | Eat vegetables | 1 | 2
 |  |  |  | 3 | Lack of communication | 2 | Communication | 3 | 18
 |  |  |  | 3 | Conflict | 1 | Team building | 1 | 3
 | Tools are not available | Loss of license or such | LabView | 1 | Unknown | 1 | Use another program | 1 | 1
 |  |  | Atollic TrueStudio | 3 |  | 1 | Use another IDE | 1 | 3
 |  |  | Cube | 2 |  | 1 | Manually track pin use | 1 | 2
 |  |  | Eagle | 2 |  | 1 | Use KiCAD | 1 | 2
 |  |  | BitBucket | 4 |  | 1 | Keep backups | 1 | 4
 | Funding is insufficient | Unknown | Project | 4 | Too expensive | 1 | Look for cheaper components | 1 | 4
 |  |  |  | 5 | No funding | 1 | Keep project on track | 1 | 5
 | Experience is insufficient | Inexperienced team members | Part(s) of project | 4 | Necessary expertise in team is insufficient | 4 | Study hard | 3 | 48
 | Team collaboration | Inadequate team collaboration | Part(s) of project | 3 | Conflicts | 2 | Compromise | 1 | 6
 |  |  |  | 3 | Unorganized workload | 2 | Organization | 3 | 18
 |  |  |  | 3 | Inefficient workload | 2 | Organization | 4 | 24
 |  |  |  | 4 | Internal communication issues | 2 | Meetings | 4 | 32

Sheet: FÖRKLARING
nya | SEVERITY(S) | OCCURENCE(O) | DETECTION(D) | RISK PRIORITY NUMBER(RPN)
1 | Negligible | Very Rarely | Not able to miss it | 1: Works as intended
2 | Notable |  | Indicated by interface | 8: Look in to this, maybe fix
3 | Major | Sometimes | Observable by the naked eye | 27: Must fix (lower priority)
4 | Critical | Often | Observable by inspection | 64: Must fix (higher priority)
5 | Catastrophic | Always | Undetectable | 125: CRITICAL ERROR FIX IMMEDIATELY
gamla | SEVERITY(S) | OCCURENCE(O) | DETECTION(D)
 | Nothing is effected | Never | Not able to miss it | 1 DOTN CARE OR NOT VERY IMPORTANT
 | Unwanted Behavior | Rarely | Indicated by interface | 8: LOOK IN TO THIS, MABY FIX
 | Broken equipment | Somtimes | Observable by the naked eye | 27: MUST FIX
 | Injury | Often | Observable by inspection | 64 : MUST FIX
 | Lethal | Always | Undetectable | 125 : HOLY MOTHER FUCKER

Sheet: Blad2
Main Board "Active" | Loss of Power | No more data from this node | Battery shortcut
 |  |  | Battery empty
 | Loss of signal due to shortcut | No more data from this sensor | Water leak
 | Loss of signal due to loose cable | No more data from this sensor | Tear
Node "Active" | Loss of Power | No more data from this node | Water Leak
 |  |  | Empty Battery
 | Loss of physical part | No more data from this node, and potential loss of original physical functions.
 | Loss of signal due to shortcut | No more data from this sensor | Water leak
 | Loss of signal due to loose cable | No more data from this sensor | Tear
 | Pressure sensor out of position | Inaccurate data from pressure sensor | Forces too big for mounting
Inter-node Communication | Loss of packet | One data-point will miss some data | Miss timed sleep
 |  | One node will never report anything.
 | Corrupt packet | One data-point will have incorrect data
Main Board Communication | Loss of slave bluetooth module
 | Loss of Master bluetooth module

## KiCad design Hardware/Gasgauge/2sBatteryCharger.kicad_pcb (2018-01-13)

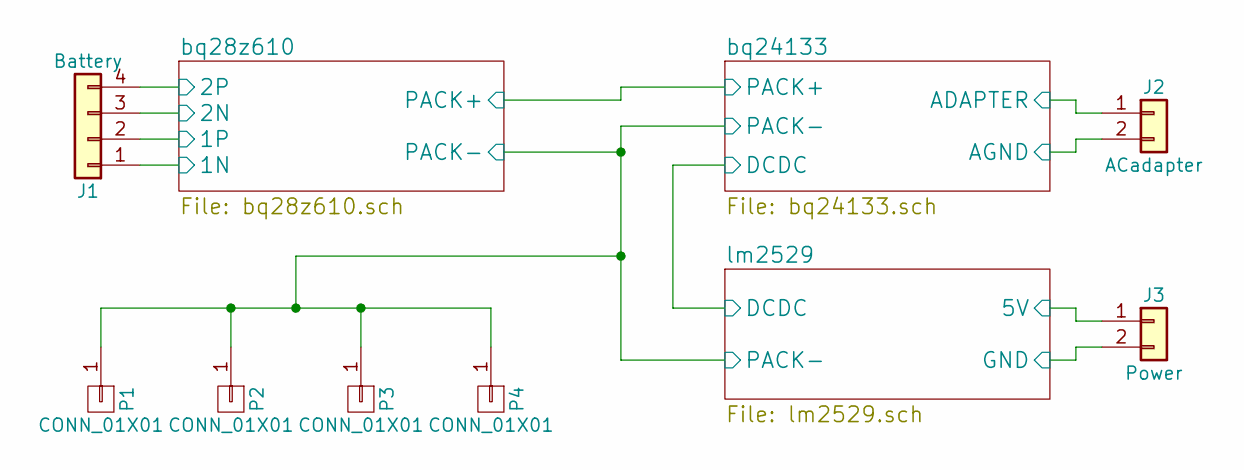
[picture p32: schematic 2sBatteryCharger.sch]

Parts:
J1: Battery; JST_XH_S04B-XH-A_04x2.50mm_Angled
J2: ACadapter; JST_XH_S02B-XH-A_02x2.50mm_Angled
J3: Power; JST_XH_S02B-XH-A_02x2.50mm_Angled
P1, P2, P3, P4: CONN_01X01; MountingHole_3.2mm_M3

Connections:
/bq28z610/1P: J1.2, J1.3; also elsewhere on the board
/bq28z610/2P: J1.4; also elsewhere on the board
/bq24133/ADAPTER: J2.1; also elsewhere on the board
/lm2529/5V: J3.1; also elsewhere on the board
Earth: J2.2; also elsewhere on the board
GND: J1.1; also elsewhere on the board
GNDPWR: J3.2, P1.1, P2.1, P3.1, P4.1; also elsewhere on the board

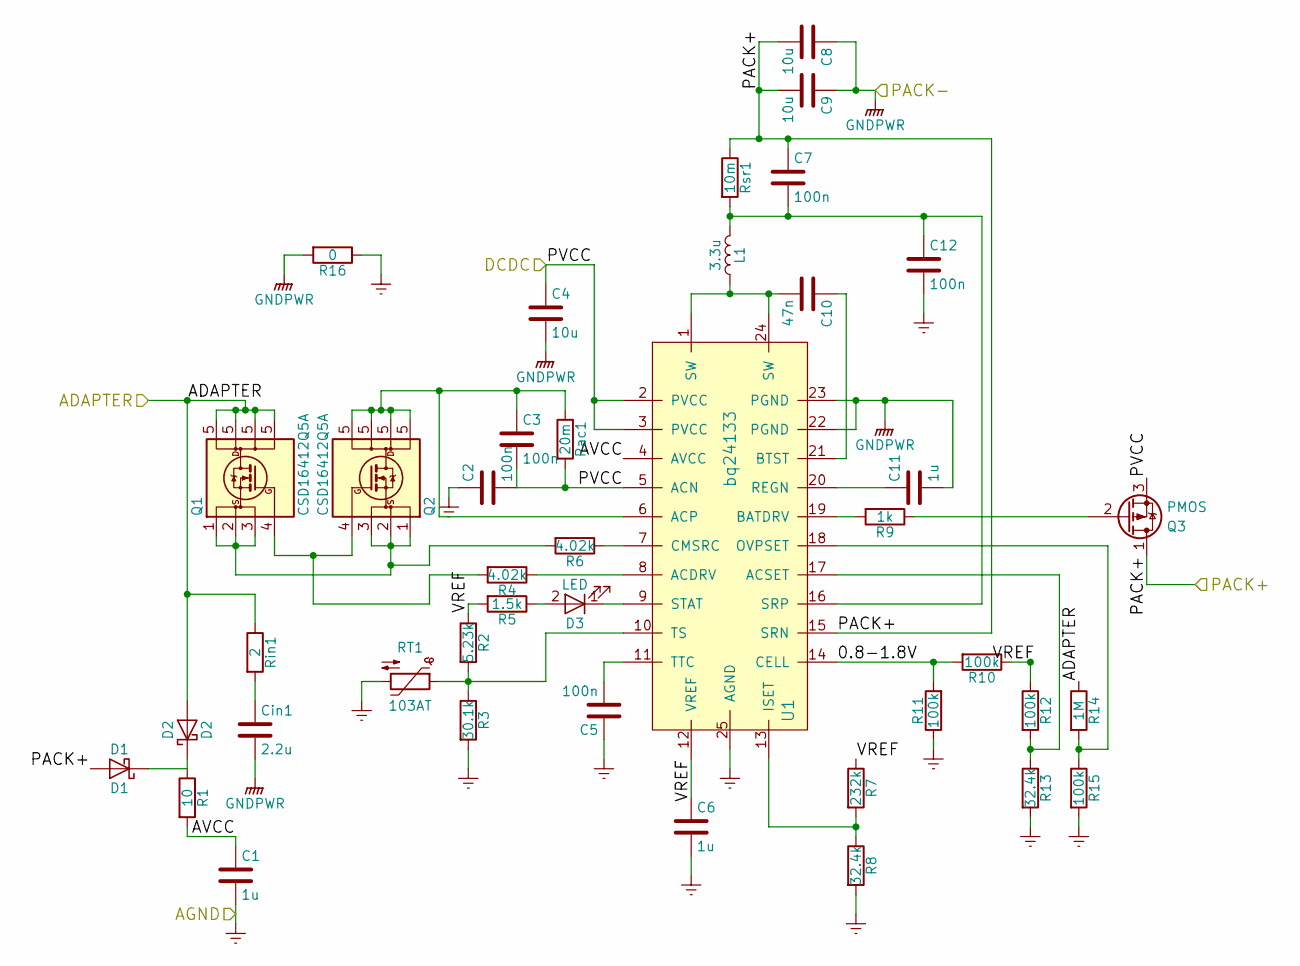
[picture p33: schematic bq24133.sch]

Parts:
C1: 1u; C_0805
C2, C3, C5, C7, C12: 100n; C_0603
C4: 10u; C_1206
C6, C11: 1u; C_0603
C8, C9: 10u; C_1210
C10: 47n; C_0603
Cin1: 2.2u; C_1206
D1: D1; D_SOD-323F
D2: D2; D_SOD-323F
D3: LED; LED_D3.0mm
L1: 3.3u; L_7.3x7.3_H3.5
Q1, Q2: CSD16412Q5A; TDSON-8-1
Q3: PMOS; SOT-23
R1: 10; R_1206
R2: 5.23k; R_0603
R3: 30.1k; R_0603
R4, R6: 4.02k; R_0603
R5: 1.5k; R_0603
R7: 232k; R_0603
R8, R13: 32.4k; R_0603
R9: 1k; R_0603
R10, R11, R12, R15: 100k; R_0603
R14: 1M; R_0603
R16: 0; R_0603
RT1: 103AT; R_Axial_DIN0309_L9.0mm_D3.2mm_P2.54mm_Vertical
Rac1: 20m; R_2512
Rin1: 2; R_2010
Rsr1: 10m; R_2512
U1: bq24133; VQFN-24_5.5x3.5mm_Pitch0.5mm

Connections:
/bq24133/0.8-1.8V: R10.2, R11.2, U1.14 (CELL)
/bq24133/ADAPTER: D2.2 (A), Q1.5 (D), R14.1, Rin1.1; also elsewhere on the board
/bq24133/AVCC: C1.1, R1.2, U1.4 (AVCC)
/bq24133/DCDC: C2.2, C3.2, C4.1, Q3.3 (S), Rac1.2, U1.2 (PVCC), U1.3 (PVCC), U1.5 (ACN); also elsewhere on the board
/bq24133/PACK+: C7.1, C8.2, C9.2, D1.2 (A), Q3.1 (D), Rsr1.1, U1.15 (SRN); also elsewhere on the board
/bq24133/VREF: C6.1, R2.1, R5.2, R7.1, U1.12 (VREF)
Earth: C1.2, C2.1, C5.1, C6.2, C12.2, R3.2, R8.2, R11.1, R13.2, R15.2, R16.1, RT1.2, U1.25 (AGND); also elsewhere on the board
GNDPWR: C4.2, C8.1, C9.1, C11.2, Cin1.2, R16.2, U1.22 (PGND), U1.23 (PGND); also elsewhere on the board
unnamed: C3.1, Q2.5 (D), Rac1.1, U1.6 (ACP)
unnamed: C5.2, U1.11 (TTC)
unnamed: C10.1, U1.21 (BTST)
unnamed: C10.2, L1.1, U1.1 (SW), U1.24 (SW)
unnamed: C11.1, U1.20 (REGN)
unnamed: C7.2, C12.1, L1.2, Rsr1.2, U1.16 (SRP)
unnamed: Cin1.1, Rin1.2
unnamed: D1.1 (K), D2.1 (K), R1.1
unnamed: D3.1 (K), U1.9 (STAT)
unnamed: D3.2 (A), R5.1
unnamed: Q1.1 (S), Q1.2 (S), Q1.3 (S), Q2.1 (S), Q2.2 (S), Q2.3 (S), R6.2
unnamed: Q1.4 (G), Q2.4 (G), R4.2
unnamed: Q3.2 (G), R9.1
unnamed: R2.2, R3.1, RT1.1, U1.10 (TS)
unnamed: R4.1, U1.8 (ACDRV)
unnamed: R6.1, U1.7 (CMSRC)
unnamed: R7.2, R8.1, U1.13 (ISET)
unnamed: R9.2, U1.19 (BATDRV)
unnamed: R10.1, R12.1
unnamed: R12.2, R13.1, U1.17 (ACSET)
unnamed: R14.2, R15.1, U1.18 (OVPSET)

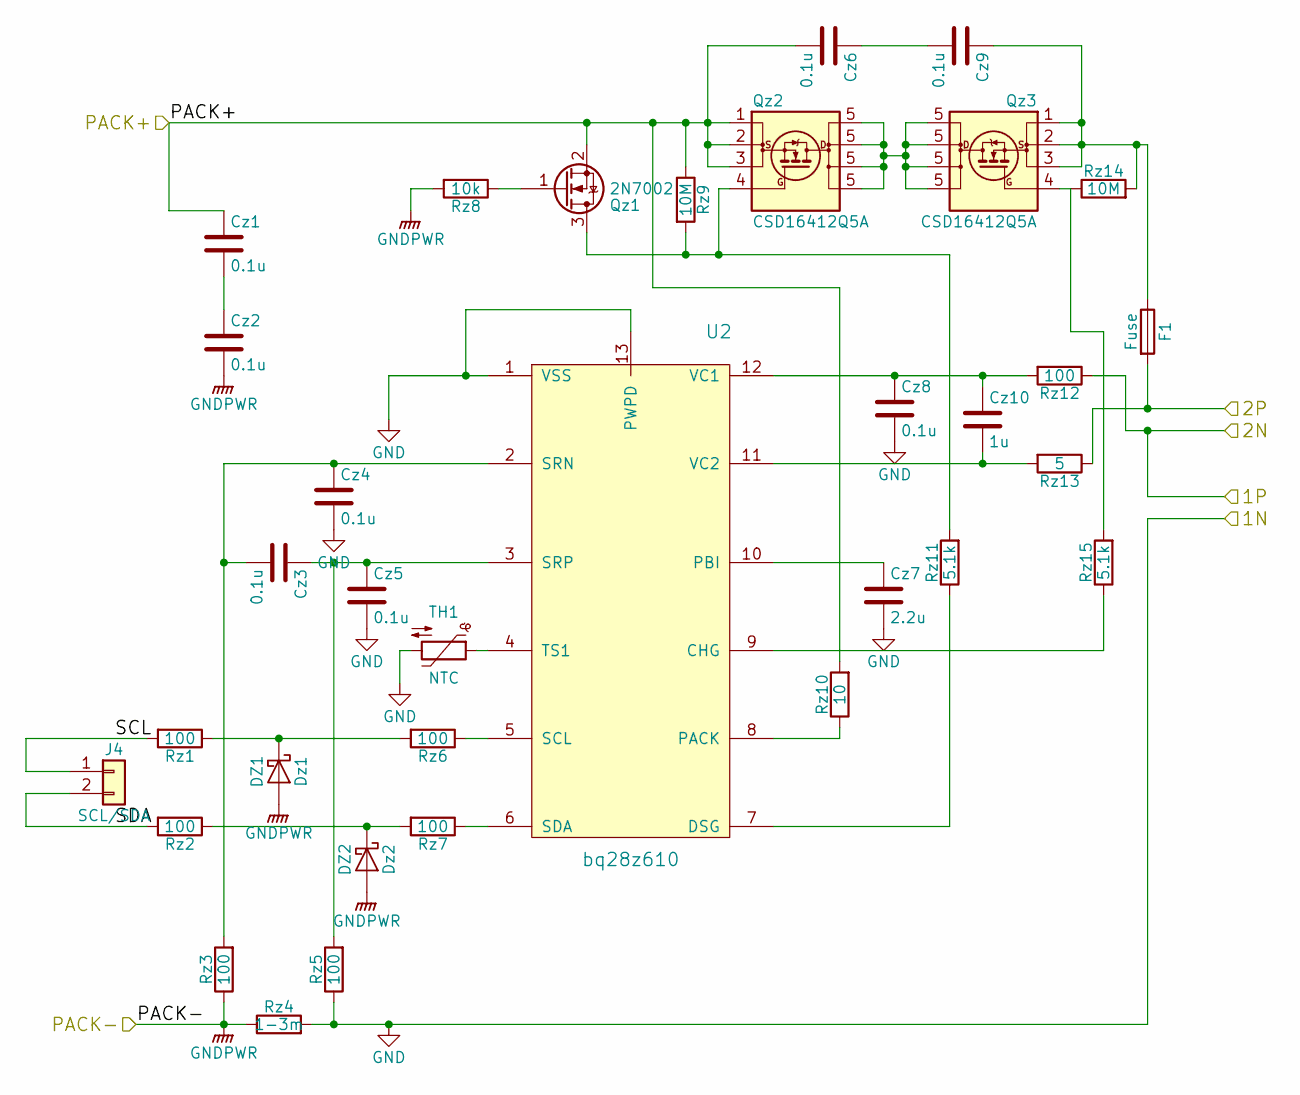
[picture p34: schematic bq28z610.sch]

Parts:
Cz1, Cz2, Cz3, Cz4, Cz5, Cz6, Cz8, Cz9: 0.1u; C_0603
Cz7: 2.2u; C_0603
Cz10: 1u; C_0805_HandSoldering
Dz1: DZ1; D_SOD-323F
Dz2: DZ2; D_SOD-323F
F1: Fuse; Fuseholder5x20_horiz_open_lateral_Type-II
J4: SCL/SDA; JST_XH_S02B-XH-A_02x2.50mm_Angled
Qz1: 2N7002; SOT-23
Qz2, Qz3: CSD16412Q5A; TDSON-8-1_HandSoldering
Rz1, Rz2, Rz3, Rz5, Rz6, Rz7: 100; R_0603
Rz4: 1-3m; R_2512
Rz8: 10k; R_0603
Rz9, Rz14: 10M; R_0603
Rz10: 10; R_0603
Rz11, Rz15: 5.1k; R_0603
Rz12: 100; R_2512
Rz13: 5; R_2512
TH1: NTC; R_Axial_DIN0309_L9.0mm_D3.2mm_P2.54mm_Vertical
U2: bq28z610; Texas_S-PDSO-N12

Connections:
/bq28z610/1P: Rz12.1; also elsewhere on the board
/bq28z610/2P: F1.2, Rz13.1; also elsewhere on the board
/bq28z610/SCL: J4.1, Rz1.2
/bq28z610/SDA: J4.2, Rz2.2
/bq24133/PACK+: Cz1.1, Cz6.2, Qz1.2 (S), Qz2.1 (S), Qz2.2 (S), Qz2.3 (S), Rz9.1, Rz10.2; also elsewhere on the board
GND: Cz4.2, Cz5.2, Cz7.2, Cz8.2, Rz4.2, Rz5.1, TH1.2, U2.1 (VSS), U2.13 (PWPD); also elsewhere on the board
GNDPWR: Cz2.2, Dz1.2 (A), Dz2.2 (A), Rz3.1, Rz4.1, Rz8.2; also elsewhere on the board
unnamed: Cz1.2, Cz2.1
unnamed: Cz3.1, Cz5.1, Rz5.2, U2.3 (SRP)
unnamed: Cz3.2, Cz4.1, Rz3.2, U2.2 (SRN)
unnamed: Cz6.1, Cz9.2
unnamed: Cz7.1, U2.10 (PBI)
unnamed: Cz9.1, F1.1, Qz3.1 (S), Qz3.2 (S), Qz3.3 (S), Rz14.2
unnamed: Cz8.1, Cz10.1, Rz12.2, U2.12 (VC1)
unnamed: Cz10.2, Rz13.2, U2.11 (VC2)
unnamed: Dz1.1 (K), Rz1.1, Rz6.2
unnamed: Dz2.1 (K), Rz2.1, Rz7.2
unnamed: Qz1.1 (G), Rz8.1
unnamed: Qz1.3 (D), Qz2.4 (G), Rz9.2, Rz11.2
unnamed: Qz2.5 (D), Qz3.5 (D)
unnamed: Qz3.4 (G), Rz14.1, Rz15.2
unnamed: Rz6.1, U2.5 (SCL)
unnamed: Rz7.1, U2.6 (SDA)
unnamed: Rz10.1, U2.8 (PACK)
unnamed: Rz11.1, U2.7 (DSG)
unnamed: Rz15.1, U2.9 (CHG)
unnamed: TH1.1, U2.4 (TS1)

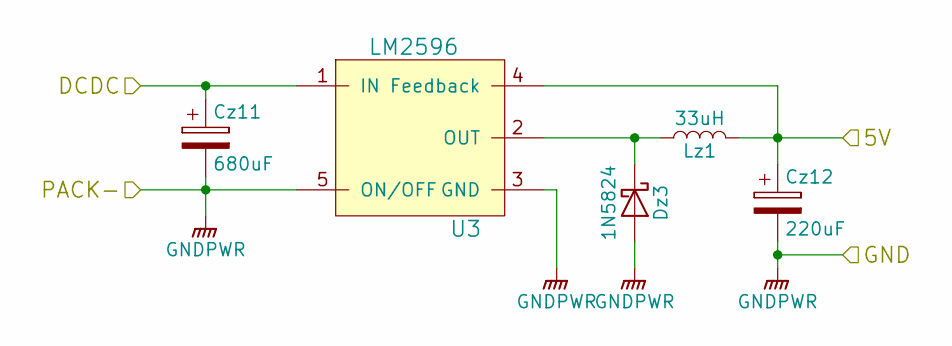
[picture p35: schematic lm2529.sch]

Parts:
Cz11: 680uF; CP_Elec_8x10
Cz12: 220uF; CP_Elec_6.3x5.8
Dz3: 1N5824; D_5W_P10.16mm_Horizontal
Lz1: 33uH; L_12x12mm_h8mm
U3: LM2596; TO-263-5_TabPin3

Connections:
/bq24133/DCDC: Cz11.1, U3.1 (IN); also elsewhere on the board
/lm2529/5V: Cz12.1, Lz1.2, U3.4 (Feedback); also elsewhere on the board
GNDPWR: Cz11.2, Cz12.2, Dz3.2 (A), U3.3 (GND), U3.5 (ON/OFF); also elsewhere on the board
unnamed: Dz3.1 (K), Lz1.1, U3.2 (OUT)

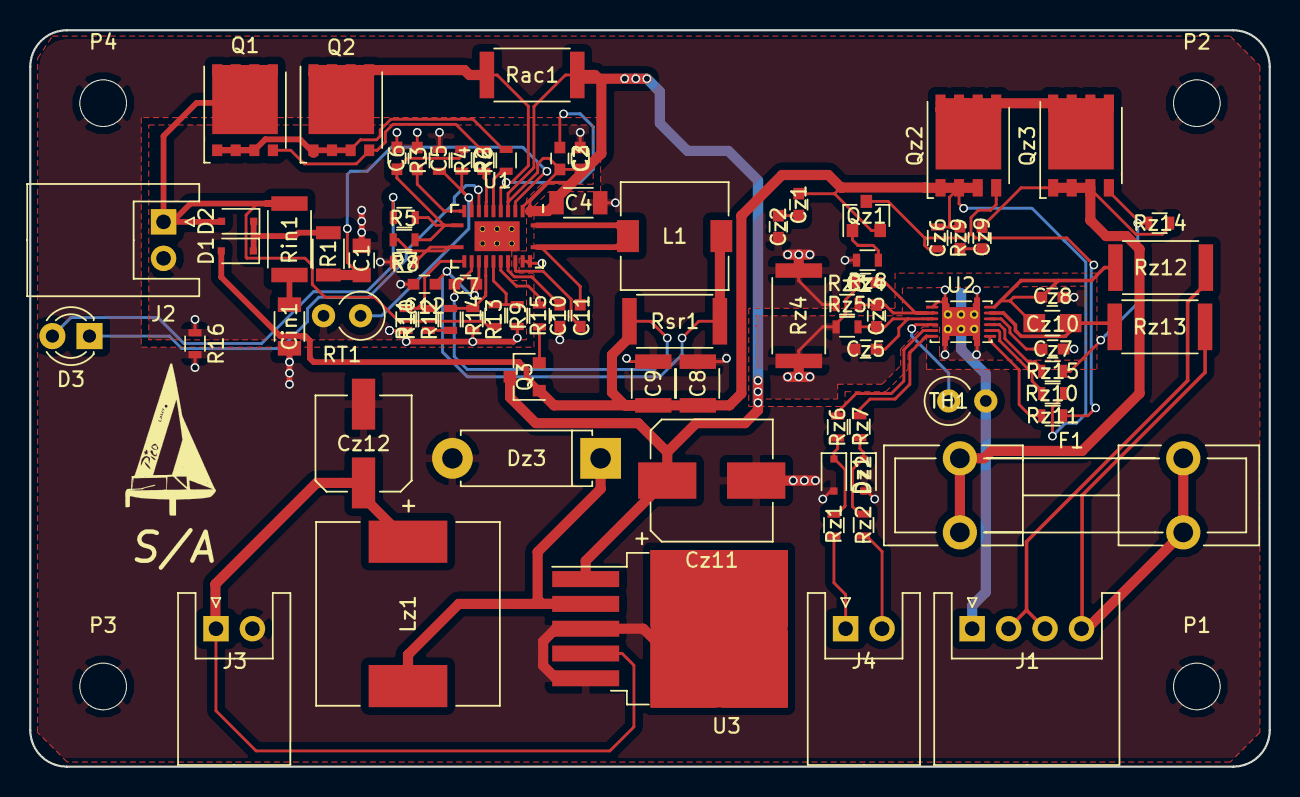
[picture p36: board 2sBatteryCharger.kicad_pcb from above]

Board: 2 copper layers, 85.0 x 50.5 mm, 87 parts (0 on the bottom side), 56 nets.

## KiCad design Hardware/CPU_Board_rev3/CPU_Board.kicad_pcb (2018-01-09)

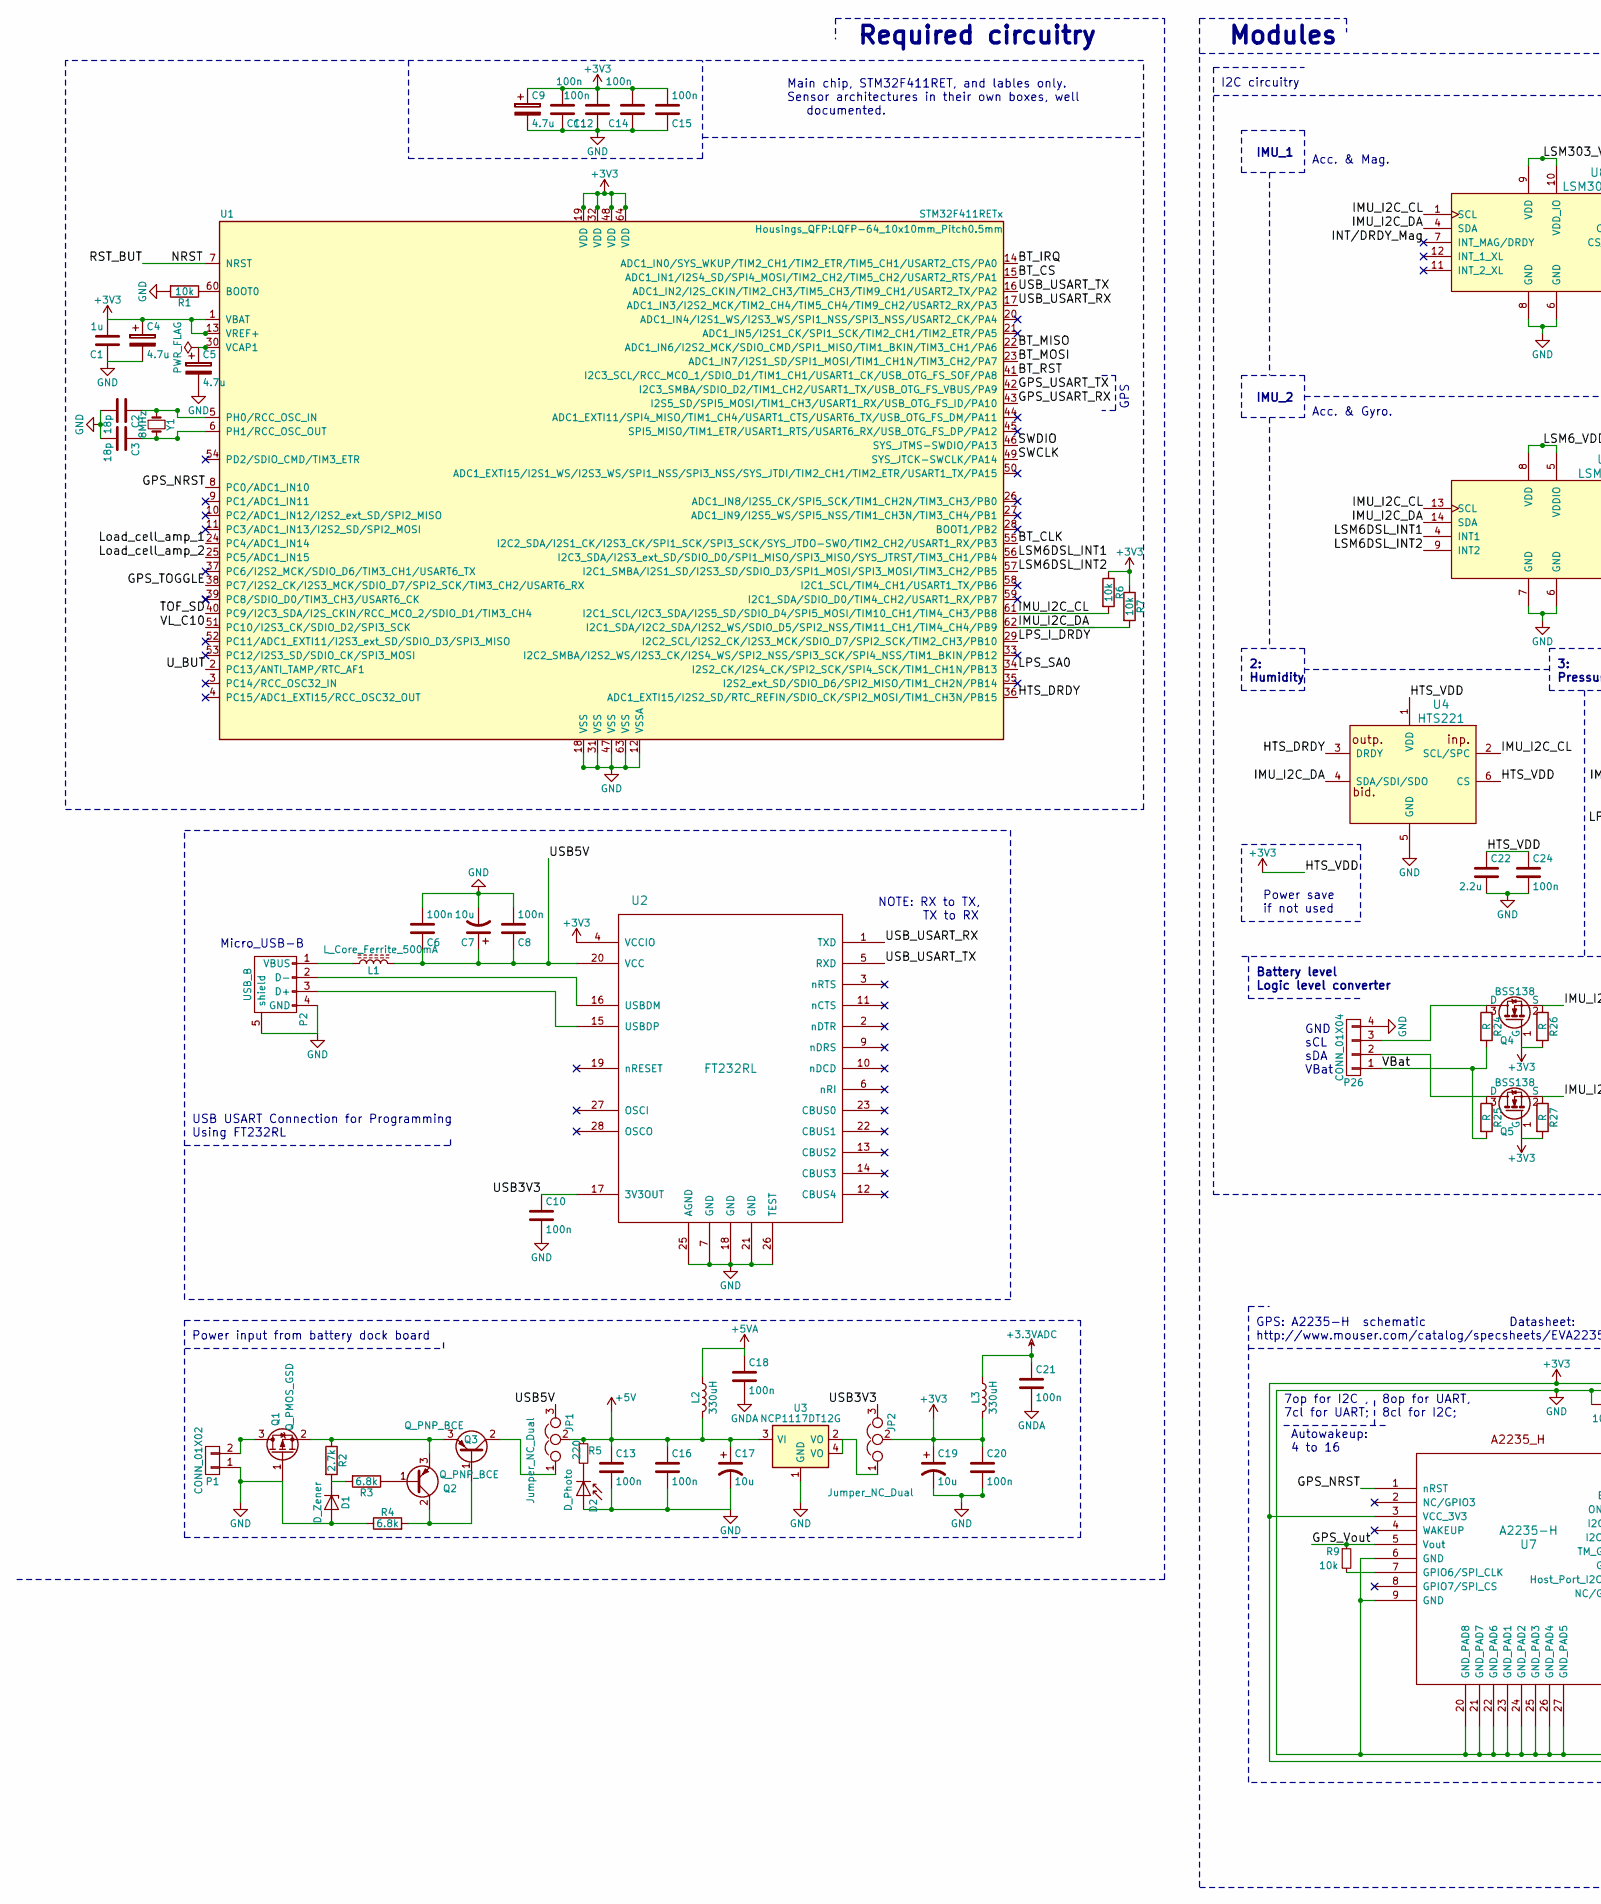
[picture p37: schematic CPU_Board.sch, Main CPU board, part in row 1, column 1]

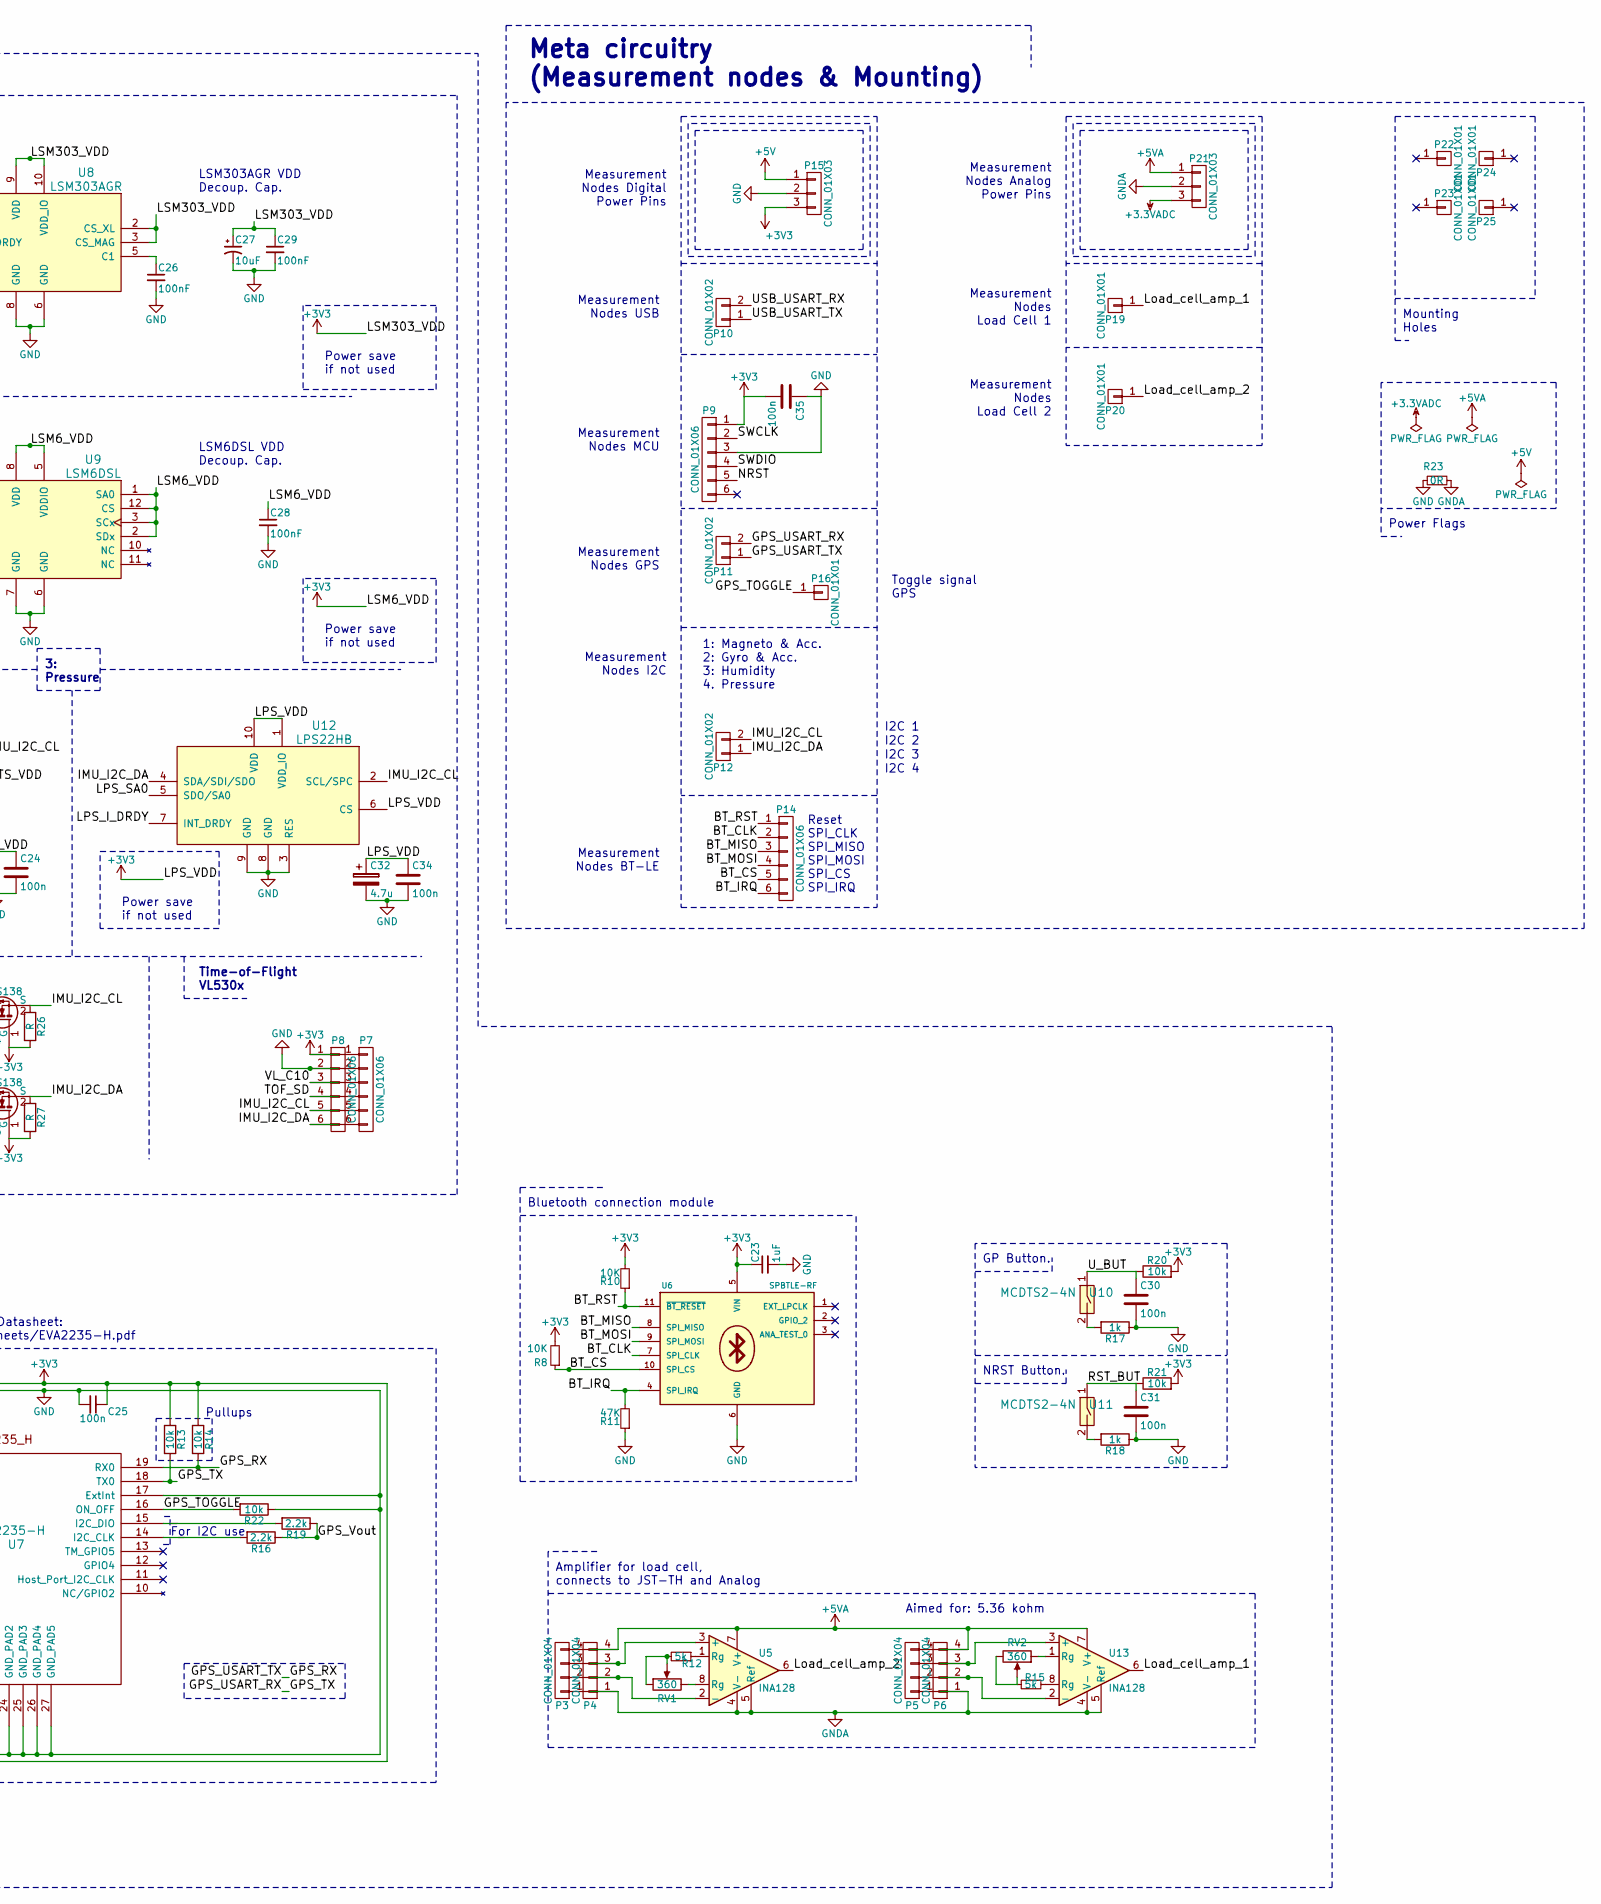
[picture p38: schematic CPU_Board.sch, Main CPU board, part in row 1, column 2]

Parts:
C1: 1u; C_0805_HandSoldering
C2, C3: 18p; C_0805_HandSoldering
C4, C5, C9, C32: 4.7u; CP_Elec_3x5.3
C6, C8, C10, C11, C12, C13, C14, C15, C16, C18, C20, C21, C24, C25, C30, C31, C34, C35: 100n; C_0805_HandSoldering
C7, C17, C19: 10u; CP_Elec_5x5.3
C22: 2.2u; C_0805_HandSoldering
C23: 1uF; C_0805_HandSoldering
C26, C28, C29: 100nF; C_0805_HandSoldering
C27: 10uF; CP_Elec_5x5.3
D1: D_Zener; D_SOD-323
D2: D_Photo; PhotoDiode_SFH205
JP1, JP2: Jumper_NC_Dual; Pin_Header_Straight_1x03_Pitch2.54mm
L1: L_Core_Ferrite_500mA; R_1206_HandSoldering
L2, L3: 330uH; INDUCTOR_V
P1: CONN_01X02; AK300-2
P2: USB_B; USB_Mini-B
P3, P5: CONN_01X04; Pin_Header_Straight_1x04_Pitch2.54mm
P4, P6: CONN_01X04; Connector_JST_S4B-ZR_1x4
P7: CONN_01X06; Socket_Strip_Straight_1x06
P8: CONN_01X06; JST_PH_S6B-PH-K_06x2.54mm_Angled
P9, P14: CONN_01X06; Pin_Header_Straight_1x06_Pitch2.54mm
P10, P11, P12: CONN_01X02; Pin_Header_Straight_1x02_Pitch2.54mm
P15, P21: CONN_01X03; Pin_Header_Straight_1x03_Pitch2.54mm
P16, P19, P20: CONN_01X01; Pin_Header_Straight_1x01_Pitch2.54mm
P22, P23, P24, P25: CONN_01X01; MountingHole_2.2mm_M2_DIN965_NoPad
P26: CONN_01X04; Molex_KK-6410-04_04x2.54mm_Straight
Q1: Q_PMOS_GSD; SOT-23_Handsoldering
Q2, Q3: Q_PNP_BCE; SOT-23_Handsoldering
Q4, Q5: BSS138; SOT-23
R1, R6, R7, R9, R13, R14, R20, R21, R22: 10k; R_0805_HandSoldering
R2: 2.7k; R_0805_HandSoldering
R3, R4: 6.8k; R_0805_HandSoldering
R5: 220; R_0805_HandSoldering
R8, R10: 10K; R_0805_HandSoldering
R11: 47K; R_0805_HandSoldering
R12, R15: 5k; R_0805_HandSoldering
R16, R19: 2.2k; R_0805_HandSoldering
R17, R18: 1k; R_0805_HandSoldering
R23: 0R; R_Axial_DIN0204_L3.6mm_D1.6mm_P5.08mm_Horizontal
R24, R25, R26, R27: R; R_0805_HandSoldering
RV1, RV2: 360; Potentiometer_Trimmer_Bourns_PV36W
U1: STM32F411RETx; LQFP-64_10x10mm_Pitch0.5mm
U2: FT232RL; SSOP-28_5.3x10.2mm_Pitch0.65mm
U3: NCP1117DT12G; SOT-223
U4: HTS221; HLGA-6L_2x2x.9mm_HS
U5, U13: INA128; SOIC-8_3.9x4.9mm_Pitch1.27mm
U6: SPBTLE-RF; ST_SPBTLE
U7: A2235-H; A2235-H_Handsolder
U8: LSM303AGR; LGA-12_2x2mm_P.5mm_HS
U9: LSM6DSL; LGA-14_2.5x3mm_P.5_HS
U10, U11: MCDTS2-4N; SW_SPST_PTS645
U12: LPS22HB; HLGA-10L_2x2mm_P.5mm_HS
Y1: 8MHz; Crystal_SMD_HC49-SD

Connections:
+3.3VADC: C21.1, L3.1, P21.3
+3V3: C1.2, C4.1, C9.1, C11.2, C12.2, C14.2, C15.2, C19.1, C20.1, C22.1, C23.1, C24.1, C25.1, C27.1, C28.1, C29.1, C32.1, C34.1, C35.2, JP2.2, L3.2, P7.1, P8.1, P9.1, P15.3, Q4.1 (G), Q5.1 (G), R6.1, R7.1, R8.2, R10.2, R13.1, R14.1, R20.2, R21.2, R26.2, R27.2, U1.1 (VBAT), U1.13 (VREF+), U1.19 (VDD), U1.32 (VDD), U1.48 (VDD), U1.64 (VDD), U2.4 (VCCIO), U4.1 (VDD), U4.6 (CS), U6.5 (VIN), U7.3 (VCC_3V3), U8.2 (CS_XL), U8.3 (CS_MAG), U8.9 (VDD), U8.10 (VDD_IO), U9.1 (SA0), U9.2 (SDx), U9.3 (SCx), U9.5 (VDDIO), U9.8 (VDD), U9.12 (CS), U12.1 (VDD_IO), U12.6 (CS), U12.10 (VDD)
+5V: C13.1, C16.1, C17.1, JP1.2, L2.2, P15.1, R5.1, U3.3 (VI)
+5VA: C18.1, L2.1, P3.4, P4.4, P5.4, P6.4, P21.1, U5.7 (V+), U13.7 (V+)
/BT_CLK: P14.2, U1.55 (I2C2_SDA/I2S1_CK/I2S3_CK/SPI1_SCK/SPI3_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), U6.7 (SPI_CLK)
/BT_CS: P14.5, R8.1, U1.15 (ADC1_IN1/I2S4_SD/SPI4_MOSI/TIM2_CH2/TIM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), U6.10 (SPI_CS)
/BT_IRQ: P14.6, R11.2, U1.14 (ADC1_IN0/SYS_WKUP/TIM2_CH1/TIM2_ETR/TIM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), U6.4 (SPI_IRQ)
/BT_MISO: P14.3, U1.22 (ADC1_IN6/I2S2_MCK/SDIO_CMD/SPI1_MISO/TI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), U6.8 (SPI_MISO)
/BT_MOSI: P14.4, U1.23 (ADC1_IN7/I2S1_SD/SPI1_MOSI/TIM1_CH1N/TI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), U6.9 (SPI_MOSI)
/BT_RST: P14.1, R10.1, U1.41 (I2C3_SCL/RCC_MCO_1/SDIO_D1/TIM1_CH1/USA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), U6.11 (~BT_RESET~)
/GPS_NRST: U1.8 (PC0/ADC1_IN10), U7.1 (nRST)
/GPS_RX: P11.1, R14.2, U1.42 (I2C3_SMBA/SDIO_D2/TIM1_CH2/USART1_TX/US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), U7.19 (RX0)
/GPS_TOGGLE: P16.1, R22.2, U1.38 (PC7/I2S2_CK/I2S3_MCK/SDIO_D7/SPI2_SCK/T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), U7.16 (ON_OFF)
/GPS_TX: P11.2, R13.2, U1.43 (I2S5_SD/SPI5_MOSI/TIM1_CH3/USART1_RX/US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), U7.18 (TX0)
/GPS_Vout: R9.1, R16.1, R19.1, U7.5 (Vout)
/HTS_DRDY: U1.36 (ADC1_EXTI15/I2S2_SD/RTC_REFIN/SDIO_CK/S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), U4.3 (DRDY)
/IMU_I2C_CL: P7.5, P8.5, P12.2, Q4.2 (S), R6.2, R26.1, U1.61 (I2C1_SCL/I2C3_SDA/I2S5_SD/SDIO_D4/SPI5_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), U4.2 (SCL/SPC), U8.1 (SCL), U9.13 (SCL), U12.2 (SCL/SPC)
/IMU_I2C_DA: P7.6, P8.6, P12.1, Q5.2 (S), R7.2, R27.1, U1.62 (I2C1_SDA/I2C2_SDA/I2S2_WS/SDIO_D5/SPI2_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), U4.4 (SDA/SDI/SDO), U8.4 (SDA), U9.14 (SDA), U12.4 (SDA/SDI/SDO)
/INT/DRDY_Mag: U8.7 (INT_MAG/DRDY)
/LPS_I_DRDY: U1.29 (I2C2_SCL/I2S2_CK/I2S3_MCK/SDIO_D7/SPI2_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), U12.7 (INT_DRDY)
/LPS_SA0: U1.34 (I2S2_CK/I2S4_CK/SPI2_SCK/SPI4_SCK/TIM1_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), U12.5 (SDO/SA0)
/LSM6DSL_INT1: U1.56 (I2C3_SDA/I2S3_ext_SD/SDIO_D0/SPI1_MISO/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), U9.4 (INT1)
/LSM6DSL_INT2: U1.57 (I2C1_SMBA/I2S1_SD/I2S3_SD/SDIO_D3/SPI1_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), U9.9 (INT2)
/Load_cell_amp_1: P19.1, U1.24 (PC4/ADC1_IN14), U13.6
/Load_cell_amp_2: P20.1, U1.25 (PC5/ADC1_IN15), U5.6
/NRST: C31.1, P9.5, R21.1, U1.7 (NRST), U11.1
/SWCLK: P9.2, U1.49 (SYS_JTCK-SWCLK/PA14)
/SWDIO: P9.4, U1.46 (SYS_JTMS-SWDIO/PA13)
/TOF_SD: P7.4, P8.4, U1.40 (PC9/I2C3_SDA/I2S_CKIN/RCC_MCO_2/SDIO_D1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)
/USB3V3: C10.1, JP2.3, U2.17 (3V3OUT)
/USB5V: C6.1, C7.1, C8.1, JP1.3, L1.2, U2.20 (VCC)
/USB_USART_RX: P10.2, U1.17 (ADC1_IN3/I2S2_MCK/TIM2_CH4/TIM5_CH4/TIM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), U2.1 (TXD)
/USB_USART_TX: P10.1, U1.16 (ADC1_IN2/I2S_CKIN/TIM2_CH3/TIM5_CH3/TIM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), U2.5 (RXD)
/U_BUT: C30.1, R20.1, U1.2 (PC13/ANTI_TAMP/RTC_AF1), U10.1
/VBat: P26.1, R24.2, R25.2
/VL_C10: P7.3, P8.3, U1.51 (PC10/I2S3_CK/SDIO_D2/SPI3_SCK)
GND: C1.1, C2.2, C3.2, C4.2, C5.2, C6.2, C7.2, C8.2, C9.2, C10.2, C11.1, C12.1, C13.2, C14.1, C15.1, C16.2, C17.2, C19.2, C20.2, C22.2, C23.2, C24.2, C25.2, C26.2, C27.2, C28.2, C29.2, C30.2, C31.2, C32.2, C34.2, C35.1, D1.2 (A), D2.2 (A), P1.1, P2.4 (GND), P2.5 (shield), P7.2, P8.2, P9.3, P15.2, P26.4, Q1.1 (G), R1.2, R4.1, R11.1, R17.1, R18.1, R22.1, R23.1, U1.12 (VSSA), U1.18 (VSS), U1.31 (VSS), U1.47 (VSS), U1.63 (VSS), U2.7 (GND), U2.18 (GND), U2.21 (GND), U2.25 (AGND), U2.26 (TEST), U3.1 (GND), U4.5 (GND), U6.6 (GND), U7.6 (GND), U7.9 (GND), U7.17 (ExtInt), U7.20 (GND_PAD8), U7.21 (GND_PAD7), U7.22 (GND_PAD6), U7.23 (GND_PAD1), U7.24 (GND_PAD2), U7.25 (GND_PAD3), U7.26 (GND_PAD4), U7.27 (GND_PAD5), U8.6 (GND), U8.8 (GND), U9.6 (GND), U9.7 (GND), U12.3 (RES), U12.8 (GND), U12.9 (GND)
GNDA: C18.2, C21.2, P3.1, P4.1, P5.1, P6.1, P21.2, R23.2, U5.4 (V-), U5.5 (Ref), U13.4 (V-), U13.5 (Ref)
unnamed: C2.1, U1.5 (PH0/RCC_OSC_IN), Y1.1
unnamed: C3.1, U1.6 (PH1/RCC_OSC_OUT), Y1.2
unnamed: C5.1, U1.30 (VCAP1)
unnamed: C26.1, U8.5 (C1)
unnamed: D1.1 (K), R2.2, R3.2
unnamed: D2.1 (K), R5.2
unnamed: JP1.1, Q3.2 (C)
unnamed: JP2.1, U3.2 (VO), U3.4 (VO)
unnamed: L1.1, P2.1 (VBUS)
unnamed: P1.2, Q1.3 (D)
unnamed: P2.2 (D-), U2.16 (USBDM)
unnamed: P2.3 (D+), U2.15 (USBDP)
unnamed: P3.2, P4.2, U5.2 (-)
unnamed: P3.3, P4.3, U5.3 (+)
unnamed: P5.2, P6.2, U13.2 (-)
unnamed: P5.3, P6.3, U13.3 (+)
unnamed: P26.2, Q5.3 (D), R25.1
unnamed: P26.3, Q4.3 (D), R24.1
unnamed: Q1.2 (S), Q2.3 (E), Q3.3 (E), R2.1
unnamed: Q2.1 (B), R3.1
unnamed: Q2.2 (C), Q3.1 (B), R4.2
unnamed: R1.1, U1.60 (BOOT0)
unnamed: R9.2, U7.7 (GPIO6/SPI_CLK)
unnamed: R12.1, U5.1 (Rg)
unnamed: R12.2, RV1.1, RV1.2
unnamed: R15.1, U13.8 (Rg)
unnamed: R15.2, RV2.2, RV2.3
unnamed: R16.2, U7.14 (I2C_CLK)
unnamed: R17.2, U10.2
unnamed: R18.2, U11.2
unnamed: R19.2, U7.15 (I2C_DIO)
unnamed: RV1.3, U5.8 (Rg)
unnamed: RV2.1, U13.1 (Rg)

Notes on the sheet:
NOTE: RX to TX, TX to RX
Mounting Holes
USB USART Connection for Programming Using FT232RL
Measurement Nodes MCU
Main chip, STM32F411RET, and lables only. Sensor architectures in their own boxes, well documented.
Required circuitry
Autowakeup: 4 to 16
7op for I2C , 7cl for UART;
8op for UART, 8cl for I2C;
For I2C use
GPS: A2235-H schematic Datasheet: http://www.mouser.com/catalog/specsheets/EVA2235-H.pdf
Pullups
Amplifier for load cell, connects to JST-TH and Analog
LSM303AGR VDD Decoup. Cap.
LSM6DSL VDD Decoup. Cap.
I2C circuitry
Bluetooth connection module
Power input from battery dock board
Measurement Nodes USB
Measurement Nodes GPS
Toggle signal GPS
1: Magneto & Acc. 2: Gyro & Acc. 3: Humidity 4. Pressure
I2C 2
Reset SPI_CLK SPI_MISO SPI_MOSI SPI_CS SPI_IRQ
Measurement Nodes BT-LE
Measurement Nodes Digital Power Pins
Measurement Nodes Analog Power Pins
Measurement Nodes Load Cell 1
Meta circuitry (Measurement nodes & Mounting)
Modules
Power Flags
GP Button.
Micro_USB-B
IMU_1
IMU_2
Measurement Nodes Load Cell 2
Power save if not used
Acc. & Gyro.
Acc. & Mag.
I2C 4

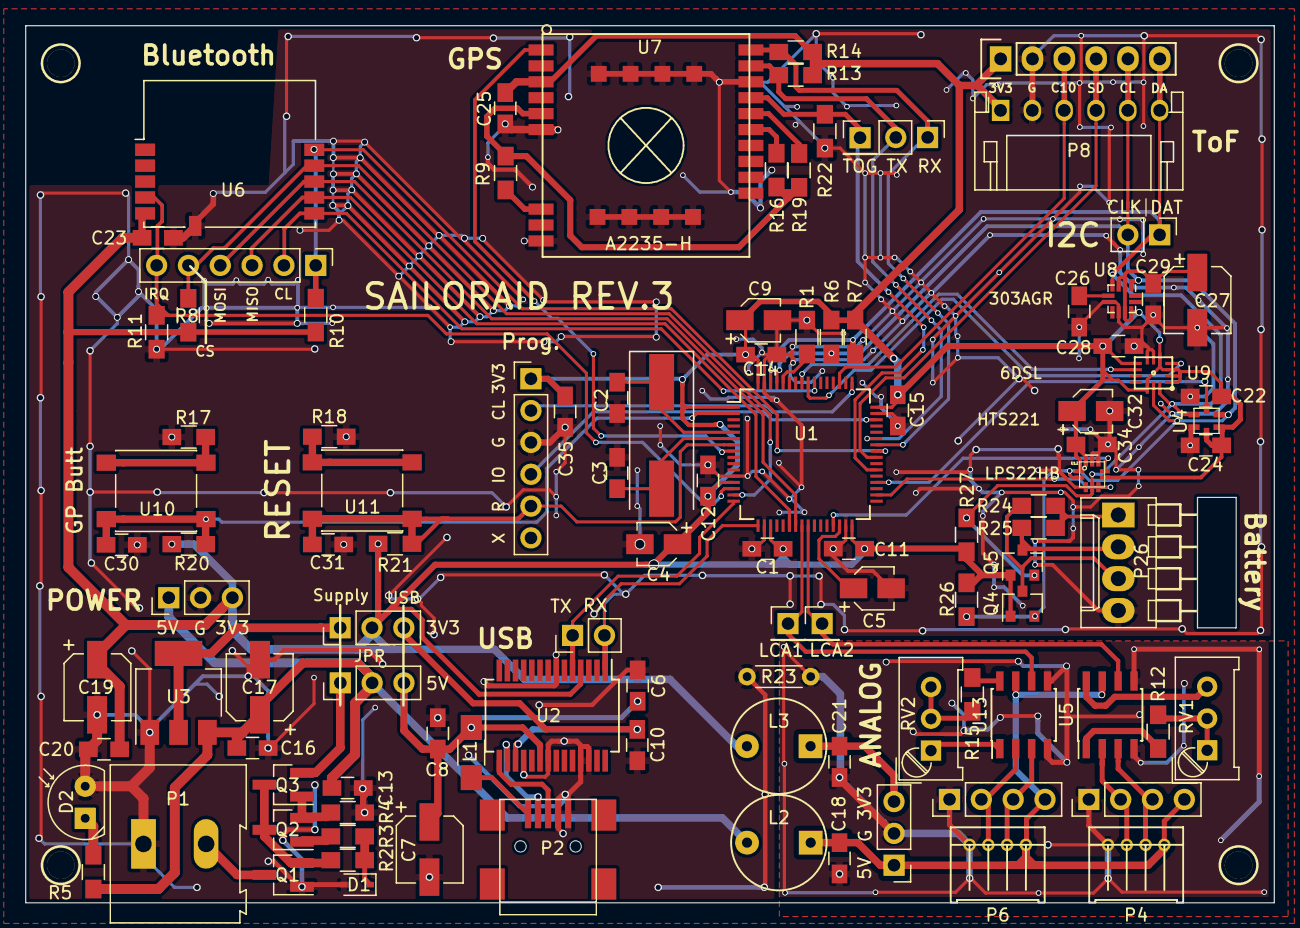
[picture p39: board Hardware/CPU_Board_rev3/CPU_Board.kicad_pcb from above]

Board: 2 copper layers, 99.7 x 70.0 mm, 112 parts (0 on the bottom side), 70 nets.

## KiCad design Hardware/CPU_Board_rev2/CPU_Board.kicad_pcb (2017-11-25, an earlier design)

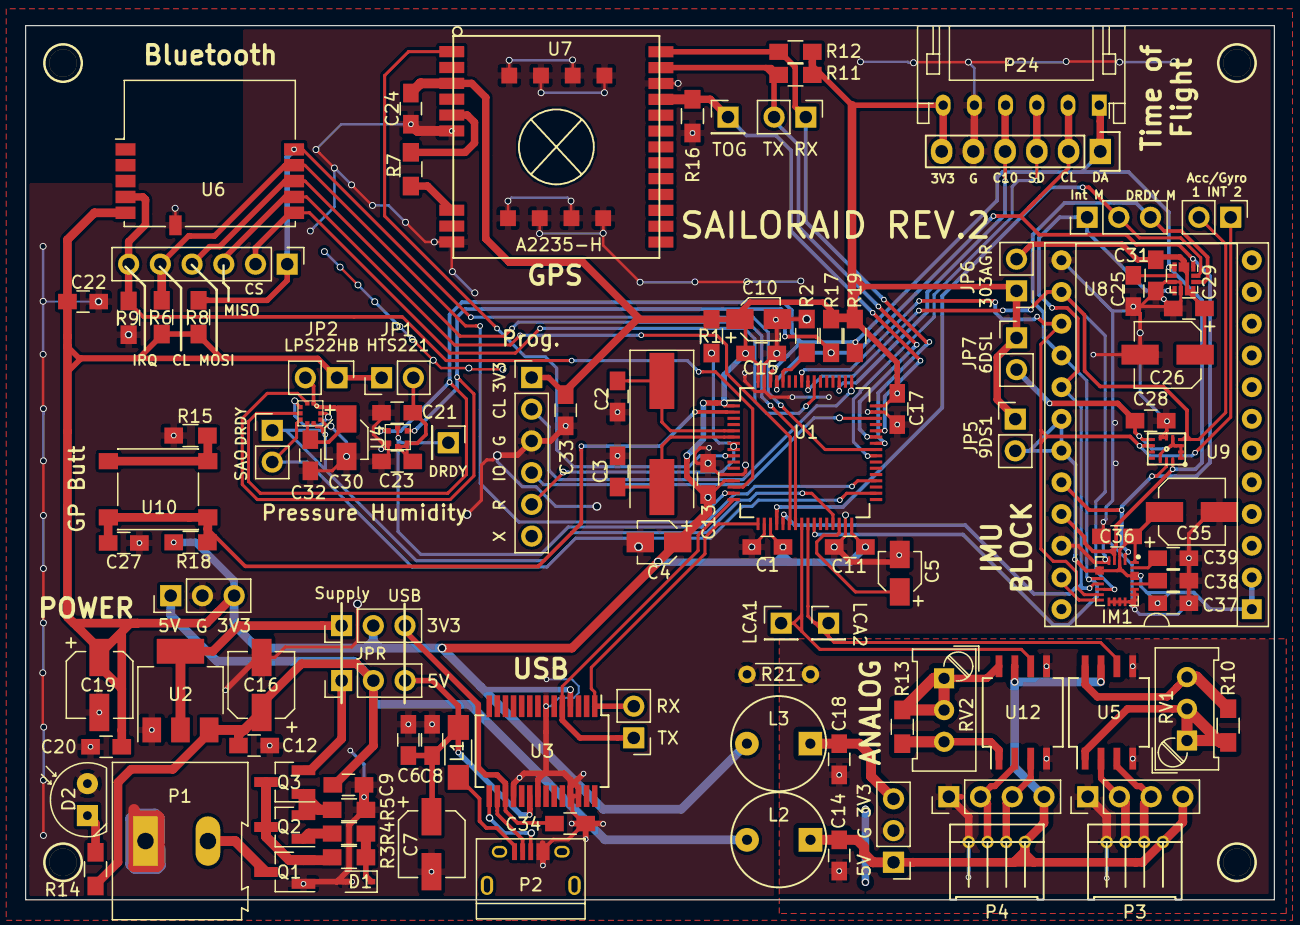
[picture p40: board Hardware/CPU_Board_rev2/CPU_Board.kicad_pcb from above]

Board: 2 copper layers, 100.0 x 70.0 mm, 116 parts (0 on the bottom side), 74 nets.

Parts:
C1: 1u; C_0805_HandSoldering
C2, C3: 18p; C_0805_HandSoldering
C4, C5, C10, C30: 4.7u; CP_Elec_3x5.3
C6, C8, C9, C11, C12, C13, C14, C15, C17, C18, C20, C23, C24, C27, C32, C33, C34, C36, C37, C39: 100n; C_0805_HandSoldering
C7, C16, C19: 10u; CP_Elec_5x5.3
C21: 2.2u; C_0805_HandSoldering
C22: 1uF; C_0805_HandSoldering
C25: 220nF; C_0805_HandSoldering
C26, C35: 10uF; CP_Elec_5x5.3
C28, C29, C31: 100nF; C_0805_HandSoldering
C38: 10n; C_0805_HandSoldering
D1: D_Zener; D_SOD-323
D2: D_Photo; PhotoDiode_SFH205
IM1: LSM9DS1; LGA-24L_3x3.5mm_Pitch0.43mm_Handsolder
JP1, JP2, JP5, JP6, JP7: Jumper_NC_Small; Pin_Header_Straight_1x02_Pitch2.54mm
JP3, JP4: Jumper_NC_Dual; Pin_Header_Straight_1x03_Pitch2.54mm
L1: L_Core_Ferrite_500mA; R_1206_HandSoldering
L2, L3: 330uH; INDUCTOR_V
P1: CONN_01X02; AK300-2
P2: USB_B; USB_Micro-B
P3, P4: CONN_01X04; Connector_JST_S4B-ZR_1x4
P5, P11: CONN_01X06; Pin_Header_Straight_1x06_Pitch2.54mm
P6: CONN_02X12; DIP-24_W15.24mm_Socket
P7, P8, P9, P10: CONN_01X02; Pin_Header_Straight_1x02_Pitch2.54mm
P12, P14, P18: CONN_01X03; Pin_Header_Straight_1x03_Pitch2.54mm
P13, P15, P16, P17: CONN_01X01; Pin_Header_Straight_1x01_Pitch2.54mm
P19, P20, P22, P23: CONN_01X01; MountingHole_2.2mm_M2_DIN965_NoPad
P21: CONN_01X06; Socket_Strip_Straight_1x06
P24: CONN_01X06; JST_PH_S6B-PH-K_06x2.50mm_Angled
P25, P26: CONN_01X04; Pin_Header_Straight_1x04_Pitch2.54mm
Q1: Q_PMOS_GSD; SOT-23_Handsoldering
Q2, Q3: Q_PNP_BCE; SOT-23_Handsoldering
R1, R2, R7, R11, R12, R16, R17, R18, R19: 10k; R_0805_HandSoldering
R3: 2.7k; R_0805_HandSoldering
R4, R5: 6.8k; R_0805_HandSoldering
R6, R8: 10K; R_0805_HandSoldering
R9: 47K; R_0805_HandSoldering
R10, R13: 5k; R_0805_HandSoldering
R14: 220; R_0805_HandSoldering
R15: 1k; R_0805_HandSoldering
R21: 0R; R_Axial_DIN0204_L3.6mm_D1.6mm_P5.08mm_Horizontal
RV1, RV2: 360; Potentiometer_Trimmer_Bourns_PV36W
U1: STM32F411RETx; LQFP-64_10x10mm_Pitch0.5mm
U2: NCP1117DT12G; SOT-223
U3: FT232RL; SSOP-28_5.3x10.2mm_Pitch0.65mm
U4: HTS221; HLGA-6L_2x2x.9mm
U5, U12: INA128; SO-8_5.3x6.2mm_Pitch1.27mm
U6: SPBTLE-RF; ST_SPBTLE
U7: A2235-H; A2235-H_Handsolder
U8: LSM303AGR; LGA-12_2x2mm_Pitch0.5mm_Handsolder
U9: LSM6DSL; LGA-14
U10: MCDTS2-4N; SW_SPST_PTS645
U11: LPS22HB; HLGA-10L
Y1: 8MHz; Crystal_SMD_HC49-SD

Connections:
+3.3VADC: C18.1, L3.1, P18.3
+3V3: C1.2, C4.1, C10.1, C11.2, C13.2, C15.2, C17.2, C19.1, C20.1, C22.1, C24.1, C33.2, JP1.1, JP2.1, JP4.2, JP5.1, JP6.1, JP7.1, L3.2, P5.1, P12.3, P21.6, P24.6, R1.2, R6.2, R8.2, R11.1, R12.1, R17.1, R18.2, R19.1, U1.1, U1.13, U1.19, U1.32, U1.48, U1.64, U3.4, U6.5, U7.3
+5V: C9.1, C12.1, C16.1, JP3.2, L2.2, P12.1, R14.1, U2.3
+5VA: C14.1, L2.1, P3.4, P4.4, P18.1, P25.4, P26.4, U5.7, U12.7
/303C_I_XL: P14.2, U1.20, U8.12
/BT_CLK: P11.2, U1.55, U6.7
/BT_CS: P11.5, R6.1, U1.15, U6.10
/BT_IRQ: P11.6, R9.2, U1.14, U6.4
/BT_MISO: P11.3, U1.22, U6.8
/BT_MOSI: P11.4, U1.23, U6.9
/BT_RST: P11.1, R8.1, U1.41, U6.11
/DRDY_Mag: IM1.9, P6.16, P14.3, U1.26, U8.11
/GPS_NRST: U1.9, U7.1
/GPS_RX: P8.1, R12.2, U1.42, U7.22
/GPS_TOGGLE: P13.1, R16.2, U1.44, U7.19
/GPS_TX: P8.2, R11.2, U1.43, U7.21
/HTS_DRDY: P15.1, U1.36, U4.3
/HTS_VDD: C21.1, C23.1, JP1.2, U4.1, U4.6
/IMU_I2C_CL: IM1.2, P6.20, P21.2, P24.2, R17.2, U1.61, U4.2, U8.1, U9.13, U11.2
/IMU_I2C_DA: IM1.4, P6.21, P21.1, P24.1, R19.2, U1.62, U4.4, U8.4, U9.14, U11.4
/INT_Mag: IM1.10, P6.17, P14.1, U1.21, U8.7
/LPS_DRDY: P10.1, U1.29, U11.7
/LPS_SA0: P10.2, U1.34, U11.5
/LPS_VDD: C30.1, C32.1, JP2.2, U11.1, U11.6, U11.10
/LSM6DSL_INT1: IM1.11, P6.14, P9.2, U1.56, U9.4
/LSM6DSL_INT2: IM1.12, P6.15, P9.1, U1.57, U9.9
/LSM6_VDD: C28.1, JP7.2, U9.1, U9.2, U9.3, U9.5, U9.8, U9.12
/LSM9_CS_A/G: C35.1, C36.1, C37.1, IM1.1, IM1.3, IM1.7, IM1.8, IM1.22, IM1.23, JP5.2, P6.1, P6.2, P6.18, P6.19
/LSM9_DEN_A/G: IM1.13, P6.23
/LSM303_VDD: C26.1, C29.1, C31.1, JP6.2, U8.2, U8.3, U8.9, U8.10
/Load_cell_amp_1: P16.1, U1.24, U12.6
/Load_cell_amp_2: P17.1, U1.25, U5.6
/NRST: P5.5, R1.1, U1.7, U1.8
/SWCLK: P5.2, U1.49
/SWDIO: P5.4, U1.46
/USB3V3: C34.1, JP4.3, U3.17
/USB5V: C6.1, C7.1, C8.1, JP3.3, L1.2, U3.20
/USB_USART_RX: P7.2, U1.17, U3.1
/USB_USART_TX: P7.1, U1.16, U3.5
/U_BUT: C27.1, R18.1, U1.2, U10.1
/VL_C9: P21.3, P24.3, U1.40
/VL_C10: P21.4, P24.4, U1.51
GND: C1.1, C2.2, C3.2, C4.2, C5.2, C6.2, C7.2, C8.2, C9.2, C10.2, C11.1, C12.2, C13.1, C15.1, C16.2, C17.1, C19.2, C20.2, C21.2, C22.2, C23.2, C24.2, C25.2, C26.2, C27.2, C28.2, C29.2, C30.2, C31.2, C32.2, C33.1, C34.2, C35.2, C36.2, C37.2, C38.2, C39.2, D1.2, D2.2, IM1.5, IM1.6, IM1.14, IM1.15, IM1.16, IM1.17, IM1.18, IM1.19, IM1.20, P1.1, P2.4, P2.5, P5.3, P6.13, P6.22, P12.2, P21.5, P24.5, Q1.1, R2.2, R5.1, R9.1, R15.1, R16.1, R21.1, U1.12, U1.18, U1.31, U1.47, U1.63, U2.1, U3.7, U3.18, U3.21, U3.25, U3.26, U4.5, U6.6, U7.6, U7.9, U7.20, U7.23, U7.24, U7.25, U7.26, U7.27, U7.28, U7.29, U7.30, U8.6, U8.8, U9.6, U9.7, U11.8
GNDA: C14.2, C18.2, P3.1, P4.1, P18.2, P25.1, P26.1, R21.2, U5.4, U5.5, U12.4, U12.5
unnamed: C2.1, U1.5, Y1.1
unnamed: C3.1, U1.6, Y1.2
unnamed: C5.1, U1.30
unnamed: C25.1, U8.5
unnamed: C38.1, IM1.21
unnamed: C39.1, IM1.24
unnamed: D1.1, R3.2, R4.2
unnamed: D2.1, R14.2
unnamed: JP3.1, Q3.2
unnamed: JP4.1, U2.2, U2.4
unnamed: L1.1, P2.1
unnamed: P1.2, Q1.3
unnamed: P2.2, U3.16
unnamed: P2.3, U3.15
unnamed: P3.2, P25.2, U5.2
unnamed: P3.3, P25.3, U5.3
unnamed: P4.2, P26.2, U12.2
unnamed: P4.3, P26.3, U12.3
unnamed: Q1.2, Q2.3, Q3.3, R3.1
unnamed: Q2.1, R4.1
unnamed: Q2.2, Q3.1, R5.2
unnamed: R2.1, U1.60
unnamed: R7.1, U7.5
unnamed: R7.2, U7.7
unnamed: R10.1, RV1.1, RV1.2, U5.1
unnamed: R10.2, RV1.3, U5.8
unnamed: R13.1, RV2.3, U12.1
unnamed: R13.2, RV2.1, RV2.2, U12.8
unnamed: R15.2, U10.2
unnamed: U11.3, U11.9

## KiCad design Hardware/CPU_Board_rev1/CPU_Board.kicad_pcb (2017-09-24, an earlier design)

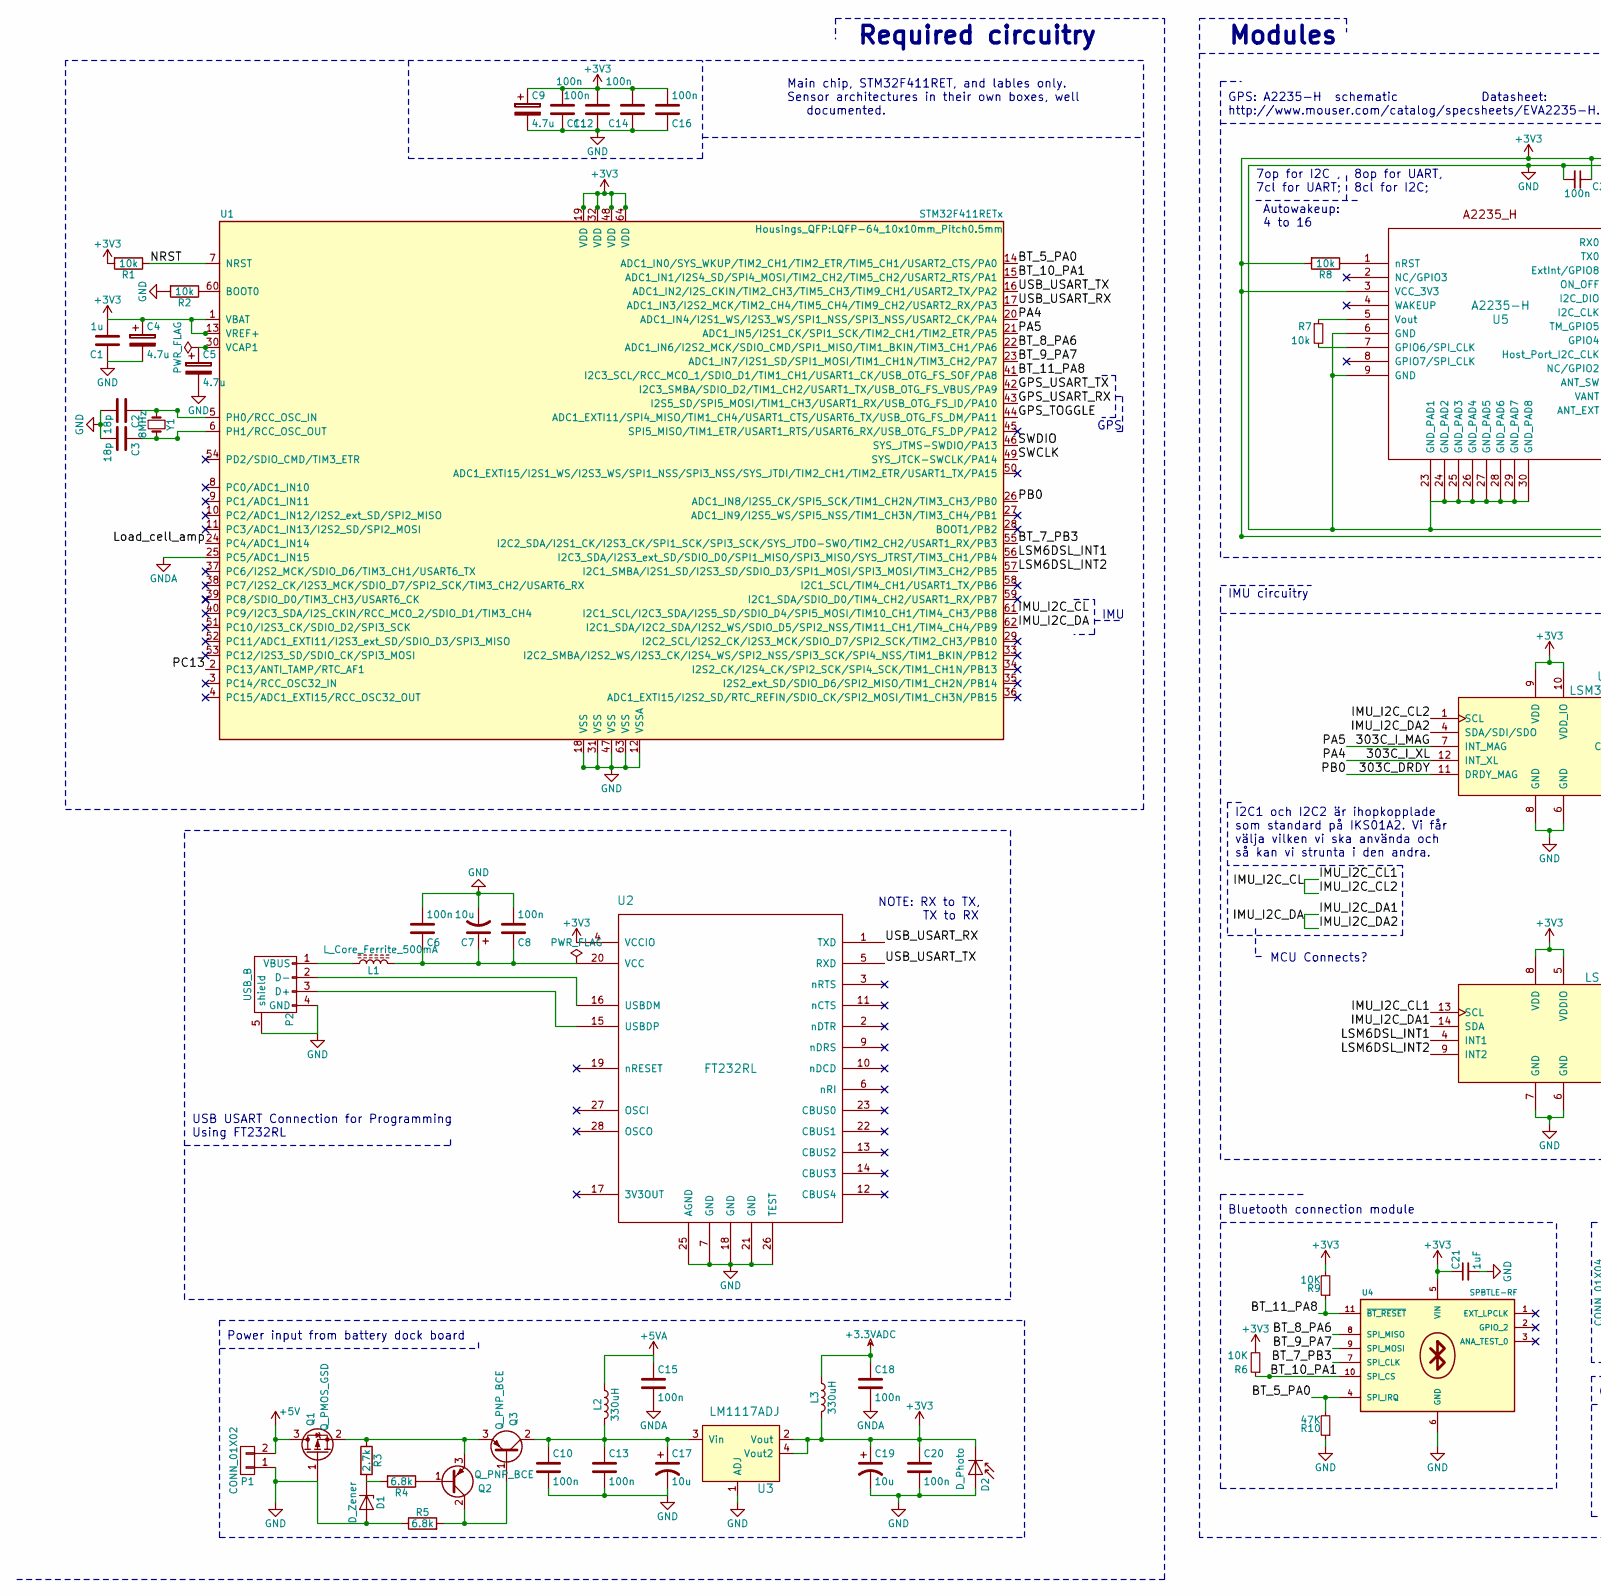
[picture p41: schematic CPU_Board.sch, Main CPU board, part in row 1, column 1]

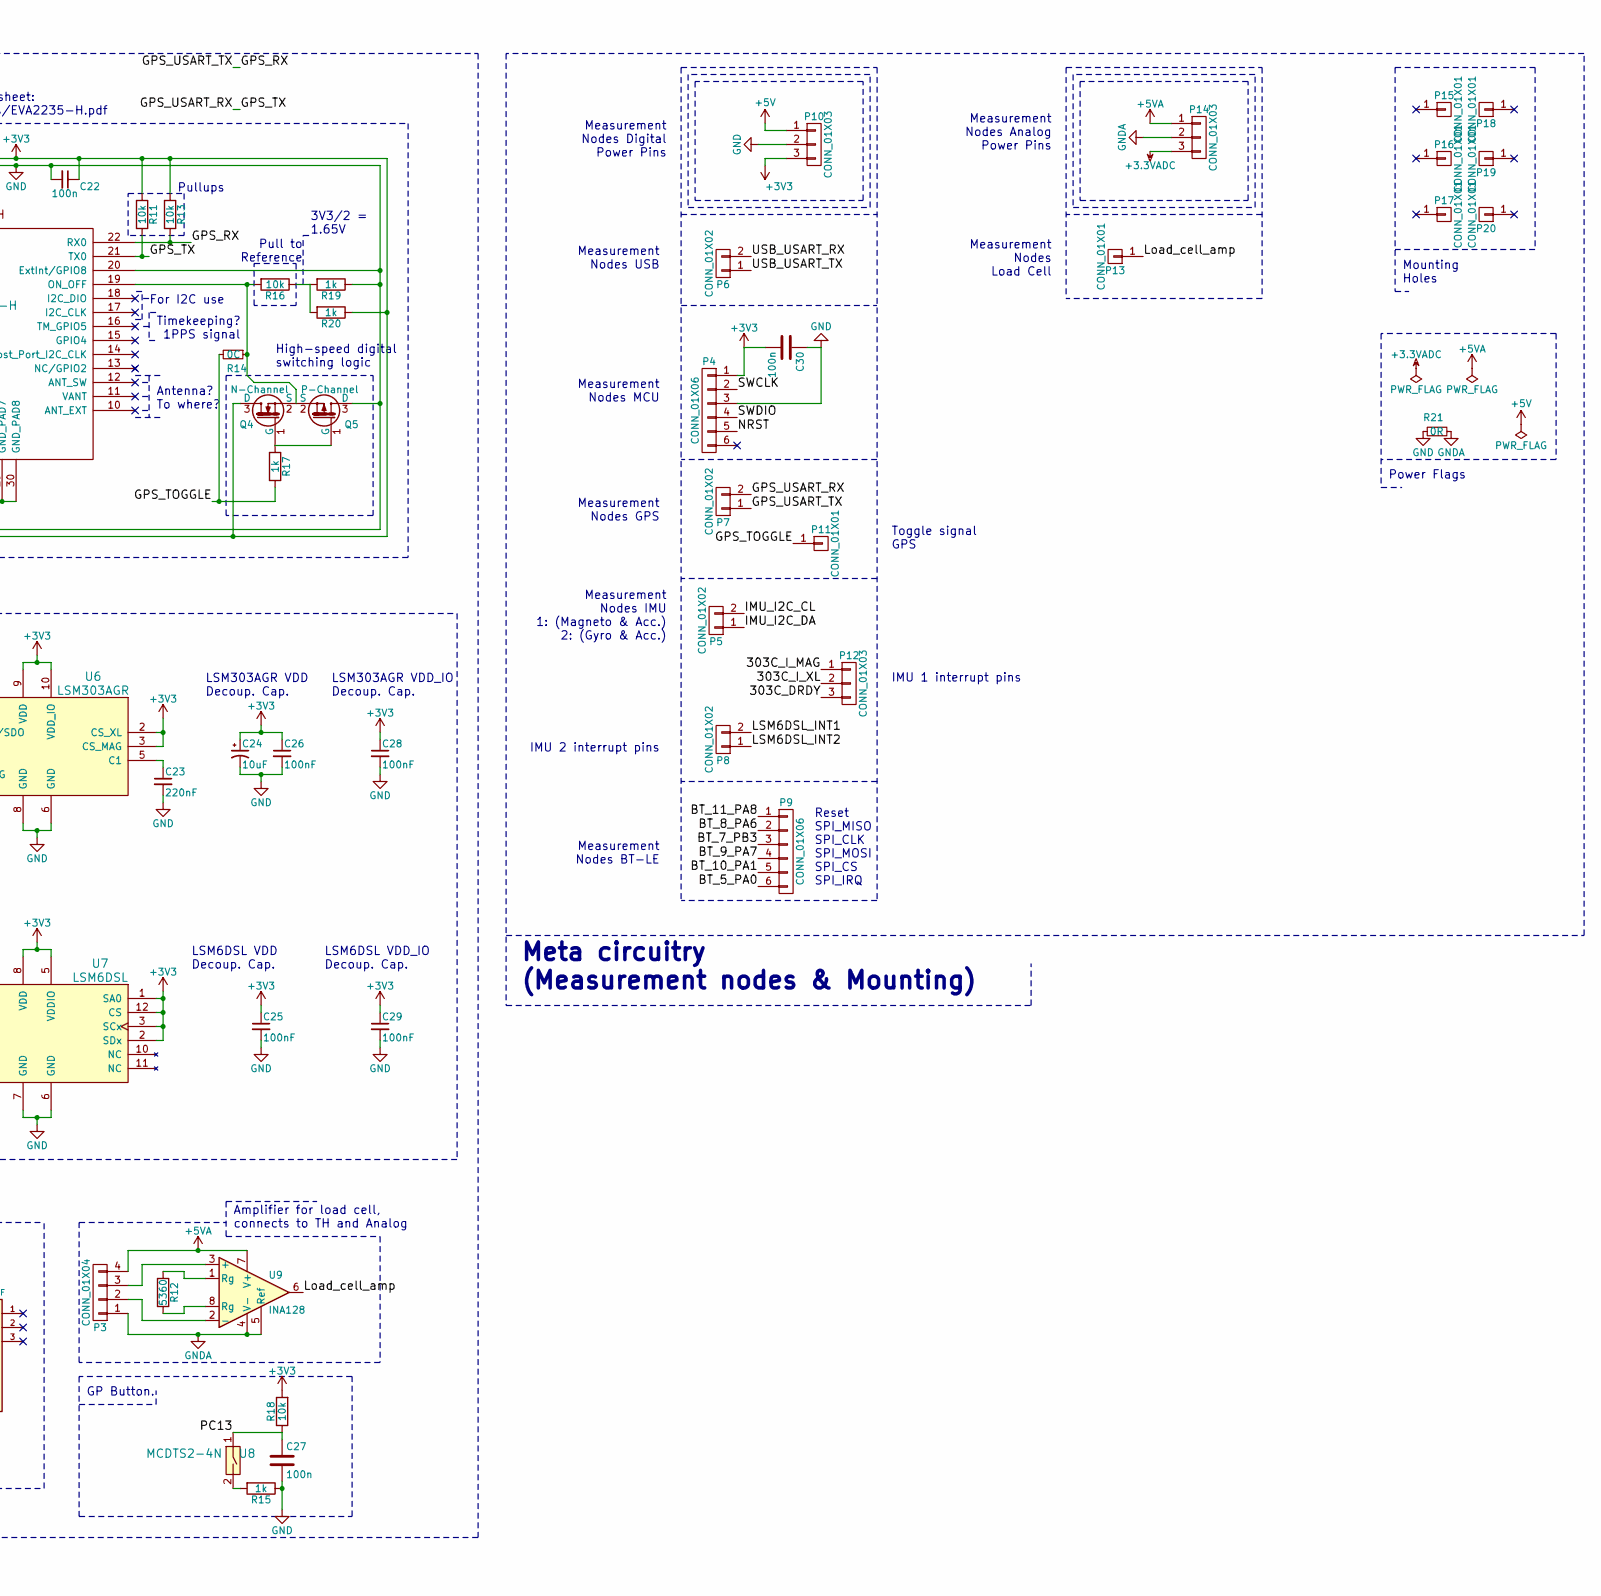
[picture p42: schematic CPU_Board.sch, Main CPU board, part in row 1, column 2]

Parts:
C1: 1u; C_0805_HandSoldering
C2, C3: 18p; C_0805_HandSoldering
C4, C5, C9: 4.7u; CP_Elec_4x5.3
C6, C8, C10, C11, C12, C13, C14, C15, C16, C18, C20, C22, C27, C30: 100n; C_0805_HandSoldering
C7, C17, C19: 10u; CP_Elec_5x5.3
C21: 1uF; C_0805_HandSoldering
C23: 220nF; C_0805_HandSoldering
C24: 10uF; CP_Elec_5x5.3
C25, C26, C28, C29: 100nF; C_0805_HandSoldering
D1: D_Zener; D_SOD-323
D2: D_Photo; PhotoDiode_SFH205
L1: L_Core_Ferrite_500mA; R_1206_HandSoldering
L2, L3: 330uH; INDUCTOR_V
P1: CONN_01X02; AK300-2
P2: USB_B
P3: CONN_01X04; Pin_Header_Straight_1x04_Pitch2.54mm
P4, P9: CONN_01X06; Pin_Header_Straight_1x06_Pitch2.54mm
P5, P6, P7, P8: CONN_01X02; Pin_Header_Straight_1x02_Pitch2.54mm
P10, P12, P14: CONN_01X03; Pin_Header_Straight_1x03_Pitch2.54mm
P11, P13: CONN_01X01; Pin_Header_Straight_1x01_Pitch2.54mm
P15, P16, P17, P18, P19, P20: CONN_01X01; MountingHole_2.2mm_M2_DIN965_Pad
Q1: Q_PMOS_GSD; SOT-23_Handsoldering
Q2, Q3: Q_PNP_BCE; SOT-23_Handsoldering
Q4: N-Channel; SOT-23_Handsoldering
Q5: P-Channel; SOT-23_Handsoldering
R1, R2, R7, R8, R11, R13, R16, R18: 10k; R_0805_HandSoldering
R3: 2.7k; R_0805_HandSoldering
R4, R5: 6.8k; R_0805_HandSoldering
R6, R9: 10K; R_0805_HandSoldering
R10: 47K; R_0805_HandSoldering
R12: 5360; R_0805_HandSoldering
R14: 0C; R_Axial_DIN0204_L3.6mm_D1.6mm_P1.90mm_Vertical
R15, R17, R19, R20: 1k; R_0805_HandSoldering
R21: 0R; R_Axial_DIN0204_L3.6mm_D1.6mm_P5.08mm_Horizontal
U1: STM32F411RETx; LQFP-64_10x10mm_Pitch0.5mm
U2: FT232RL; SSOP-28_5.3x10.2mm_Pitch0.65mm
U3: LM1117ADJ; SOT-223
U4: SPBTLE-RF; ST_SPBTLE
U5: A2235-H; A2235-H_Handsolder
U6: LSM303AGR; LGA-12_2x2mm_Pitch0.5mm
U7: LSM6DSL; LGA-14
U8: MCDTS2-4N; SW_SPST_PTS645
U9: INA128; SO-8_5.3x6.2mm_Pitch1.27mm
Y1: 8MHz; Crystal_SMD_HC49-SD

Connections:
+3.3VADC: C18.1, L3.1, P14.3
+3V3: C1.2, C4.1, C9.1, C11.2, C12.2, C14.2, C16.2, C19.1, C20.1, C21.1, C22.1, C24.1, C25.1, C26.1, C28.1, C29.1, C30.2, D2.1 (K), L3.2, P4.1, P10.3, Q4.3 (D), R1.2, R6.2, R8.2, R9.2, R11.1, R13.1, R18.2, R20.1, U1.1 (VBAT), U1.13 (VREF+), U1.19 (VDD), U1.32 (VDD), U1.48 (VDD), U1.64 (VDD), U2.4 (VCCIO), U3.2 (Vout), U3.4 (Vout2), U4.5 (VIN), U5.3 (VCC_3V3), U6.2 (CS_XL), U6.3 (CS_MAG), U6.9 (VDD), U6.10 (VDD_IO), U7.1 (SA0), U7.2 (SDx), U7.3 (SCx), U7.5 (VDDIO), U7.8 (VDD), U7.12 (CS)
+5V: P1.2, P10.1, Q1.3 (D)
+5VA: C15.1, L2.1, P3.4, P14.1, U9.7 (V+)
/303C_DRDY: P12.3, U1.26 (ADC1_IN8/I2S5_CK/SPI5_SCK/TIM1_CH2N/TIM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), U6.11 (DRDY_MAG)
/303C_I_MAG: P12.1, U1.21 (ADC1_IN5/I2S1_CK/SPI1_SCK/TIM2_CH1/TIM2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), U6.7 (INT_MAG)
/303C_I_XL: P12.2, U1.20 (ADC1_IN4/I2S1_WS/I2S3_WS/SPI1_NSS/SPI3_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), U6.12 (INT_XL)
/BT_5_PA0: P9.6, R10.2, U1.14 (ADC1_IN0/SYS_WKUP/TIM2_CH1/TIM2_ETR/TIM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), U4.4 (SPI_IRQ)
/BT_7_PB3: P9.3, U1.55 (I2C2_SDA/I2S1_CK/I2S3_CK/SPI1_SCK/SPI3_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), U4.7 (SPI_CLK)
/BT_8_PA6: P9.2, U1.22 (ADC1_IN6/I2S2_MCK/SDIO_CMD/SPI1_MISO/TI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), U4.8 (SPI_MISO)
/BT_9_PA7: P9.4, U1.23 (ADC1_IN7/I2S1_SD/SPI1_MOSI/TIM1_CH1N/TI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), U4.9 (SPI_MOSI)
/BT_10_PA1: P9.5, R6.1, U1.15 (ADC1_IN1/I2S4_SD/SPI4_MOSI/TIM2_CH2/TIM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), U4.10 (SPI_CS)
/BT_11_PA8: P9.1, R9.1, U1.41 (I2C3_SCL/RCC_MCO_1/SDIO_D1/TIM1_CH1/USA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), U4.11 (~BT_RESET~)
/GPS_RX: P7.1, R13.2, U1.42 (I2C3_SMBA/SDIO_D2/TIM1_CH2/USART1_TX/US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), U5.22 (RX0)
/GPS_TOGGLE: P11.1, R14.2, R17.2, U1.44 (ADC1_EXTI11/SPI4_MISO/TIM1_CH4/USART1_C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)
/GPS_TX: P7.2, R11.2, U1.43 (I2S5_SD/SPI5_MOSI/TIM1_CH3/USART1_RX/US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), U5.21 (TX0)
/IMU_I2C_CL: P5.2, U1.61 (I2C1_SCL/I2C3_SDA/I2S5_SD/SDIO_D4/SPI5_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), U6.1 (SCL), U7.13 (SCL)
/IMU_I2C_DA: P5.1, U1.62 (I2C1_SDA/I2C2_SDA/I2S2_WS/SDIO_D5/SPI2_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), U6.4 (SDA/SDI/SDO), U7.14 (SDA)
/LSM6DSL_INT1: P8.2, U1.56 (I2C3_SDA/I2S3_ext_SD/SDIO_D0/SPI1_MISO/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), U7.4 (INT1)
/LSM6DSL_INT2: P8.1, U1.57 (I2C1_SMBA/I2S1_SD/I2S3_SD/SDIO_D3/SPI1_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), U7.9 (INT2)
/Load_cell_amp: P13.1, U1.24 (PC4/ADC1_IN14), U9.6
/NRST: P4.5, R1.1, U1.7 (NRST)
/PC13: C27.1, R18.1, U1.2 (PC13/ANTI_TAMP/RTC_AF1), U8.1
/SWCLK: P4.2, U1.49 (SYS_JTCK-SWCLK/PA14)
/SWDIO: P4.4, U1.46 (SYS_JTMS-SWDIO/PA13)
/USB_USART_RX: P6.2, U1.17 (ADC1_IN3/I2S2_MCK/TIM2_CH4/TIM5_CH4/TIM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), U2.1 (TXD)
/USB_USART_TX: P6.1, U1.16 (ADC1_IN2/I2S_CKIN/TIM2_CH3/TIM5_CH3/TIM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), U2.5 (RXD)
GND: C1.1, C2.2, C3.2, C4.2, C5.2, C6.2, C7.2, C8.2, C9.2, C10.2, C11.1, C12.1, C13.2, C14.1, C16.1, C17.2, C19.2, C20.2, C21.2, C22.2, C23.2, C24.2, C25.2, C26.2, C27.2, C28.2, C29.2, C30.1, D1.2 (A), D2.2 (A), P1.1, P2.4 (GND), P2.5 (shield), P4.3, P10.2, Q1.1 (G), Q5.3 (D), R2.2, R5.1, R10.1, R15.1, R19.1, R21.1, U1.12 (VSSA), U1.18 (VSS), U1.31 (VSS), U1.47 (VSS), U1.63 (VSS), U2.7 (GND), U2.18 (GND), U2.21 (GND), U2.25 (AGND), U2.26 (TEST), U3.1 (ADJ), U4.6 (GND), U5.6 (GND), U5.9 (GND), U5.20 (ExtInt/GPIO8), U5.23 (GND_PAD1), U5.24 (GND_PAD2), U5.25 (GND_PAD3), U5.26 (GND_PAD4), U5.27 (GND_PAD5), U5.28 (GND_PAD6), U5.29 (GND_PAD7), U5.30 (GND_PAD8), U6.6 (GND), U6.8 (GND), U7.6 (GND), U7.7 (GND)
GNDA: C15.2, C18.2, P3.1, P14.2, R21.2, U1.25 (PC5/ADC1_IN15), U9.4 (V-), U9.5 (Ref)
unnamed: C2.1, U1.5 (PH0/RCC_OSC_IN), Y1.1
unnamed: C3.1, U1.6 (PH1/RCC_OSC_OUT), Y1.2
unnamed: C5.1, U1.30 (VCAP1)
unnamed: C6.1, C7.1, C8.1, L1.2, U2.20 (VCC)
unnamed: C10.1, C13.1, C17.1, L2.2, Q3.2 (C), U3.3 (Vin)
unnamed: C23.1, U6.5 (C1)
unnamed: D1.1 (K), R3.2, R4.2
unnamed: L1.1, P2.1 (VBUS)
unnamed: P2.2 (D-), U2.16 (USBDM)
unnamed: P2.3 (D+), U2.15 (USBDP)
unnamed: P3.2, U9.2 (-)
unnamed: P3.3, U9.3 (+)
unnamed: Q1.2 (S), Q2.3 (E), Q3.3 (E), R3.1
unnamed: Q2.1 (B), R4.1
unnamed: Q2.2 (C), Q3.1 (B), R5.2
unnamed: Q4.1 (G), Q5.1 (G), R17.1
unnamed: Q4.2 (S), Q5.2 (S), R14.1, R16.2, U5.19 (ON_OFF)
unnamed: R2.1, U1.60 (BOOT0)
unnamed: R7.1, U5.5 (Vout)
unnamed: R7.2, U5.7 (GPIO6/SPI_CLK)
unnamed: R8.1, U5.1 (nRST)
unnamed: R12.1, U9.1 (Rg)
unnamed: R12.2, U9.8 (Rg)
unnamed: R15.2, U8.2
unnamed: R16.1, R19.2, R20.2

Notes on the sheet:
NOTE: RX to TX, TX to RX
Mounting Holes
USB USART Connection for Programming Using FT232RL
Measurement Nodes MCU
Main chip, STM32F411RET, and lables only. Sensor architectures in their own boxes, well documented.
Required circuitry
Autowakeup: 4 to 16
Antenna? To where?
7op for I2C , 7cl for UART;
8op for UART, 8cl for I2C;
Timekeeping? 1PPS signal
For I2C use
GPS: A2235-H schematic Datasheet: http://www.mouser.com/catalog/specsheets/EVA2235-H.pdf
Pullups
GPS
Pull to Reference
High-speed digital switching logic
3V3/2 = 1.65V
Amplifier for load cell, connects to TH and Analog
LSM303AGR VDD Decoup. Cap.
LSM303AGR VDD_IO Decoup. Cap.
LSM6DSL VDD Decoup. Cap.
LSM6DSL VDD_IO Decoup. Cap.
I2C1 och I2C2 är ihopkopplade som standard på IKS01A2. Vi får välja vilken vi ska använda och så kan vi strunta i den andra.
IMU circuitry
MCU Connects?
IMU
Bluetooth connection module
Power input from battery dock board
Measurement Nodes USB
Measurement Nodes GPS
Toggle signal GPS
Measurement Nodes IMU 1: (Magneto & Acc.) 2: (Gyro & Acc.)
IMU 1 interrupt pins
IMU 2 interrupt pins
Reset SPI_MISO SPI_CLK SPI_MOSI SPI_CS SPI_IRQ
Measurement Nodes BT-LE
Measurement Nodes Digital Power Pins
Measurement Nodes Analog Power Pins
Measurement Nodes Load Cell

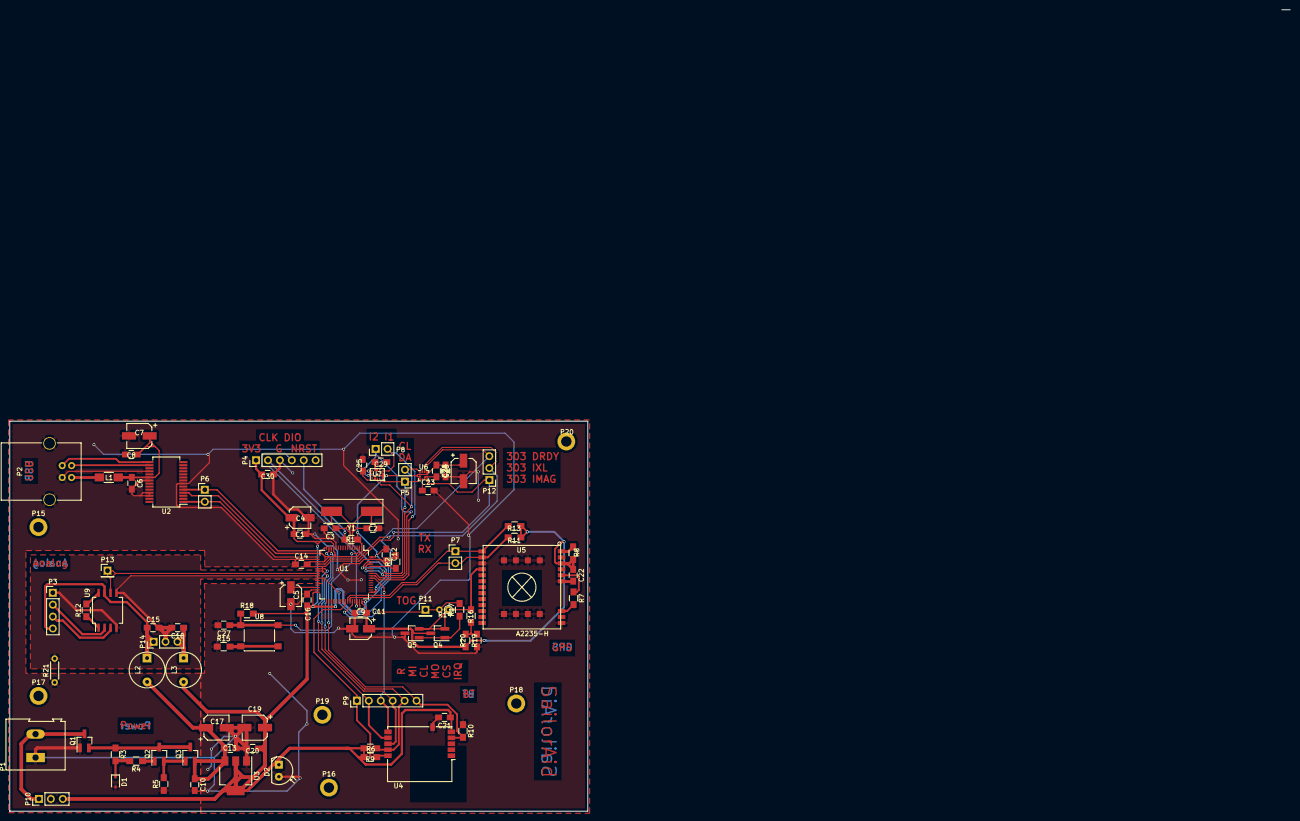
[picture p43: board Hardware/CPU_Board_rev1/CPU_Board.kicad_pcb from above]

Board: 2 copper layers, 123.1 x 83.1 mm, 91 parts (0 on the bottom side), 54 nets.

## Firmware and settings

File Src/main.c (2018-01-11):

/**
 ******************************************************************************
 * File Name          : main.c
 * Description        : Main program body
 ******************************************************************************
 ** This notice applies to any and all portions of this file
 * that are not between comment pairs USER CODE BEGIN and
 * USER CODE END. Other portions of this file, whether
 * inserted by the user or by software development tools
 * are owned by their respective copyright owners.
 *
 * COPYRIGHT(c) 2017 STMicroelectronics
 *
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
 ******************************************************************************
 */

/* Includes ------------------------------------------------------------------*/
#include "main.h"
#include "stm32f4xx_hal.h"

/* USER CODE BEGIN Includes */
#include "bluenrg_interface.h"
#include "stm32f4xx_nucleo.h"
#include "imu.h"
#include "gps.h"
#include "sensor.h"
#include "serial.h"
#include "MadgwickAHRS.h"
#include "state.h"
#include "range.h"
/* USER CODE END Includes */

ADC_HandleTypeDef hadc1;
DMA_HandleTypeDef hdma_adc1;

I2C_HandleTypeDef hi2c1;

SPI_HandleTypeDef hspi1;

TIM_HandleTypeDef htim2;

UART_HandleTypeDef huart1;
UART_HandleTypeDef huart2;
DMA_HandleTypeDef hdma_usart1_rx;
DMA_HandleTypeDef hdma_usart1_tx;
DMA_HandleTypeDef hdma_usart2_rx;
DMA_HandleTypeDef hdma_usart2_tx;

/* USER CODE BEGIN PV */

// System sample rates and USB/BT output rates
// Lowest rate possible is 1/(0xffffffff/10^6) = 0.0002 Hz
#define IMU_SAMPLE_RATE 100.0
#define ENV_SAMPLE_RATE 1.0
#define ADC_SAMPLE_RATE 10.0
#define RANGE_SAMPLE_RATE 10.0

#define USB_ENV_OUTPUT_RATE 1.0
#define USB_GPS_OUTPUT_RATE 1.0
#define USB_IMU_OUTPUT_RATE 60.0
#define USB_RANGE_OUTPUT_RATE 10.0
#define USB_MATLAB_OUTPUT_RATE 100.0
#define USB_ADC_OUTPUT_RATE 10.0

#define BT_ENV_OUTPUT_RATE 5.0
#define BT_GPS_OUTPUT_RATE 1.0
#define BT_IMU_OUTPUT_RATE 30.0
#define BT_RANGE_OUTPUT_RATE 5.0

extern volatile uint8_t set_connectable;
extern volatile int connected;
volatile uint8_t adcFinished = 1;
SensorState_t sensor;

typedef struct Task_Data
{
  uint32_t period;
  uint32_t previous;
  BOOL echo;
} Task_Data;

/**
 * Check if it is time to run a task
 */
static uint32_t taskTimeout(Task_Data *data, TIM_HandleTypeDef *tim)
{
  uint32_t deltaTime = tim->Instance->CNT - data->previous;
  if (deltaTime >= data->period)
  {
    // If deadline has passed more than once add the period multiple times
    // to avoid running the task many times. We don't want to add deltaTime,
    // since this would result in drift
    int k = deltaTime / data->period;
    data->previous += k * data->period;
    return deltaTime;
  }
  return 0;
}

static Task_Data imuSampleTask = { .period = (uint32_t) (1000000.0 / IMU_SAMPLE_RATE) };
static Task_Data envSampleTask = { .period = (uint32_t) (1000000.0 / ENV_SAMPLE_RATE) };
static Task_Data adcSampleTask = { .period = (uint32_t) (1000000.0 / ADC_SAMPLE_RATE) };
static Task_Data rangeSampleTask = { .period = (uint32_t) (1000000.0 / RANGE_SAMPLE_RATE) };
static Task_Data usbEnvOutputTask = { .period = (uint32_t) (1000000.0 / USB_ENV_OUTPUT_RATE) };
static Task_Data usbGpsOutputTask = { .period = (uint32_t) (1000000.0 / USB_GPS_OUTPUT_RATE) };
static Task_Data usbImuOutputTask = { .period = (uint32_t) (1000000.0 / USB_IMU_OUTPUT_RATE) };
static Task_Data usbRangeOutputTask = { .period = (uint32_t) (1000000.0 / USB_RANGE_OUTPUT_RATE) };
static Task_Data usbMatlabOutputTask = { .period = (uint32_t) (1000000.0 / USB_MATLAB_OUTPUT_RATE) };
static Task_Data usbAdcOutputTask = { .period = (uint32_t) (1000000.0 / USB_MATLAB_OUTPUT_RATE) };
static Task_Data btEnvOutputTask = { .period = (uint32_t) (1000000.0 / BT_ENV_OUTPUT_RATE) };
static Task_Data btGpsOutputTask = { .period = (uint32_t) (1000000.0 / BT_GPS_OUTPUT_RATE) };
static Task_Data btImuOutputTask = { .period = (uint32_t) (1000000.0 / BT_IMU_OUTPUT_RATE) };
static Task_Data btRangeOutputTask = { .period = (uint32_t) (1000000.0 / BT_RANGE_OUTPUT_RATE) };
/* USER CODE END PV */

void SystemClock_Config(void);
static void MX_GPIO_Init(void);
static void MX_DMA_Init(void);
static void MX_USART2_UART_Init(void);
static void MX_SPI1_Init(void);
static void MX_USART1_UART_Init(void);
static void MX_I2C1_Init(void);
static void MX_TIM2_Init(void);
static void MX_ADC1_Init(void);

/* USER CODE BEGIN 0 */
void HAL_ADCEx_InjectedConvCpltCallback(ADC_HandleTypeDef* hadc)
{
  // ADC has finished reading and converting the values on the four pins
  sensor.load.cell0 = ((float) HAL_ADCEx_InjectedGetValue(&hadc1, ADC_INJECTED_RANK_1)) / 4096.0 * 100;
  sensor.load.cell1 = ((float) HAL_ADCEx_InjectedGetValue(&hadc1, ADC_INJECTED_RANK_2)) / 4096.0 * 100;
  adcFinished = 1;
}

void User_Process(void)
{
  if (set_connectable)
  {
    setConnectable();
    set_connectable = FALSE;
  }
}

static void SetEcho(BOOL echo, Task_Data *task)
{
  task->echo = echo;
  task->previous = htim2.Instance->CNT - task->period;
}

void IMUecho(BOOL echo)
{
  SetEcho(echo, &usbImuOutputTask);
}

void GPSecho(BOOL echo)
{
  SetEcho(echo, &usbGpsOutputTask);
}

void ENVecho(BOOL echo)
{
  SetEcho(echo, &usbEnvOutputTask);
}

void RangeEcho(BOOL echo)
{
  SetEcho(echo, &usbRangeOutputTask);
}

void MATLABecho(BOOL echo)
{
  SetEcho(echo, &usbMatlabOutputTask);
}

void ADCecho(BOOL echo)
{
  SetEcho(echo, &usbAdcOutputTask);
}

/**
 * @brief  EXTI line detection callback.
 * @param  Specifies the pins connected EXTI line
 * @retval None
 */
void HAL_GPIO_EXTI_Callback(uint16_t GPIO_Pin)
{
  switch (GPIO_Pin)
  {
  case BNRG_SPI_EXTI_Pin:
    HCI_Isr();
    break;
  case USER_BUTTON_Pin:
    printf("Button pressed\r\n");
    break;
  default:
    break;
  }
}

static void GetBatteryTimeToEmptyAndPercentCharge(uint16_t* timeToEmpty, uint16_t* percentCharge)
{
  // For some reason we need to lower the baud rate to 5000k
  // to communicate with BQ28Z610.
  while (HAL_I2C_GetState(&hi2c1) == HAL_I2C_STATE_BUSY)
    ;
  if (HAL_I2C_DeInit(&hi2c1) != HAL_OK)
  {
    _Error_Handler(__FILE__, __LINE__);
  }
  hi2c1.Init.ClockSpeed = 5000;
  if (HAL_I2C_Init(&hi2c1) != HAL_OK)
  {
    _Error_Handler(__FILE__, __LINE__);
  }
  while (HAL_I2C_GetState(&hi2c1) == HAL_I2C_STATE_BUSY)
    ;
  // Read the BQ28Z610 (0xAA) register RelativeStateOfCharge (0x2C) (in percent)
  *percentCharge = 0;
  HAL_I2C_Mem_Read(&hi2c1, 0xAA, (uint16_t) 0x2C, 1, (uint8_t *) percentCharge, 1, 0x1000);
  while (HAL_I2C_GetState(&hi2c1) == HAL_I2C_STATE_BUSY);

  // Read the BQ28Z610 (0xAA) register AverageTimeToEmpty (0x16) (in minutes)
  HAL_I2C_Mem_Read(&hi2c1, 0xAA, (uint16_t) 0x16, 1, (uint8_t *) timeToEmpty, 2, 0x1000);

  // Reset to 400k baud rate
  if (HAL_I2C_DeInit(&hi2c1) != HAL_OK)
  {
    _Error_Handler(__FILE__, __LINE__);
  }
  while (HAL_I2C_GetState(&hi2c1) == HAL_I2C_STATE_BUSY)
    ;
  hi2c1.Init.ClockSpeed = MAIN_I2C_SPEED;
  MX_I2C1_Init();
  while (HAL_I2C_GetState(&hi2c1) == HAL_I2C_STATE_BUSY)
    ;
}

/* USER CODE END 0 */

int main(void)
{

  /* USER CODE BEGIN 1 */
  SensorAxes_t ACC_Value; /*!< Acceleration Value */
  SensorAxes_t GYR_Value; /*!< Gyroscope Value */
  SensorAxes_t MAG_Value; /*!< Magnetometer Value */
  memset(&sensor, 0, sizeof(SensorState_t));
  memset(&ACC_Value, 0, sizeof(ACC_Value));
  memset(&GYR_Value, 0, sizeof(GYR_Value));
  memset(&MAG_Value, 0, sizeof(MAG_Value));
  /* USER CODE END 1 */

  /* MCU Configuration----------------------------------------------------------*/

  /* Reset of all peripherals, Initializes the Flash interface and the Systick. */
  HAL_Init();

  /* Configure the system clock */
  SystemClock_Config();

  /* Initialize all configured peripherals */
  MX_GPIO_Init();
  MX_DMA_Init();
  MX_USART2_UART_Init();
  MX_SPI1_Init();
  MX_USART1_UART_Init();
  MX_I2C1_Init();
  MX_TIM2_Init();
  MX_ADC1_Init();

  /* USER CODE BEGIN 2 */
  SerialInit(&huart2, &huart1);

  /* Configure Bluetooth GATT server */
  BTinit();

  /* ADC (not currently used) */
  HAL_ADC_Start(&hadc1);

  /* Configure LED2 */
  BSP_LED_Init(LED2);
  /* Configure the User Button in GPIO Mode */
  BSP_PB_Init(BUTTON_KEY, BUTTON_MODE_GPIO);

  /* Configure the system clock */
  SystemClock_Config();

  /* GPS */
  GPSinit();

  /* IMU */
  IMUinit();
  MadgwickInit(IMU_SAMPLE_RATE);

  /* Range */
  VL53L0X_Dev_t rangeDev = { .Id = 0, .I2cHandle = &hi2c1, .I2cDevAddr = 0x52 };
  Range_Sensor_Init(&rangeDev);
  RangingConfig_e rangingConfig = LONG_RANGE;
  Range_Sensor_Setup_Single_Shot(&rangeDev, rangingConfig);
  VL53L0X_RangingMeasurementData_t rangeData;

  // Start the task timer
  HAL_TIM_Base_Init(&htim2);
  HAL_TIM_Base_Start(&htim2);

  /* USER CODE END 2 */

  /* Infinite loop */
  /* USER CODE BEGIN WHILE */
  while (1)
  {
    /* USER CODE END WHILE */

    /* USER CODE BEGIN 3 */
    HCI_Process();
    User_Process();

    /*** INPUTS ***/
    if (taskTimeout(&imuSampleTask, &htim2))
    {
      // Update the IMU
      Accelero_Sensor_Handler(&ACC_Value);
      Gyro_Sensor_Handler(&GYR_Value);
      Magneto_Sensor_Handler(&MAG_Value);

#ifdef BOARD_REV2
      sensor.imu.gx = ((float) GYR_Value.AXIS_X) / 1000;
      sensor.imu.gy = ((float) GYR_Value.AXIS_Y) / 1000;
      sensor.imu.gz = ((float) GYR_Value.AXIS_Z) / 1000;
      sensor.imu.ax = ((float) ACC_Value.AXIS_X) / 1000;
      sensor.imu.ay = ((float) ACC_Value.AXIS_Y) / 1000;
      sensor.imu.az = ((float) ACC_Value.AXIS_Z) / 1000;
      sensor.imu.my = (((float) MAG_Value.AXIS_X) - MAG_X_BIAS) * MAG_X_SCL / 1000;
      sensor.imu.mx = (((float) MAG_Value.AXIS_Y) - MAG_Y_BIAS) * MAG_Y_SCL / 1000; // LSM6DSL has opposite y-axis compared to LSM303 on IMU board
      sensor.imu.mz = (((float) MAG_Value.AXIS_Z) - MAG_Z_BIAS) * MAG_Z_SCL / 1000;
#else
      sensor.imu.gx = ((float) GYR_Value.AXIS_X) / 1000;
      sensor.imu.gy = ((float) GYR_Value.AXIS_Y) / 1000;
      sensor.imu.gz = ((float) GYR_Value.AXIS_Z) / 1000;
      sensor.imu.ax = ((float) ACC_Value.AXIS_X) / 1000;
      sensor.imu.ay = ((float) ACC_Value.AXIS_Y) / 1000;
      sensor.imu.az = ((float) ACC_Value.AXIS_Z) / 1000;
      sensor.imu.my = (((float) MAG_Value.AXIS_X) - MAG_X_BIAS) * MAG_X_SCL / 1000;
      sensor.imu.mx = (((float) MAG_Value.AXIS_Y) - MAG_Y_BIAS) * MAG_Y_SCL / 1000; // LSM6DSL has opposite y-axis compared to LSM303 on IMU board
      sensor.imu.mz = (((float) MAG_Value.AXIS_Z) - MAG_Z_BIAS) * MAG_Z_SCL / 1000;
#endif

      MadgwickUpdate(sensor.imu.gx, sensor.imu.gy, sensor.imu.gz, sensor.imu.ax, sensor.imu.ay, sensor.imu.az, sensor.imu.mx, sensor.imu.my, sensor.imu.mz);
      sensor.imu.roll = MadgwickGetRoll();
      sensor.imu.pitch = -MadgwickGetPitch();
      sensor.imu.yaw = -MadgwickGetYaw();
    }
    if (taskTimeout(&envSampleTask, &htim2))
    {
      // Update environment sensors
      Pressure_Sensor_Handler(&sensor.env.pressure);
      Humidity_Sensor_Handler(&sensor.env.humidity);
      Temperature_Sensor_Handler(&sensor.env.temperature);
    }
    if (adcFinished && (taskTimeout(&adcSampleTask, &htim2)))
    {
      // Update ADC
      HAL_ADCEx_InjectedStart_IT(&hadc1);
      adcFinished = 0;
    }
    if (taskTimeout(&rangeSampleTask, &htim2))
    {
      // Get previous range measurement
      if (Range_Sensor_Get_Measurement(&rangeDev, &rangeData) == VL53L0X_ERROR_NONE)
      {
        // Filtered distance in cm
        sensor.range.range0 = (rangeData.RangeStatus == 0) ? (int) rangeDev.LeakyRange / 10 : INFINITY;
      }
      // Start new range measurement
      Range_Sensor_Start_New_Measurement(&rangeDev, &rangeData);
    }

    /*** OUTPUTS ***/
    if (taskTimeout(&btImuOutputTask, &htim2))
    {
      // Update orientation, GPS and environmental data on Bluetooth GATT server
      Orientation_Update(sensor.imu.roll, sensor.imu.pitch, sensor.imu.yaw);
    }
    if (taskTimeout(&btGpsOutputTask, &htim2))
    {
      uint16_t percentCharge, timeToEmpty;
      GetBatteryTimeToEmptyAndPercentCharge(&timeToEmpty, &percentCharge);
      sensor.gps.info.batteryPercentCharge = percentCharge;
      sensor.gps.info.batteryTimeToEmpty = timeToEmpty;
      Bat_Update(sensor.gps.info.batteryPercentCharge, sensor.gps.info.batteryTimeToEmpty);

      // To avoid race conditions, disable GPS update while reading
      HAL_NVIC_DisableIRQ(GPS_USART_IRQn);
      GPS_Update(sensor.gps.pos.longitude, sensor.gps.pos.latitude, sensor.gps.pos.elevation, sensor.gps.pos.speed, sensor.gps.pos.direction);
      HAL_NVIC_EnableIRQ(GPS_USART_IRQn);
    }
    if (taskTimeout(&btEnvOutputTask, &htim2))
    {
      Temp_Update(sensor.env.temperature);
      Humidity_Update(sensor.env.humidity);
      Press_Update(sensor.load.cell0, sensor.load.cell1);
    }
    if (taskTimeout(&btRangeOutputTask, &htim2))
    {
      Range_Update(sensor.range.range0);
    }
    if (usbImuOutputTask.echo && taskTimeout(&usbImuOutputTask, &htim2))
    {
      printf("%3.4f %3.4f %3.4f\r\n", sensor.imu.roll, sensor.imu.pitch, sensor.imu.yaw);
//      printf("%3.4f %3.4f %3.4f\r\n", sensor.imu.mx, sensor.imu.my, sensor.imu.mz);
    }
    if (usbGpsOutputTask.echo && taskTimeout(&usbGpsOutputTask, &htim2))
    {
      // To avoid race conditions, disable GPS update while reading
      HAL_NVIC_DisableIRQ(GPS_USART_IRQn);
      printf("date %d/%d %d, time %d:%d, lat %f, lon %f, elv %f, speed %f, dir %f satuse %d, satview %d, bat %f, %f min\r\n",
          sensor.gps.time.day,
          sensor.gps.time.month,
          sensor.gps.time.year, sensor.gps.time.hour, sensor.gps.time.min, sensor.gps.pos.latitude, sensor.gps.pos.longitude, sensor.gps.pos.elevation,
          sensor.gps.pos.speed, sensor.gps.pos.direction, sensor.gps.info.satUse, sensor.gps.info.satView, sensor.gps.info.batteryPercentCharge, sensor.gps.info.batteryTimeToEmpty);
      HAL_NVIC_EnableIRQ(GPS_USART_IRQn);
    }
    if (usbEnvOutputTask.echo && taskTimeout(&usbEnvOutputTask, &htim2))
    {
      printf("humidity %3.4f, pressure %3.4f, temperature %3.4f\r\n", sensor.env.humidity, sensor.env.pressure, sensor.env.temperature);
    }
    if (usbRangeOutputTask.echo && taskTimeout(&usbRangeOutputTask, &htim2))
    {
      if (sensor.range.range0 < INFINITY)
        printf("range %f cm\n", sensor.range.range0);
      else
        printf("range ∞\n");
    }
    if (usbMatlabOutputTask.echo && taskTimeout(&usbMatlabOutputTask, &htim2))
    {
      HAL_NVIC_DisableIRQ(GPS_USART_IRQn);
      SerialUsbTransmit((char*) &sensor, sizeof(sensor));
      HAL_NVIC_EnableIRQ(GPS_USART_IRQn);
      char sync[] = { 0xff, 0xff, 0xff, 0xff };
      SerialUsbTransmit(sync, 4);
    }
    if (usbAdcOutputTask.echo && taskTimeout(&usbAdcOutputTask, &htim2))
    {
      while (!adcFinished)
      {
      }
      printf("adc %3.4f, %3.4f\r\n", sensor.load.cell0, sensor.load.cell1);
    }
  }
  /* USER CODE END 3 */

}

/** System Clock Configuration
 */
void SystemClock_Config(void)
{

  RCC_OscInitTypeDef RCC_OscInitStruct;
  RCC_ClkInitTypeDef RCC_ClkInitStruct;

  /**Configure the main internal regulator output voltage
   */
  __HAL_RCC_PWR_CLK_ENABLE()
  ;

  __HAL_PWR_VOLTAGESCALING_CONFIG(PWR_REGULATOR_VOLTAGE_SCALE1);

  /**Initializes the CPU, AHB and APB busses clocks
   */
  RCC_OscInitStruct.OscillatorType = RCC_OSCILLATORTYPE_HSE;
  RCC_OscInitStruct.HSEState = RCC_HSE_ON;
  RCC_OscInitStruct.PLL.PLLState = RCC_PLL_ON;
  RCC_OscInitStruct.PLL.PLLSource = RCC_PLLSOURCE_HSE;
  RCC_OscInitStruct.PLL.PLLM = 8;
  RCC_OscInitStruct.PLL.PLLN = 400;
  RCC_OscInitStruct.PLL.PLLP = RCC_PLLP_DIV4;
  RCC_OscInitStruct.PLL.PLLQ = 4;
  if (HAL_RCC_OscConfig(&RCC_OscInitStruct) != HAL_OK)
  {
    _Error_Handler(__FILE__, __LINE__);
  }

  /**Initializes the CPU, AHB and APB busses clocks
   */
  RCC_ClkInitStruct.ClockType = RCC_CLOCKTYPE_HCLK | RCC_CLOCKTYPE_SYSCLK | RCC_CLOCKTYPE_PCLK1 | RCC_CLOCKTYPE_PCLK2;
  RCC_ClkInitStruct.SYSCLKSource = RCC_SYSCLKSOURCE_PLLCLK;
  RCC_ClkInitStruct.AHBCLKDivider = RCC_SYSCLK_DIV1;
  RCC_ClkInitStruct.APB1CLKDivider = RCC_HCLK_DIV2;
  RCC_ClkInitStruct.APB2CLKDivider = RCC_HCLK_DIV1;

  if (HAL_RCC_ClockConfig(&RCC_ClkInitStruct, FLASH_LATENCY_3) != HAL_OK)
  {
    _Error_Handler(__FILE__, __LINE__);
  }

  /**Configure the Systick interrupt time
   */
  HAL_SYSTICK_Config(HAL_RCC_GetHCLKFreq() / 1000);

  /**Configure the Systick
   */
  HAL_SYSTICK_CLKSourceConfig(SYSTICK_CLKSOURCE_HCLK);

  /* SysTick_IRQn interrupt configuration */
  HAL_NVIC_SetPriority(SysTick_IRQn, 0, 0);
}

/* ADC1 init function */
static void MX_ADC1_Init(void)
{

  ADC_ChannelConfTypeDef sConfig;
  ADC_InjectionConfTypeDef sConfigInjected;

  /**Configure the global features of the ADC (Clock, Resolution, Data Alignment and number of conversion)
   */
  hadc1.Instance = ADC1;
  hadc1.Init.ClockPrescaler = ADC_CLOCK_SYNC_PCLK_DIV4;
  hadc1.Init.Resolution = ADC_RESOLUTION_12B;
  hadc1.Init.ScanConvMode = ENABLE;
  hadc1.Init.ContinuousConvMode = DISABLE;
  hadc1.Init.DiscontinuousConvMode = DISABLE;
  hadc1.Init.ExternalTrigConvEdge = ADC_EXTERNALTRIGCONVEDGE_NONE;
  hadc1.Init.ExternalTrigConv = ADC_SOFTWARE_START;
  hadc1.Init.DataAlign = ADC_DATAALIGN_RIGHT;
  hadc1.Init.NbrOfConversion = 2;
  hadc1.Init.DMAContinuousRequests = ENABLE;
  hadc1.Init.EOCSelection = ADC_EOC_SEQ_CONV;
  if (HAL_ADC_Init(&hadc1) != HAL_OK)
  {
    _Error_Handler(__FILE__, __LINE__);
  }

  /**Configure for the selected ADC regular channel its corresponding rank in the sequencer and its sample time.
   */
  sConfig.Channel = ADC_CHANNEL_14;
  sConfig.Rank = 1;
  sConfig.SamplingTime = ADC_SAMPLETIME_28CYCLES;
  if (HAL_ADC_ConfigChannel(&hadc1, &sConfig) != HAL_OK)
  {
    _Error_Handler(__FILE__, __LINE__);
  }

  /**Configure for the selected ADC regular channel its corresponding rank in the sequencer and its sample time.
   */
  sConfig.Channel = ADC_CHANNEL_15;
  sConfig.Rank = 2;
  if (HAL_ADC_ConfigChannel(&hadc1, &sConfig) != HAL_OK)
  {
    _Error_Handler(__FILE__, __LINE__);
  }

  /**Configures for the selected ADC injected channel its corresponding rank in the sequencer and its sample time
   */
  sConfigInjected.InjectedChannel = ADC_CHANNEL_14;
  sConfigInjected.InjectedRank = 1;
  sConfigInjected.InjectedNbrOfConversion = 2;
  sConfigInjected.InjectedSamplingTime = ADC_SAMPLETIME_28CYCLES;
  sConfigInjected.ExternalTrigInjecConvEdge = ADC_EXTERNALTRIGINJECCONVEDGE_NONE;
  sConfigInjected.ExternalTrigInjecConv = ADC_INJECTED_SOFTWARE_START;
  sConfigInjected.AutoInjectedConv = DISABLE;
  sConfigInjected.InjectedDiscontinuousConvMode = DISABLE;
  sConfigInjected.InjectedOffset = 0;
  if (HAL_ADCEx_InjectedConfigChannel(&hadc1, &sConfigInjected) != HAL_OK)
  {
    _Error_Handler(__FILE__, __LINE__);
  }

  /**Configures for the selected ADC injected channel its corresponding rank in the sequencer and its sample time
   */
  sConfigInjected.InjectedChannel = ADC_CHANNEL_15;
  sConfigInjected.InjectedRank = 2;
  if (HAL_ADCEx_InjectedConfigChannel(&hadc1, &sConfigInjected) != HAL_OK)
  {
    _Error_Handler(__FILE__, __LINE__);
  }

}

/* I2C1 init function */
static void MX_I2C1_Init(void)
{

  hi2c1.Instance = I2C1;
  hi2c1.Init.ClockSpeed = MAIN_I2C_SPEED;
  hi2c1.Init.DutyCycle = I2C_DUTYCYCLE_2;
  hi2c1.Init.OwnAddress1 = 0;
  hi2c1.Init.AddressingMode = I2C_ADDRESSINGMODE_7BIT;
  hi2c1.Init.DualAddressMode = I2C_DUALADDRESS_DISABLE;
  hi2c1.Init.OwnAddress2 = 0;
  hi2c1.Init.GeneralCallMode = I2C_GENERALCALL_DISABLE;
  hi2c1.Init.NoStretchMode = I2C_NOSTRETCH_DISABLE;
  if (HAL_I2C_Init(&hi2c1) != HAL_OK)
  {
    _Error_Handler(__FILE__, __LINE__);
  }

}

/* SPI1 init function */
static void MX_SPI1_Init(void)
{

  /* SPI1 parameter configuration*/
  hspi1.Instance = SPI1;
  hspi1.Init.Mode = SPI_MODE_MASTER;
  hspi1.Init.Direction = SPI_DIRECTION_2LINES;
  hspi1.Init.DataSize = SPI_DATASIZE_8BIT;
  hspi1.Init.CLKPolarity = SPI_POLARITY_LOW;
  hspi1.Init.CLKPhase = SPI_PHASE_1EDGE;
  hspi1.Init.NSS = SPI_NSS_SOFT;
  hspi1.Init.BaudRatePrescaler = SPI_BAUDRATEPRESCALER_256;
  hspi1.Init.FirstBit = SPI_FIRSTBIT_MSB;
  hspi1.Init.TIMode = SPI_TIMODE_DISABLE;
  hspi1.Init.CRCCalculation = SPI_CRCCALCULATION_DISABLE;
  hspi1.Init.CRCPolynomial = 10;
  if (HAL_SPI_Init(&hspi1) != HAL_OK)
  {
    _Error_Handler(__FILE__, __LINE__);
  }

}

/* TIM2 init function */
static void MX_TIM2_Init(void)
{

  TIM_ClockConfigTypeDef sClockSourceConfig;
  TIM_MasterConfigTypeDef sMasterConfig;

  htim2.Instance = TIM2;
  htim2.Init.Prescaler = 99;
  htim2.Init.CounterMode = TIM_COUNTERMODE_UP;
  htim2.Init.Period = 0xffffffff;
  htim2.Init.ClockDivision = TIM_CLOCKDIVISION_DIV1;
  if (HAL_TIM_Base_Init(&htim2) != HAL_OK)
  {
    _Error_Handler(__FILE__, __LINE__);
  }

  sClockSourceConfig.ClockSource = TIM_CLOCKSOURCE_INTERNAL;
  if (HAL_TIM_ConfigClockSource(&htim2, &sClockSourceConfig) != HAL_OK)
  {
    _Error_Handler(__FILE__, __LINE__);
  }

  sMasterConfig.MasterOutputTrigger = TIM_TRGO_RESET;
  sMasterConfig.MasterSlaveMode = TIM_MASTERSLAVEMODE_DISABLE;
  if (HAL_TIMEx_MasterConfigSynchronization(&htim2, &sMasterConfig) != HAL_OK)
  {
    _Error_Handler(__FILE__, __LINE__);
  }

}

/* USART1 init function */
static void MX_USART1_UART_Init(void)
{

  huart1.Instance = USART1;
  huart1.Init.BaudRate = 4800;
  huart1.Init.WordLength = UART_WORDLENGTH_8B;
  huart1.Init.StopBits = UART_STOPBITS_1;
  huart1.Init.Parity = UART_PARITY_NONE;
  huart1.Init.Mode = UART_MODE_TX_RX;
  huart1.Init.HwFlowCtl = UART_HWCONTROL_NONE;
  huart1.Init.OverSampling = UART_OVERSAMPLING_16;
  if (HAL_UART_Init(&huart1) != HAL_OK)
  {
    _Error_Handler(__FILE__, __LINE__);
  }

}
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

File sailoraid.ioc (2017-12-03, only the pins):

Mcu.UserName=STM32F411RETx
PA0-WKUP.GPIO_Label=BNRG_SPI_IRQ
PA0-WKUP.Signal=GPXTI0
PA1.GPIO_Label=BNRG_SPI_CS
PA1.Signal=GPIO_Output
PA10.GPIO_Label=GPS_USART_RX
PA10.Signal=USART1_RX
PA11.GPIO_Label=GPS_ON_OFF
PA11.Signal=GPIO_Output
PA13.GPIO_Label=TMS
PA13.Signal=SYS_JTMS-SWDIO
PA14.GPIO_Label=TCK
PA14.Signal=SYS_JTCK-SWCLK
PA2.GPIO_Label=USB_USART_TX
PA2.Signal=USART2_TX
PA3.GPIO_Label=USB_USART_RX
PA3.Signal=USART2_RX
PA5.GPIO_Label=LED2
PA5.Signal=GPIO_Output
PA6.GPIO_Label=BNRG_SPI_MISO
PA6.Signal=SPI1_MISO
PA7.GPIO_Label=BNRG_SPI_MOSI
PA7.Signal=SPI1_MOSI
PA8.GPIO_Label=BNRG_SPI_RESET
PA8.Signal=GPIO_Output
PA9.GPIO_Label=GPS_USART_TX
PA9.Signal=USART1_TX
PB10.GPIO_Label=LPS22H_INT1_O
PB10.Signal=GPXTI10
PB3.GPIO_Label=BNRG_SPI_SCLK
PB3.Signal=SPI1_SCK
PB4.GPIO_Label=LSM6DSL_INT1_O
PB4.Signal=GPXTI4
PB5.GPIO_Label=LSM6DSL_INT2_O
PB5.Signal=GPXTI5
PB8.GPIO_Label=I2C_SCL
PB8.Signal=I2C1_SCL
PB9.GPIO_Label=I2C_SDA
PB9.Signal=I2C1_SDA
PC1.GPIO_Label=GPS_NRST
PC1.Signal=GPIO_Output
PC13-ANTI_TAMP.GPIO_Label=USER_BUTTON
PC13-ANTI_TAMP.Signal=GPXTI13
PC14-OSC32_IN.Signal=RCC_OSC32_IN
PC15-OSC32_OUT.Signal=RCC_OSC32_OUT
PC4.GPIO_Label=LOAD_CELL_0_ADC
PC4.Signal=ADCx_IN14
PC5.GPIO_Label=LOAD_CELL_1_ADC
PC5.Signal=ADCx_IN15
PC9.GPIO_Label=RANGE_SHDN
PC9.Signal=GPIO_Output

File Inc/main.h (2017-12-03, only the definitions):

#define MAIN_I2C_SPEED 400000
#define USER_BUTTON_Pin GPIO_PIN_13
#define USER_BUTTON_GPIO_Port GPIOC
#define USER_BUTTON_EXTI_IRQn EXTI15_10_IRQn
#define GPS_NRST_Pin GPIO_PIN_1
#define GPS_NRST_GPIO_Port GPIOC
#define BNRG_SPI_IRQ_Pin GPIO_PIN_0
#define BNRG_SPI_IRQ_GPIO_Port GPIOA
#define BNRG_SPI_IRQ_EXTI_IRQn EXTI0_IRQn
#define BNRG_SPI_CS_Pin GPIO_PIN_1
#define BNRG_SPI_CS_GPIO_Port GPIOA
#define USB_USART_TX_Pin GPIO_PIN_2
#define USB_USART_TX_GPIO_Port GPIOA
#define USB_USART_RX_Pin GPIO_PIN_3
#define USB_USART_RX_GPIO_Port GPIOA
#define LED2_Pin GPIO_PIN_5
#define LED2_GPIO_Port GPIOA
#define BNRG_SPI_MISO_Pin GPIO_PIN_6
#define BNRG_SPI_MISO_GPIO_Port GPIOA
#define BNRG_SPI_MOSI_Pin GPIO_PIN_7
#define BNRG_SPI_MOSI_GPIO_Port GPIOA
#define LOAD_CELL_0_ADC_Pin GPIO_PIN_4
#define LOAD_CELL_0_ADC_GPIO_Port GPIOC
#define LOAD_CELL_1_ADC_Pin GPIO_PIN_5
#define LOAD_CELL_1_ADC_GPIO_Port GPIOC
#define LPS22H_INT1_O_Pin GPIO_PIN_10
#define LPS22H_INT1_O_GPIO_Port GPIOB
#define LPS22H_INT1_O_EXTI_IRQn EXTI15_10_IRQn
#define RANGE_SHDN_Pin GPIO_PIN_9
#define RANGE_SHDN_GPIO_Port GPIOC
#define BNRG_SPI_RESET_Pin GPIO_PIN_8
#define BNRG_SPI_RESET_GPIO_Port GPIOA
#define GPS_USART_TX_Pin GPIO_PIN_9
#define GPS_USART_TX_GPIO_Port GPIOA
#define GPS_USART_RX_Pin GPIO_PIN_10
#define GPS_USART_RX_GPIO_Port GPIOA
#define GPS_ON_OFF_Pin GPIO_PIN_11
#define GPS_ON_OFF_GPIO_Port GPIOA
#define TMS_Pin GPIO_PIN_13
#define TMS_GPIO_Port GPIOA
#define TCK_Pin GPIO_PIN_14
#define TCK_GPIO_Port GPIOA
#define BNRG_SPI_SCLK_Pin GPIO_PIN_3
#define BNRG_SPI_SCLK_GPIO_Port GPIOB
#define LSM6DSL_INT1_O_Pin GPIO_PIN_4
#define LSM6DSL_INT1_O_GPIO_Port GPIOB
#define LSM6DSL_INT1_O_EXTI_IRQn EXTI4_IRQn
#define LSM6DSL_INT2_O_Pin GPIO_PIN_5
#define LSM6DSL_INT2_O_GPIO_Port GPIOB
#define LSM6DSL_INT2_O_EXTI_IRQn EXTI9_5_IRQn
#define I2C_SCL_Pin GPIO_PIN_8
#define I2C_SCL_GPIO_Port GPIOB
#define I2C_SDA_Pin GPIO_PIN_9
#define I2C_SDA_GPIO_Port GPIOB
#define GPS_NRST_Pin GPIO_PIN_1
#define GPS_NRST_GPIO_Port GPIOC
#define GPS_ON_OFF_Pin GPIO_PIN_11
#define GPS_ON_OFF_GPIO_Port GPIOA
#define GPS_NRST_Pin GPIO_PIN_0
#define GPS_NRST_GPIO_Port GPIOC
#define GPS_ON_OFF_Pin GPIO_PIN_7
#define GPS_ON_OFF_GPIO_Port GPIOC
#define GPS_USART_IRQn USART1_IRQn
#define RTC_ASYNCH_PREDIV_LSI  0x7F
#define RTC_SYNCH_PREDIV_LSI   0xF9
#define RTC_ASYNCH_PREDIV_LSE  0x7F
#define RTC_SYNCH_PREDIV_LSE   0x00FF
#define BNRG_SPI_EXTI_IRQn BNRG_SPI_IRQ_EXTI_IRQn
#define BNRG_SPI_INSTANCE		SPI1
#define BNRG_SPI_MODE			SPI_MODE_MASTER
#define BNRG_SPI_DIRECTION		SPI_DIRECTION_2LINES
#define BNRG_SPI_DATASIZE		SPI_DATASIZE_8BIT
#define BNRG_SPI_CLKPOLARITY		SPI_POLARITY_LOW
#define BNRG_SPI_CLKPHASE	        SPI_PHASE_1EDGE
#define BNRG_SPI_NSS			SPI_NSS_SOFT
#define BNRG_SPI_FIRSTBIT	        SPI_FIRSTBIT_MSB
#define BNRG_SPI_TIMODE		        SPI_TIMODE_DISABLED
#define BNRG_SPI_CRCPOLYNOMIAL	        7
#define BNRG_SPI_BAUDRATEPRESCALER      SPI_BAUDRATEPRESCALER_4
#define BNRG_SPI_CRCCALCULATION		SPI_CRCCALCULATION_DISABLED
#define BNRG_SPI_IRQ_ALTERNATE		0
#define BNRG_SPI_IRQ_MODE		GPIO_MODE_IT_RISING
#define BNRG_SPI_IRQ_PULL		GPIO_NOPULL
#define BNRG_SPI_IRQ_SPEED		GPIO_SPEED_HIGH
#define LEDn                                    1
#define BUTTONn                                 1
#define USER_BUTTON_EXTI_IRQn                   EXTI15_10_IRQn
#define BNRG_SPI_EXTI_Pin BNRG_SPI_IRQ_Pin
#define BNRG_SPI_EXTI_GPIO_Port BNRG_SPI_IRQ_GPIO_Port
#define JTAG_SUPPORTED 0 /* if 1 keep debugger enabled while in any low power mode */
#define LOW_POWER_MODE 1 /* 1 = Low Power mode ON, 0 = Low Power Mode OFF */
#define WUCKSEL_DIVIDER (3)		/**< Tick is  (LSI speed clock/2) */
#define RTC_ASYNCH_PRESCALER (1)
#define RTC_SYNCH_PRESCALER (0x7FFF)

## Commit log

2017-08-31 Added generated stm32cubemx files
2017-09-02 Hardware project added
    Added Hardware:
    * Libraries
    o Customs
    - Officials
    * CPU_Board (Main board)
    - Project file
    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
    [CPU_Board.kicad_pcb, CPU_Board.sch]
2017-09-05 GPS, libraries and datasheet list
    GPS: A2235-h added to schematic in UART settings. ON-OFF not finished!
    Libraries:
    - DCDCconv, ft232rl, lm1117, max3485e, stm32 (from kicad std-lib),
    stm32f100, stm32f4.
    * CUSTOM
    - A2235-H
    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
    [CPU_Board.sch]
2017-09-06 GPS proper shut-ON/OFF logic
    Possible solution to support startup/shutdown sequence (GPIO - PA11).
    Might take away filter and add a second logical gate for faster (more
    true digital) switching.
    [CPU_Board.sch]
2017-09-07 Input Voltage Regulator
    With overvoltage protection and revece voltage protection features.
    [PowerSupplySA.kicad_pcb, PowerSupplySA.sch]
2017-09-07 Please keep it clean
    Power supply to it's own folder...
    [PowerSupplySA.kicad_pcb, PowerSupplySA.sch]
2017-09-08 Added IMU Circuit schematic to Hardware
    [IMU_Circuit.kicad_pcb, IMU_Circuit.sch]
2017-09-08 Libs and done first sketch GPS
    Added depleted MOSFET library
    Completed GPS wiring
    [CPU_Board.sch]
2017-09-12 BT SPI busy problem
    [bluenrg_interface.c, main.c, main.h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]
2017-09-12 Removed unused code, fixed warnings
    [main.c, main.h, sailoraid.ioc]
2017-09-14 INA126
    Force sensor schematic
2017-09-14 Shematic merger and stuff
    [CPU_Board.sch, IMU_Circuit.sch, INA1245 amplifier.sch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]
2017-09-17 Acc/gyro LSM6DSL read orientation
2017-09-17 Added BT Schematic to Hardware
    [BT.kicad_pcb, BT.sch]
2017-09-18 Shitload of hardware stuff
    * Added libraries
    * Added footprints
    * Moved stuff and updated local libraries (Hardware ->
    schematic_modules)
    * Drawn some footprints (LGA-14)
    * Edited library (BT had two 5 pin)
    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
    [BT.sch, CPU_Board.kicad_pcb, CPU_Board.sch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]
2017-09-19 Added MadgwickAHRS for IMU code
2017-09-19 IMU works with Processing orientation app
2017-09-19 BT sends real sensor data for temp,press,hum, etc
2017-09-20 PCB v0.1.0
    * Changed components to SMD
    * Added Measurement nodes for all datalines
    * Designed PCB (Rather big now, only a first edition!)
    * "Fixed" fucked up power flags
    [CPU_Board.kicad_pcb, CPU_Board.sch]
2017-09-20 Small PCB update and Manufacturing
    * CPU_Board v0.1.1
    * Manufacturing files (Gerbers, mapping, drill etc.)
    [CPU_Board.kicad_pcb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]
2017-09-20 Refactored code for readability, add ADC gen code
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2017-09-21 Read ADC (load cell pin)
2017-09-21 Send correct euler angles over BT
    [main.c]
2017-09-21 Improved UART handling, print GPS output to terminal
2017-09-22 PCB_Design v0.2
    Added, changed and stuff.
    Libraries and stuff.
    Looks like shit, but it should work.
    Will check later and then send gerbers.
    [CPU_Board.kicad_pcb, CPU_Board.sch]
2017-09-22 Ready to manufacture!
    [CPU_Board.kicad_pcb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]
2017-09-24 Read GPS (NMEA) by UART. Add basic user cmd shell.
2017-09-24 presentation stuff
    [CPU_Board.sch]
2017-09-28 Added range sensor stuff
2017-09-28 Fix problem when sending floats over Bluetooth
    [bluenrg_interface.c, main.c, range.c]
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2017-09-29 Put in correct gps pos when opening map view
    [bluenrg_interface.c, serial.c]
2017-09-30 Environment sensors BT send receive works now
2017-10-01 Better env sensor formatting in app
2017-10-01 Improve UART FIFO handling. Fix issue with timer reset for UART.
    [main.c, serial.c]
2017-10-02 Added next rev PCB todo list
2017-10-02 Added IMU board datasheet
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2017-10-05 Faster sensor logging in MATLAB
2017-10-08 Added rev. 2 Schematic and netlist
    * nRST st to PC0
    * GPS nRST set to PC1
    * Load cell 1 set to PC4
    * Added Load cell 2 set to PC5
    * LPS22HB DRDY set to PB10
    * LPS22HB SA0 set to PB13
    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
    [CPU_Board.kicad_pcb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]
2017-10-10 Log real sensor values
2017-10-10 Fix GPS position format in new NMEA lib
    [gps.c]
2017-10-13 Simple range sensor polling works
2017-10-14 Improve range sensor code, add range module SHDN pin
2017-10-16 Added drift calculations, not tested with board.
2017-10-17 BT sends range sensor value in cm
2017-10-18 Added range, speed and bearing to bt
2017-10-19 Fix project path warning, increase range sensor init delay
    [main.c, range.c]
2017-10-26 Try to restart stalling I2C bus
    [main.c, main.h, sailoraid.ioc]
2017-10-29 PCB Rev 2 on the way
    /Somewhat/ done with the layout
    [CPU_Board.kicad_pcb, CPU_Board.sch]
2017-11-01 Fix I2C reset issue
    [i2c.c]
2017-11-01 Gasgauge schematic
    Gasgauge schematic with buck converter and soft latch power switch
    [2sBatteryCharger.kicad_pcb, 2sBatteryCharger.sch]
2017-11-04 Chackpoint PCB rev2
    * Added datasheets for LSM9DS1 and STEVAL board
    * Drawn footprints for:
    o Connectors (JST)
    o LGA-12_2x2mm "Handsolder friendlier"
    o LGA-24L_3x3.5 "Handsolder friendlier"
    * Drawn symbol for LSM9DS1
    * Fixed GPS A2235-H footprints (normal & Handsolder)
    * Almost completed MCU-board rev2 schematic (Miss connections for
    LSM9DS1)
    * Almost completed MCU-board rev2 PCB layout (Miss the connections for
    LSM and have only designed internal module layout for all IMU/IMU-like
    components.)
    Next steps:
    * Make space for gigantig STEVAL LSM9DS1 DIP24
    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
    [CPU_Board.kicad_pcb, CPU_Board.sch]
2017-11-06 PCB rev2.0 complete-ish
    Rev 2 completed, except for LSM9DS1 ports: "SDO-A/G", "SDO-M" and "Data
    enable A/G"
    [CPU_Board.kicad_pcb, CPU_Board.sch]
2017-11-06 Silkscreen annotations
    Good-ish looking silkscreen~~
    [CPU_Board.kicad_pcb]
2017-11-07 PCB rev2 complete
    [CPU_Board.kicad_pcb, CPU_Board.sch]
2017-11-07 Battery management
    Gasgauge schematic and pcb layout
    [2sBatteryCharger.kicad_pcb, 2sBatteryCharger.sch]
2017-11-09 Complete PCB rev2.1
    Completed, rendered gerbers, rendered drill and order sent to Jan
    refering to myself as his dear friend.
    [CPU_Board-B.Cu.gbr, CPU_Board-B.Mask.gbr, CPU_Board-B.SilkS.gbr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]
2017-11-17 Stuff for rev 3...
    [CPU_Board.kicad_pcb]
2017-11-18 Some sensors comments and edits
2017-11-24 Fixes
    Some fixes (now implemented to the PCB)
    [CPU_Board.kicad_pcb, CPU_Board.sch]
2017-11-24 Added CPU Board rev3
    [CPU_Board-B.Cu.gbr, CPU_Board-B.Mask.gbr, CPU_Board-B.SilkS.gbr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]
2017-11-25 Rev 2 last ed. Rev 3 "merge"
    [CPU_Board-B.Cu.gbr, CPU_Board-B.Mask.gbr, CPU_Board-B.SilkS.gbr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]
2017-11-25 Schematic merge and pcb layout fixes
    All minor bugs now fixed, Next up is Footprint and library errors,
    followed by actual improvements.
    [CPU_Board.kicad_pcb, CPU_Board.sch]
2017-11-27 IMU footprints more solderable
    [CPU_Board.kicad_pcb]
2017-11-29 Adjusted for pcb rev2
2017-12-03 Fix Android pressure and battery reading from BT
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2017-12-03 Fix board rev 2 imu axis directions
    [main.c, main.h]
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2017-12-04 Rev 3 (most stuff)
    [CPU_Board.kicad_pcb, CPU_Board.sch]
2017-12-04 Rev 3 most done commit log
    * Fixed all footprints to HS
    * Updated and reallocated netlist
    * Updated schematics
    * Added rst button
    * worked on PCB layout
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2017-12-06 Revision 3 routed and completed
    * Schematic completed
    * Layout of components complete
    * Routing complete
    * Excessive via placing complete (All potential antennas, no matter how
    slight should have been prevented)
    * Gerbers generated
    * Drill generated
    * A2235 footprint/library fixed
    * Minor other adjustments
    [CPU_Board.kicad_pcb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]
2017-12-06 last fixes
    [CPU_Board.kicad_pcb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]
2017-12-06 last fixes
    * Changed footprints for OPAMPS
    * Rerouted GPS_Vout
    * New gerbers
2018-01-09 Added appendix to report, fixed last error in pcb layout (missing junction)
    [CPU_Board.kicad_pcb, CPU_Board.sch]
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2018-01-09 Some HW report done..
    [CPU_Board.kicad_pcb]
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2018-01-13 BMS KiCad
    [2sBatteryCharger.kicad_pcb, 2sBatteryCharger.sch, bq24133.sch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]
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2018-01-14 Fixed BMS appendix, arranged figures in android.tex
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

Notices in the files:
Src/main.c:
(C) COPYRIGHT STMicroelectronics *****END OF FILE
